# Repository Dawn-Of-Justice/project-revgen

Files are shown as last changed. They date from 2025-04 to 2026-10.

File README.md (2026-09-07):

# RevGen

A voice-controlled replacement for two remote controls, in Malayalam.

Built for a grandmother who knows perfectly well what the television and the
set-top box are — she just cannot tell which of the two remotes does what. She
presses one button, says what she wants, and hears a confirmation.

```
"TV ഓണാക്കുവോ? ഉം. and sound-ഉം കൂടെ കൂട്ടണേ കുറച്ച്."
   → tv.power, wait 2.5s, tv.volume_up ×2
   → "ടിവി ഓണാക്കി. ശബ്ദം കൂട്ടി."
```

That is a real transcript, not an illustration. Saaras handled the code-mixing,
the filler and the polite interrogative ending on the first attempt.

## Where it stands

| Phase | | |
|---|---|---|
| **0 — does it understand her?** | ✅ | Saaras + Sarvam-105B resolve her speech to the right two actions |
| **1 — emitter** | firmware written, protocol verified | needs hardware to flash |
| **2 — backend** | ✅ deployed | `project-revgen.fly.dev`, verified end to end in ~3.9s |
| **3 — handheld** | ✅ **working** | press, speak, understood, spoken reply. OTA updatable. |
| **4 — harden** | not started | enclosure, battery, undo, watchdogs |

The handheld works on real hardware: one press, hold to talk, release, and the
backend returns the right IR plan with a spoken Malayalam confirmation. It
updates over WiFi, so it stays fixable once it is sealed in a case.

**PCB A3 corrects the amplifier for component-side-up mounting.** See the
[correction record](pcb/remote/A3_CORRECTIONS.md). Owned-part fit and charging
measurements remain pending. Use A3 files; A2 is superseded and A1 was rejected.

The 120 x 45 mm rounded remote carrier PCB is routed, with Gerber/drill exports
and zero reported DRC/ERC violations. See [assembly and fabrication files](pcb/README.md). Charging components have not been tested on
the breadboard, and charging-related firmware behavior remains pending. First
charging tests are planned on the PCB prototype.

The emitter firmware is validated against `backend/tools/fake_emitter.py`, which
impersonates it over the real broker using the same validation rules. Physical
IR emission still needs hardware testing, as does the handheld charging path.

Two blockers, both waiting on parts:

- `stb.digit_1` is byte-identical to `channel_down`, a copy-paste bug inherited
  from v1. The backend refuses to fire it rather than changing the channel she
  did not ask for, so any channel containing a 1 is unavailable until the codes
  are recaptured with an IR receiver.
- Every channel number in `config/commands.json` is `null`, so `channel_set`
  correctly refuses everything. That one just needs five minutes with her
  set-top box.

## Layout

| Path | What it is | State |
|---|---|---|
| `backend/` | STT → intent → resolver → MQTT → TTS | **deployed**, 66 tests |
| `Dockerfile`, `fly.toml` | Deploy config, at the root because the image needs `config/` | live |
| `config/commands.json` | IR codes, channels, Malayalam phrases — single source of truth | needs her channel numbers |
| `firmware/selftest/` | Flash to any new board first: PSRAM, flash, WiFi survey | verified |
| `firmware/audiotest/` | Speaker bring-up: tones only, no network | verified |
| `firmware/capture/` | Phase 0 rig: recapture IR codes, sweep for discrete ones | written, untested on hardware |
| `firmware/emitter/` | IR blaster by the TV | written, untested on hardware |
| `firmware/remote/` | The handheld | **working on hardware** |
| `archive/v1/` | Superseded v1 code, kept for provenance | — |
| `docs/` | Pinouts, spec sheet, parts list | — |
| [`ARCHITECTURE.md`](ARCHITECTURE.md) | Why it is built this way, and what was rejected | — |
| [`docs/BOM.md`](docs/BOM.md) | Parts, with the specs that actually matter | ₹355 outstanding |
| [`docs/WIRING.md`](docs/WIRING.md) | Pin assignment, breadboard wiring, bring-up order | — |
| [`docs/PCB.md`](docs/PCB.md) | Carrier board: netlist, footprints, layout rules | routed; DRC/ERC pass; prototype files ready |
| [`docs/netlist.json`](docs/netlist.json) | Same netlist, machine-checkable against the schematic | 17 nets, 75 connections |

## Start here

```bash
cd backend
python -m venv .venv && source .venv/bin/activate   # Windows: .\.venv\Scripts\Activate.ps1
pip install -r requirements-dev.txt
pytest                      # 66 tests, no network or hardware needed
```

With a Sarvam key and broker credentials in `backend/.env`:

```bash
python tools/check_sarvam.py recordings/    # does it understand her?
python tools/fake_emitter.py                # stand in for the hardware
python tools/send_wav.py recordings/01_tv_on__power_on.m4a https://project-revgen.fly.dev/command
```

See [`backend/README.md`](backend/README.md) for the detail.

## Design in one paragraph

The language model never emits button presses — it returns *goals*
(`power_on`, `volume_up`) from a fixed vocabulary, and plain Python turns goals
into IR. That split exists because IR is open-loop and most buttons are toggles:
firing `tv.power` at a television that is already on turns it off, and no model
can know which case it is in. The safety rules that prevent that live in
`backend/app/resolver.py`, which has no I/O and is entirely unit tested.

## A note on secrets

This repo is public. A Groq key was committed in `.env` in April 2025 and had to
be revoked. Credentials now live in gitignored files — `backend/.env` and
`firmware/emitter/secrets.h` — with committed `.example` templates alongside.
Assume anything pushed here is scraped within minutes.

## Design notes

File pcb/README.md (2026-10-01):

# Remote carrier PCB — A3 prototype

> **A3 replaces A2 and rejected A1 files, correcting amplifier component-up mounting.** Mask openings, switch rating, amplifier protection and native schematic parity are corrected. Check owned-part fit before ordering; charging remains untested.

Completed **120 × 45 mm**, rounded R8, two-layer carrier for existing modules.
Fully routed: **0 DRC violations, 0 unconnected items, 0 ERC messages** under
project rules. All 79 logical pad assignments match the schematic.

- [Manufacturing ZIP](remote/RevGen-Remote-A3-Gerbers.zip)
- [KiCad project](remote/remote.kicad_pro), [PCB](remote/remote.kicad_pcb), [schematic](remote/remote.kicad_sch)
- [Assembly instructions](remote/ASSEMBLY.md)
- [A3 amplifier correction](remote/A3_CORRECTIONS.md)
- [Board preview](remote/artifacts/remote-top.png), [1:1 footprint drawing](remote/artifacts/assembly-1to1.svg), [schematic drawing](remote/artifacts/remote.svg)

Core remote operation was verified on breadboard. Charging hardware and charging
firmware remain untested. Compare the owned mic and button with the 1:1 drawing
before ordering; CAD checks do not establish their physical fit.
The separate 24 kHz playback compatibility finding remains open; see
[fresh review](remote/A2_FRESH_REVIEW.md).

The native schematic is authoritative. A2 adds R6 (2.2 kΩ), R7 (10 kΩ), and
a C&K 1101M2S3CQE2 switch. [Correction record](remote/A2_CORRECTIONS.md). Keep `revgen.pretty` and `fp-lib-table`
alongside the project. Superseded manufacturing archives, Trace drafts, routing
intermediates and one-off layout scripts have been removed. The correction and
review records remain as supporting documentation for A3. Final reports are
`artifacts/final-drc.json` and `artifacts/erc.txt`.

Validate from the repository root with KiCad 10 on PATH:

```powershell
kicad-cli sch export netlist --format kicadxml --output pcb/remote/artifacts/netlist.xml pcb/remote/remote.kicad_sch
python pcb/check_netlist.py pcb/remote/artifacts/netlist.xml
kicad-cli sch erc --output pcb/remote/artifacts/erc.txt pcb/remote/remote.kicad_sch
kicad-cli pcb drc --schematic-parity --format json --output pcb/remote/artifacts/final-drc.json pcb/remote/remote.kicad_pcb
& 'C:/Program Files/KiCad/10.0/bin/python.exe' pcb/check_board.py
```

Run `pcb/audit_preorder.py` with KiCad Python to check masks, full parity and
the A3 ZIP against current exports. `pcb/check_amplifier_orientation.py` checks
the module orientation against the retained manufacturer reference.
`pcb/package_a3.py` packages the checked native project and manufacturing exports;
it does not regenerate the layout.

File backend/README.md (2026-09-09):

# RevGen backend

Holds roughly 80% of the system's complexity so that both firmwares can stay
boring. That split is the direct lesson from v1, where the smartest component
was a microcontroller in someone else's house.

```
audio -> Saaras (STT) -> Sarvam-105B (intent) -> resolver -> MQTT -> ack -> Bulbul (cached)
```

**Status: deployed and verified end to end.** Live at
`project-revgen.fly.dev`, one machine in `bom`. A real recording of her voice
returns the correct IR sequence and a spoken Malayalam confirmation.

## Run it locally

```bash
cd backend
python -m venv .venv && source .venv/bin/activate
pip install -r requirements-dev.txt   # requirements.txt alone = runtime only
cp .env.example .env                  # Sarvam key + broker credentials
uvicorn app.main:app --reload
```

No key and no broker? `OFFLINE=true` runs the whole chain with stubs — enough to
check wiring and exercise the resolver.

## Tools

| Script | What it does |
|---|---|
| `tools/check_sarvam.py` | Batch-transcribes a folder of recordings and prints the resolved intents. Scores accuracy if files are named `01_tv_on__power_on.m4a`. |
| `tools/fake_emitter.py` | Impersonates the IR emitter over the real broker: validates commands with the same rules as the firmware, prints each step, publishes an ack. |
| `tools/test_emitter.py` | Tests a catalog button through the backend MQTT client, without speech APIs. Dry-run by default; `--execute` sends to the configured emitter. |
| `tools/send_wav.py` | Posts an audio file at the backend and plays the reply. Saves it as `reply.wav` in the current directory. |
| `tools/build_tts_cache.py` | Pre-generates every Malayalam phrase. Throttled to one request per 2.1s for the bulbul:v3 rate limit. |

## Testing without hardware

**1. Unit tests.** No network, no hardware:

```bash
pytest          # 66 tests
```

**2. Does it understand her?** The go/no-go on the whole premise:

```bash
python tools/check_sarvam.py recordings/
```

Target is 95% intent accuracy. Include three or four recordings with the TV
playing and no command spoken, named `__unknown` — refusing ambient speech is
the failure mode that decides whether this is usable in her living room.

**3. The full chain.** With `MQTT_*` set in `.env`, run the fake emitter in one
terminal and send a recording from another:

```bash
python tools/fake_emitter.py
python tools/send_wav.py recordings/01_tv_on__power_on.m4a https://project-revgen.fly.dev/command
```

The fake emitter prints the decoded IR steps and acks, so the backend returns
the real confirmation rather than `err.emitter_offline`. Everything except the
physical LED is proven at that point.

## Measured latency

Deployed instance, 155KB m4a from a laptop in Kerala:

| | ms |
|---|---|
| Server total | 1,732 |
| — MQTT round trip via Frankfurt | ~160 |
| Network (upload) | 2,158 |
| **End to end** | **3,890** |

Two things this settles. The EU broker costs ~160ms, not the ~500ms feared, so
self-hosting Mosquitto is not worth doing. And **upload dominates** — that test
file is mostly silence, and a tight 2–3s utterance (~96KB at the measured
72KB/s) lands near 3s. Stopping the recording on silence is therefore the
highest-value firmware behaviour, worth more than any backend optimisation.

## Deploy (Fly.io)

`Dockerfile` and `fly.toml` live at the **repo root**, not here — the image
needs `config/commands.json`, which sits outside `backend/` because the emitter
firmware reads the same file. All `fly` commands run from the repo root, since
that is where `fly.toml` is.

Already provisioned: app `project-revgen`, region `bom`, one machine, volume
`revgen_data` mounted at `/data`. Routine redeploy is just:

```bash
fly deploy
```

The backend now defaults to **32 kHz mono PCM16** replies. Both
[Bulbul v3 REST](https://docs.sarvam.ai/api-reference/text-to-speech/convert)
and the [MAX98357A](https://www.analog.com/media/en/technical-documentation/data-sheets/MAX98357A-MAX98357B.pdf)
support 32 kHz; the amplifier does not support the previous 24 kHz clock.
After deploying this change, run `fly ssh console -C "python tools/build_tts_cache.py"`
to warm the new cache before normal use. Settings-aware cache keys bypass old
clips automatically. Check for an existing `TTS_SAMPLE_RATE` environment/secret
override and change it to `32000` if present. Offline silence uses a separate
cache key and cannot replace production speech.

Deployment of this audio change is pending as of 2026-09-08. The production
voice-to-physical-emitter test passed with a synthetic English volume command;
the reply still measured 24 kHz. See
[the device validation log](../firmware/emitter/VALIDATION.md) for exact evidence.

Secrets currently set — `SARVAM_API_KEY`, `DEVICE_TOKEN`, `MQTT_HOST`,
`MQTT_USERNAME`, `MQTT_PASSWORD`. Non-secret config (`DATA_DIR`, `MQTT_PORT`,
`MQTT_TLS`) is in `fly.toml`. Each `fly secrets set` restarts the machine.

**`MQTT_HOST` must be a secret, not `fly.toml` config** — `fly.toml` is
committed to a public repo.

If rebuilding from scratch:

```bash
fly launch --no-deploy
fly volumes create revgen_data --region bom --size 1   # only after the app exists
# uncomment [[mounts]] in fly.toml
fly secrets set SARVAM_API_KEY=... MQTT_HOST=... MQTT_USERNAME=... MQTT_PASSWORD=... DEVICE_TOKEN=...
fly deploy
fly ssh console -C "python tools/build_tts_cache.py"
```

On Windows use one `fly secrets set` per line rather than backslash
continuations. Generate the token with
`python -c "import secrets;print(secrets.token_urlsafe(32))"`.

### Never scale past one machine

```
min_machines_running = 1       # keep it warm: a cold start hits the first
auto_stop_machines   = 'off'   # command of the morning, when she is least patient
```

The power debounce and the rate limiter both live in process memory. A second
machine keeps its own copies, so the rule that stops her repeated "TV on" from
switching the set back off silently stops working. Scaling out requires moving
`resolver.State` to a shared store first — it is the reason this is not on
serverless.

Fly's launcher created **two** machines despite `min_machines_running = 1`; that
had to be corrected with `fly scale count 1`. Worth re-checking after any
`fly launch`, which also rewrites `fly.toml` and strips its comments.

The volume holds the TTS cache and the utterance log, so both survive redeploys.
Without it every deploy regenerates ~20 phrases against the bulbul:v3 rate limit
and throws away the log needed to debug her problems from a distance.

## Layout

| File | Why it exists |
|---|---|
| `app/main.py` | The two endpoints. Every exit path returns audio, including failures. |
| `app/resolver.py` | Every rule that decides whether IR fires. Pure functions, no I/O. |
| `app/intent.py` | Forced tool calling, so the model cannot emit a command outside the vocabulary. |
| `app/catalog.py` | Refuses to fire codes flagged broken instead of silently sending the wrong one. |
| `app/emitter.py` | MQTT client. Waits for an ack; never assumes a published message arrived. |
| `app/ratelimit.py` | Spend guard. Bounds what a wedged client can cost overnight. |
| `app/audio.py` | Sniffs the container from its bytes, so phone recordings work unconverted. |
| `app/tts.py` | Bulbul with a disk cache. Concatenates clips for compound replies. |
| `app/logbook.py` | One JSON line per utterance. The alternative is debugging by phone. |
| `app/schemas.py` | The two wire contracts — remote↔backend and backend↔emitter. |

## Audio formats

The remote sends WAV. Everything else Saaras reads is accepted too — MP3,
M4A/MP4, AAC, OGG, OPUS, FLAC, AIFF, AMR, WMA, WebM — so voice memos work
unconverted.

Format is detected from the file header rather than the extension, because
iPhones write `.m4a`, Android tends toward `.mp3` or `.opus`, WhatsApp
re-encodes to `.ogg`, and multipart uploads often arrive named `blob`.

Nothing is transcoded. One caveat: Saaras works best at 16 kHz mono and phone
recordings are usually 44.1/48 kHz stereo. They transcribe fine, but if
`check_sarvam.py` accuracy looks worse than expected, rule this out before
blaming the model:

```bash
ffmpeg -i in.m4a -ar 16000 -ac 1 out.wav
```

## Things that look like details but are not

**`POWER_DEBOUNCE_S`** is the single most important setting. Power is a toggle,
so if she repeats "TV on" while the set is still waking up, the second command
undoes the first. Eight seconds of suppression removes the dominant real-world
failure. It stops mattering the moment `discrete.power_on` is filled in from the
Phase 0 sweep, and the resolver switches over on its own.

**The TTS cache is a latency mechanism, not a cost one.** Cached playback is
instant; a live Bulbul call would add most of a second to every reply.

**The instant acknowledgement is a local beep on the device, not this reply.**
Measured round trip is ~3s and upload dominates, so no backend work brings the
spoken confirmation under ~1.2s. Splitting the two — a beep the moment she stops
speaking, the Malayalam reply when it completes — answers the question she
actually has ("did it hear me?") at zero latency.

**Refusing is a feature.** The microphone sits in a room with a loud television,
so "this was not a command" is a common correct answer. The intent prompt
prefers `unknown` over a guess, and the resolver fires nothing on low confidence.

**`reasoning_effort` must be sent as an explicit `null`.** Sarvam defaults it to
`"medium"`, and omitting the key leaves reasoning switched on — which consumed
the entire token budget and returned an empty response with no tool call. That
looked exactly like the model failing to understand her, and cost ~1.3s per
request besides.

## Cost and limits

At 50 commands/day of ~4s each, against
[Sarvam's published rates](https://docs.sarvam.ai/api-reference-docs/pricing):

| | Rate | Monthly |
|---|---|---|
| Saaras STT | ₹30/hour, billed per second | ~₹50 |
| Sarvam-105B | ₹4 in / ₹16 out per 1M tokens | ~₹5 |
| Bulbul v3 | ₹30/10K chars | ~₹0 (cached) |
| **Total** | | **~₹55** |

Sarvam-30B is listed in the docs but rejected by the live API as deprecated, so
this runs on Sarvam-105B. The intent call is a few hundred tokens against
~₹50/month of audio, so the pricier model barely moves the total.

New accounts get ₹100 in credits. Rate limits on the Starter plan: 60 req/min
for STT, 40 req/min for Sarvam-105B, 30 req/min for bulbul:v3 — all far beyond
one household, but the TTS one is why `build_tts_cache.py` throttles itself.

**The spend guard** caps 20 requests/minute and 200/day. The minute limit
catches the realistic disaster — a firmware retry loop hammering `/command`
overnight — and the daily cap is the backstop, bounding a bad day at roughly ₹7.
Both sit above `file.read()`, so a throttled request never reaches Saaras.
Watch `requests.today` on `/health` climbing while nobody is using it; that is
what a wedged client looks like from outside.

## Learned IR commands

The emitter uploads named mappings on `revgen/emitter/learn`; the backend
validates and persists them to `DATA_DIR/learned_commands.json` before replying
on `revgen/emitter/learn_ack`. Grant both clients the corresponding broker ACLs.
The catalog and LLM prompt include accepted commands without restarting.
See [the learning guide](../docs/EMITTER_LEARNING.md) for rollout and limitations.

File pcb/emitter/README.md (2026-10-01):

# Emitter PCB — current B3

- `native-b3/emitter.kicad_pro`: KiCad project.
- `native-b3/emitter.kicad_pcb`: corrected PCB.
- `native-b3/emitter.kicad_sch`: matching schematic.
- `native-b3/emitter-pcb-top.png`: PCB preview.
- `emitter-B3-prototype-gerbers.zip`: current fabrication package.
- `native-b3/fabrication/`: identical unpacked Gerber/drill files.
- `native-b3/ASSEMBLY.md`: parts, orientation and physical checks.
- `native-b3/README.md`: layout and validation details.
- `revgen_emitter.pretty/`: required recovered 30-pin ESP32 footprint.

Keep the footprint directory alongside native-b3; the project's library table
uses a relative path to it. Superseded layouts and routing intermediates have
been removed. The original user-supplied archive outside this folder is untouched.

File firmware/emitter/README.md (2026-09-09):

# IR emitter

Stationary box on the TV cabinet. Subscribes to MQTT, fires IR, acknowledges.
Holds no IR codes — the backend sends complete descriptors, so new devices are
a server-side JSON edit rather than a trip to reflash hardware.

## Current development target (2026-09-08)

**Hardware correction:** the newly connected board was read over USB as
ESP32-D0WD-V3 revision 3.1, 4 MB flash, via CP2104 on COM8. This classic ESP32
is the current emitter. Select **ESP32 Dev Module**, 4 MB flash, PSRAM disabled;
IR is GPIO4 and status LED GPIO2 if fitted. The C3 below is the earlier recorded
choice and remains a supported alternative. Its GPIO8/USB-CDC settings do not
apply to the classic board.

Build the current board with `./firmware/emitter/check_build.ps1 -Target classic`.
Add `-UseSecrets` to compile the ignored real credentials for uploading. The
default build uses placeholders only. `backend/tools/check_emitter.py --probe`
tests broker status and a zero-delay ACK without emitting any IR.

The recorded owned board is **ESP32-C3 Super Mini**, per `docs/BOM.md` and
`docs/WIRING.md`; the ESP32-WROOM-32 is a spare. The historical lack-of-PSRAM
issue concerns audio recording on the handheld. The emitter processes a 2 KB
MQTT packet and a fixed 24-step sequence, so it does not require PSRAM. The
recorded −39 dBm WiFi result establishes signal reception at that test location,
not sustained MQTT/TLS operation. No logged C3-specific hardware failure was
found in the project notes inspected during this pass.

Select **ESP32C3 Dev Module**, **USB CDC On Boot: Enabled**, GPIO4 for IR and
GPIO8 for the active-low onboard LED. GPIO4 controls the transistor; it must
not directly supply the LED bank. The driver and real appliance response still
need bench testing. Keep the transistor pinout check in `docs/WIRING.md`.

The emitter now rejects malformed numeric fields, reports `busy` for a new
command during execution, and remembers the last eight accepted IDs for five
minutes to prevent duplicate QoS1 delivery from firing twice. This memory is
lost on reboot. Never publish retained commands; a command ID must be unique
and its payload immutable. ACK still means accepted, not appliance confirmed.
The backend does not automatically retry a timeout, because execution may
already have happened.

TLS now requires the broker's issuing root CA in `MQTT_CA_CERT` in `secrets.h`.
It verifies the server and synchronizes time using NTP. An empty CA is a
configuration error; no insecure TLS fallback is used. Existing secrets files
need the new field from `secrets.example.h`.

For a compile check with placeholder credentials (no flashing), run
`./firmware/emitter/check_build.ps1` from the repository root.

## Test the backend connection without speech

From `backend`, use the virtual environment with requirements-dev.txt installed:

```powershell
.venv/Scripts/python.exe tools/test_emitter.py tv volume_up
.venv/Scripts/python.exe tools/test_emitter.py tv volume_up --execute
```

The first prints the command only. The second uses the same MQTT client as the
backend, waits up to 15 seconds for online status, sends one catalog button and
waits for its acceptance ACK. Configure matching broker credentials/topics in
`backend/.env` and firmware `secrets.h` first. No STT/TTS API calls are made.
Do not run the fake emitter alongside real hardware on the same topics: either
could ACK and mask the other's failure.

After direct IR works, use the existing `/command` voice endpoint. Catalog
limitations still apply: STB digit 1 is flagged broken, and channel numbers
are placeholders. Recapture/configure these before testing channel selection.

## Libraries

Arduino Library Manager, board **ESP32C3 Dev Module** for the recorded emitter:

| Library | Min version |
|---|---|
| IRremote | 4.3 |
| PubSubClient | 2.8 |
| ArduinoJson | 7.0 |
| WiFiManager | 2.0 |

## Wiring

```
GPIO4 ──[1k]── base (2N2222A)
                collector ──┬─[100R]─ IR LED ─┐
                            ├─[100R]─ IR LED ─┤
                            ├─[100R]─ IR LED ─┼── 5V
                            └─[100R]─ IR LED ─┘
                emitter ── GND
```

One resistor **per LED**. LEDs don't current-share, so a single shared resistor
leaves one doing all the work while the others barely light.

Fan them across ~90°. Aiming is designed out of the system — she holds a
microphone, not a pointer, and this box never moves.

Mains USB, no battery. A stationary device with a battery is just a device that
eventually dies without warning.

## Broker

HiveMQ Cloud free tier, TLS on 8883.

**This repo is public**, so the cluster hostname and credentials live in
`secrets.h`, which is gitignored:

```bash
cp secrets.example.h secrets.h    # then fill it in
```

Create a credential under **Access Management → Credentials** with publish and
subscribe rights — the cluster URL alone will not authenticate. Use *separate*
credentials for the firmware and the backend, so revoking one does not take the
other down.

The backend's historical test recorded roughly 160 ms for the broker round
trip. Measure again on the real emitter connection; acceptance is acknowledged
before running the sequence so post-power delays do not consume the ACK timeout.

## First run

1. `cp secrets.example.h secrets.h` and fill in the cluster hostname, username,
   password and issuing root CA. Never commit it.
2. Flash. On first boot it opens a WiFi access point called **RevGen-Emitter** —
   join it and pick her network. Credentials persist; a router change means
   redoing this, not reflashing.
3. Watch the serial monitor at **115200**.

Status LED — GPIO2 on a classic ESP32, GPIO8 (active low) on a C3. Selected
automatically by `#if CONFIG_IDF_TARGET_ESP32C3`.

| Pattern | Meaning |
|---|---|
| Fast blink (2Hz) | No WiFi |
| Short pulse every second | WiFi up, no broker |
| Three quick flashes | Connected |
| Solid while firing | Executing a sequence |

On a C3, enable **USB CDC On Boot** in the IDE or there is no serial output.

## Learning mode

Hold GPIO27's button for five seconds, then open `http://revgen-emitter.local/`
on the same Wi-Fi. GPIO15 receives IR. Capture two separate matching presses,
test, name and save the command. See [the learning guide](../../docs/EMITTER_LEARNING.md)
for wiring, supported protocols, backend rollout and remaining hardware tests.

## Testing

The simplest check is to send a real command from the deployed backend and
watch the board react:

```bash
cd ../../backend
python tools/send_wav.py recordings/01_tv_on__power_on.m4a https://project-revgen.fly.dev/command
```

To publish a command by hand without the backend, use the Python stand-in
rather than installing Mosquitto — `backend/tools/fake_emitter.py` shows the
message format, and it reads credentials from `backend/.env`. It is also how
the wire protocol was verified before any hardware existed: it enforces the
same step count, delay ceiling and protocol whitelist as `parseSteps()` here,
so if it accepts a command this firmware will too.

Topics worth watching: `revgen/emitter/ack` for acknowledgements,
`revgen/emitter/status` for online/offline.

## Two things worth knowing

**`setBufferSize(2048)`.** PubSubClient defaults to 256 bytes and *silently
drops* anything larger. Channel digits and multi-step volume exceed that. This
is the most common way the integration appears to work and doesn't — the
backend publishes happily, the emitter simply never sees the message.

**The ack means "received and understood", not "the TV reacted".** It can't
mean the latter: IR is open-loop, so even after firing nothing tells us the
television saw it. The whole sequence is validated *before* acknowledging,
which is what makes that honest rather than optimistic — an unsupported
protocol or an over-long delay rejects the entire command instead of
half-executing it and leaving the TV somewhere nobody asked for.

Acking before execution also keeps inside the backend's 2.5s timeout. A
sequence with a 2.5s post-power wait takes longer than that to run, and she'd
otherwise be told it failed while it was still working.

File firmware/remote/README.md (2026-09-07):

# Handheld — Phase 3

The thing she holds. Press, speak, hear a Malayalam confirmation. Nothing else
to press.

```
wake on button
  -> beep         "I'm listening"      local, instant
  -> record to PSRAM, stop on silence
  -> beep         "got it"             local, instant
  -> POST the WAV to the backend
  -> play the reply                    Malayalam
  -> deep sleep
```

Board: **XIAO ESP32S3**, PSRAM verified at 8MB. Wiring in
[`docs/WIRING.md`](../../docs/WIRING.md).

## Setup

```bash
cp secrets.example.h secrets.h    # backend URL, device token, OTA password
```

Library Manager: **WiFiManager** (tzapu). Everything else ships with the core.

IDE settings:

| | |
|---|---|
| Board | XIAO_ESP32S3 |
| PSRAM | OPI PSRAM |
| USB CDC On Boot | Enabled |
| Partition Scheme | 8M with spiffs (3MB APP/1.5MB SPIFFS) — keeps OTA |

## It only records when the button wakes it

`setup()` runs on every boot — power-on, reset, and after every flash — not just
on a button press. Recording unconditionally meant a reconnected battery or a
power glitch would upload whatever the room happened to be saying, and once the
emitter exists that could switch her television on or off with nobody in the
room.

So it checks `esp_sleep_get_wakeup_cause()`. Only `ESP_SLEEP_WAKEUP_EXT0` — the
button — starts a recording. On a cold boot it plays a rising two-note chirp
("ready"), then sleeps armed. That doubles as useful feedback after charging.

**Holding the button through a cold boot overrides this**, which is how you
reach the WiFi portal and maintenance mode when standing next to it.

## The beeps

| Sound | Meaning |
|---|---|
| Rising two-note, 660→990Hz | Cold boot: ready and armed, going to sleep |
| Single 880Hz | Awake and listening |
| Single 1320Hz | Recording finished, working on it |
| Low two-tone, 400→300Hz | Something failed |
| Rising three-note | Maintenance mode, OTA open |

## The two beeps are not decoration

Measured round trip is ~3s and upload dominates, so no backend work brings the
spoken reply under about a second. The question she actually has is *"did it
hear me?"* — and a local beep answers that at zero latency.

Without it she repeats herself, and a repeated "TV on" toggles the television
back off. The beeps are the fix for the worst failure mode in the system. The
8-second debounce in the backend is the safety net behind them.

880Hz on wake, 1320Hz when the recording ends, and a low two-tone on any
failure. **Every failure path makes a sound** — silence is indistinguishable
from a dead device, and that is when she stops using it.

## Push to talk

**Hold the button, speak, let go.** Recording starts the instant it wakes —
there is no second press, and it does not wait for the network first. A 300ms
tail after release catches the last syllable, which people clip constantly by
letting go as they finish the word.

If the button is already up by the time recording starts — a quick tap, which
is what a short press looks like after ~300ms of boot — it falls back to
stopping on 1.2s of silence, so tap-and-speak still works.

Hard cap 6s either way. A stuck button should not upload six seconds of an
empty room repeatedly: Saaras is billed per second, and upload dominates the
round trip.

There is deliberately **no check that the button is still held at boot**. An
earlier version dismissed any press shorter than the ~300ms boot time as
spurious, which meant every normal press had to be made twice. The floating-pin
problem that check was guarding against is fixed properly at the source, by the
RTC pullup in `sleepNow()`.

## A second press cancels and starts over

Upload, download and playback together take about ten seconds. Locking her out
for all of it after a misspoken command is the kind of thing that makes a
device feel broken, so pressing the button again abandons the current attempt
and starts a fresh recording.

Every stage of the wait is interruptible, by one of two mechanisms:

| Stage | How |
|---|---|
| Upload (~7s) | button interrupt → `esp_restart()` |
| Download (~5s) | polled between reads |
| Playback (~3.5s) | polled between 2KB chunks |

**The upload reboots the device**, which sounds drastic and is the simplest
correct answer. `HTTPClient::POST` blocks for the entire request with no
callback to poll from — and it is the longest stage, so leaving it unresponsive
means most of the wait ignores her. Moving the network to its own FreeRTOS task
would work but brings shared state, teardown and a half-open TLS session to
clean up.

Nothing is worth preserving mid-upload: the recording is being abandoned by
definition, and the WiFi cache lives in RTC memory which survives a restart.
Boot back to a microphone is ~300ms, faster than the wait it replaces. An RTC
flag tells the next boot to skip straight to recording.

The interrupt is armed only around the blocking call, so playback keeps the
graceful chunked cancel rather than rebooting.

**Cancelling cannot un-fire IR.** If the backend already published to the
emitter, the television has already reacted — this skips the *wait*, not the
action. The backend's 8-second power debounce is what stops the resulting
second command undoing the first.

Detection is edge-triggered: the press that *ends* the recording is still
physically down when the upload begins, and would otherwise cancel itself
immediately. `armCancel()` requires the button to be seen released first.

## WiFi connects while she talks

The radio is kicked off *before* recording and waited on afterwards, so roughly
400ms of association disappears underneath two seconds of speech instead of
preceding it.

The channel, BSSID and leased IP are cached in RTC memory, which survives deep
sleep. That skips the all-channel scan and DHCP — about 1300ms down to under
400ms. It is only ever a cache: a moved router or an expired lease fails, falls
back to the full path, and refreshes itself. Three consecutive failures and the
cache is discarded.

## Loudness

She is hard of hearing, and a confirmation she cannot hear is the same as no
confirmation. Three independent levers, worth using all of them:

**Software — `BEEP_VOLUME` (0.85)** for the local tones, as a fraction of full
scale.

**Software — the spoken reply is normalised**, not scaled by a fixed amount.
Each clip is scanned for its loudest sample and lifted so that peak lands at
`PLAYBACK_PEAK`. Bulbul does not guarantee a consistent level between phrases,
so a fixed multiplier would either clip the loud ones or leave the quiet ones
inaudible. `MAX_NORMALISE_GAIN` caps it at 8x so a near-silent clip is not
amplified into hiss. The serial log prints `peak N -> gain N.NNx` so you can see
what each reply needed.

**Hardware — the MAX98357A `GAIN` pin**, which is free volume:

| GAIN connected to | Gain |
|---|---|
| VDD through 100kΩ | 3 dB |
| VDD | 6 dB |
| floating | 9 dB (default) |
| GND | 12 dB |
| GND through 100kΩ | **15 dB** |

Floating gives 9dB. A plain wire to GND gets you 12dB for nothing; 100kΩ to GND
gets 15dB and is the loudest the chip offers.

**Hardware — the speaker itself.** A 2W 40mm driver in a sealed printed
enclosure with a small port is dramatically louder than a bare driver flapping
on a breadboard. Do not judge final volume until it is mounted in the case.

If it is still not enough after all four, the honest answer is a bigger speaker
rather than more gain — past this point you are adding distortion, not volume.

## Microphone gain

`MIC_GAIN_BITS` is the first thing to tune on real speech.

The INMP441 gives 24-bit data left-justified in a 32-bit frame. Shifting right
by 8 yields the true sample; another 8 makes it plain 16-bit. `MIC_GAIN_BITS`
adds gain on top, with **saturation**.

v1 used a bare `>> 8`, which crammed a 24-bit value into an `int16_t` and
wrapped around on anything above a whisper. That is why its audio was unusable.
Start at 2. Raise if her recordings are quiet, lower if loud speech clips.

## Maintenance mode

**Hold the button while it wakes.** After WiFi connects it stays awake for five
minutes with OTA listening, LED slow-blinking, and plays a rising three-tone.

This exists because the device lives hours away. Every other part of the design
was built so problems can be fixed without a car journey — the utterance log,
the WiFi captive portal, the cloud backend — and firmware is no exception. Once
this is soldered into a case, OTA is the only way in.

### Uploading over WiFi

The Arduino IDE is supposed to show `revgen-remote` under **Network ports**, but
its mDNS discovery is unreliable on Windows even with the firewall opened. Skip
it and address the device directly:

```powershell
# Arduino IDE: Sketch > Export Compiled Binary  (Ctrl+Alt+S)
cd firmware\remote
.\ota_upload.ps1 -Ip 192.168.0.188 -Password <OTA_PASSWORD>
```

The script finds `espota` and the freshest `.bin` on its own, warns if the
binary is stale, and translates the usual failures.

If you do want discovery to work, it needs the network profile set to Private
plus inbound rules for UDP 5353, the IDE, and espota — all under the Private
profile. Even then it is flaky. The direct path always works.

## Reflashing over USB

Deep sleep powers down the XIAO's USB peripheral, so the COM port disappears
and the IDE has nothing to upload to.

**The firmware handles this itself now.** On a cold boot with a host holding
the serial port open, it stays awake for 15 seconds with the LED blinking fast
— plenty to hit Upload. On battery in her living room nothing has the port
open, so it sleeps immediately as intended.

Press RESET, then Upload while it is blinking.

**If it is already asleep**, force ROM download mode. The firmware does not run
at all in that state, so nothing can put it back to sleep:

1. Hold **B** (BOOT)
2. Press and release **R** (RESET)
3. Keep holding **B** another second, then release

Confirm it worked by the serial monitor showing *nothing* — no boot messages.
The COM port often changes number, so re-select it in Tools → Port before
uploading.

## Hardware verification status

The core remote operation has been compiled and verified on hardware. The carrier
PCB A2 has passed CAD checks; see `pcb/remote/A2_CORRECTIONS.md`. Charging components have not been tested on the
breadboard, and charging-related firmware behavior is still pending; first
charging tests are planned on the PCB prototype.

When changing ESP32 core versions, check the I2S API: this targets the legacy `driver/i2s.h`,
present in ESP32 core 2.x and still present but deprecated in 3.x. If your core
has removed it, migrate to `<ESP_I2S.h>` and the `I2SClass` wrapper — the logic
is unchanged, only the calls differ.

Bring up in the order in `docs/WIRING.md`: microphone alone first, then speaker
alone, then both. Wiring everything and flashing this tells you nothing about
which of six things is wrong.

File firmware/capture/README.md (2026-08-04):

# Capture rig — Phase 0

Reads codes off her existing remotes and prints them as paste-ready
`config/commands.json` entries.

Needs **three wires**: TSOP1838 OUT → GPIO, VCC → 3V3, GND → GND. No
transistor, no IR LED, no breadboard strictly required.

`IR_RECV_PIN` is GPIO15 on a classic ESP32, GPIO3 on a C3 — selected
automatically.

## Why this exists

Two problems in the inherited catalogue:

**`stb.digit_1` is byte-identical to `stb.channel_down`** (`0x798600DF`). A
copy-paste error from v1. The backend refuses to fire it rather than changing
the channel she did not ask for, so any channel containing a 1 is unavailable
until this is recaptured.

**`tv.apps` is malformed** — address `0x98` where every other TV button is
`0x8`, and a raw value with 11 hex digits where the others have 12.

## Capturing

```
name tv.power
```

then press that button on the remote. It prints the decoded code and the JSON
line to paste. Repeat for every button on both remotes.

```
  tv.power       Panasonic  addr=0x08 cmd=0x3D raw=0xBD3D00802002
  "tv.power": { "command": 61 },
```

**It warns on duplicates.** If a capture matches something already recorded
this session, it says so loudly — that is the exact bug that produced
`stb.digit_1`, caught while the remote is still in your hand rather than months
later when she asks for channel 21.

Other commands: `list` dumps everything as JSON, `clear` forgets the session,
`help` lists them.

The backend understands `panasonic` and `nec_raw` only. Anything else decodes
fine but gets flagged as unsupported.

## Sweeping for discrete power codes

This one needs the IR LED wired, same driver as the emitter.

```
sweep
```

Fires Panasonic address `0x8`, commands `0x00`–`0xFF`, one every 900ms, printing
each as it goes. **Film the television.** You will not remember which of 256
commands did what otherwise — match the video timestamps against the printed
list afterwards.

Manufacturers usually ship discrete power-on and power-off commands that are not
on the physical remote. If hers has them, put them in the `discrete` block for
the `tv` device in `config/commands.json`:

```json
"discrete": { "power_on": { "command": 62 }, "power_off": { "command": 63 } }
```

The resolver checks for them on its own. The moment they are present it stops
sending toggles, and the entire "she repeated herself and switched the TV back
off" problem disappears — along with the 8-second debounce that currently works
around it.

`sweep 0x30 0x50` narrows the range. Anything typed stops it early.

Worth also sweeping for discrete input-select codes while you are there, though
the current design never changes input.

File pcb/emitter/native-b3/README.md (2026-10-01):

# Emitter B3 — centered LEDs and side USB

Latest enclosure-oriented layout, 2026-09-09. Supersedes B2's placement while
preserving its electrical circuit. Created and routed through KiCad MCP with
Freerouting and local KiCad geometry/net verification helpers.

- Board remains 80 x 65 mm, 1.6 mm thick, two layers, 1 oz copper.
- Four LED body centers are at x=25,35,45,55 mm from the left edge and y=5 mm
  from the front edge. Their group is exactly centered on the board.
- ESP32 is rotated 90 degrees: USB toward the right side, antenna toward the
  copper-free left area. Its reserved module envelope meets the right edge.
  Header spacing remains 25.40 mm with 2.54 mm pin pitch. Pad 1 is lower left.
- The right-side USB centreline is nominally 40.3 mm from the front edge,
  assuming the connector is centered between header rows. Actual connector
  offset, projection, height, shell size and cable clearance are NOT measured.
  Measure these on the owned board before finalizing the printed case opening.
- Mounting holes: 3.2 mm, at (4,25), (4,60), (76,60) mm from the top-left corner.
- J1 is the learning receiver header: 1=3V3, 2=GND, 3=IR OUT to GPIO15.
  It is not a power input. Wire the receiver according to its actual pinout;
  select a part explicitly supporting 3.3 V operation. Provide an IR-transparent
  window or opening in the case for reception and transmission.
- SW1 remains the GPIO27 learning button. Provide access through the lid.

Final checks after audit fixes (2026-09-09): KiCad PCB DRC with all-track errors,
schematic parity, all severities and zone refill reports zero violations, zero
unconnected pads and zero schematic parity issues (`strict-drc.txt`). Schematic
ERC also reports zero errors and zero warnings. The custom library was upgraded
with KiCad's native symbol upgrader and its schematic cache refreshed; warnings
were fixed rather than excluded. Placement has no courtyard overlaps or boundary
violations. All 45 functional pads match the expected net map.

C2 is now at (110.5,73.3) mm, beside Q1 at (111,70), with a short local ground
connection and rerouted supply. PCB net names now exactly match schematic names,
including the leading slash. Description and Datasheet fields are synchronized.
The Gerber ZIP and preview were regenerated after these fixes.

Open `emitter.kicad_pcb`; `emitter-pcb-top.png` is the preview. `fabrication/`
holds B3 Gerbers and drill files. Use `../emitter-B3-prototype-gerbers.zip`
for this placement.

Component values, footprint dimensions and electrical precautions are unchanged;
see `ASSEMBLY.md`, with the orientations and mounting coordinates
above taking precedence. LED 3D models are generic upright placeholders. Form
outer LED leads outward and inner LEDs forward as the case requires; centered
placement alone does not establish IR coverage. USB power capacity, receiver
capture and physical replay remain untested on this revision. These physical
checks cannot be cleared through CAD: actual USB dimensions, VIN voltage under
USB power and receiver model/pinout are still needed from the owned hardware.

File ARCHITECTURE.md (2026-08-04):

# RevGen v2 — architecture

Replaces the v1 design. Kept separate from the README because the *reasoning*
matters more than the instructions: most of what follows is the record of ideas
that were tried and rejected, and re-deriving that later would be expensive.

**Target user:** an elderly Malayalam speaker who uses this daily, alone.
She knows the difference between the television and the set-top box; what she
cannot do is work out which of two remotes to pick up. That is the problem
being solved, and it drives everything below.

---

## 1. Three components, two interfaces

```
┌──────────────┐  HTTPS  ┌──────────────┐   MQTT   ┌──────────────┐
│  REMOTE      │ ──────▶ │  BACKEND     │ ───────▶ │  IR EMITTER  │
│  handheld    │  audio  │  Pi or cloud │   JSON   │  by the TV   │
│              │ ◀────── │              │ ◀─────── │              │
│ ESP32-S3     │  WAV    │ STT, intent, │   ack    │ ESP32        │
│ button, mic, │  reply  │ resolver,    │          │ 4x IR LED    │
│ speaker      │         │ TTS, logs    │          │ mains power  │
└──────────────┘         └──────────────┘          └──────────────┘
```

Only two boundaries exist, and if both are stable all three components can be
built independently and in any order:

| Interface | Contract |
|---|---|
| Remote → Backend | `POST /command`, multipart audio in, WAV out |
| Backend → Emitter | command sequence on `revgen/emitter/cmd`, `Ack` on `.../ack` |

Both are testable without the other side: `curl` a WAV at the backend,
`backend/tools/fake_emitter.py` at the broker in place of the hardware.

That last one matters more than it sounds. `fake_emitter.py` enforces the same
validation rules as the firmware — step count, delay ceiling, protocol
whitelist, refuse-the-whole-sequence-on-error — so it is a live check on the
wire contract rather than a passive viewer. Phase 2 was signed off against it
before any hardware existed.

**Roughly 80% of the complexity lives in the backend on purpose.** v1 stalled
because its smartest component was a microcontroller in someone else's house.
Smart firmware is firmware you cannot debug remotely.

**IR codes live in the backend, not the emitter.** The backend sends full
descriptors (`{protocol, address, command}`), so the emitter can stay dumb and
permanent. Adding her AC later means editing a JSON file, not reflashing a board
you would have to drive to.

---

## 2. The hard problem is not voice

It is that **IR is open-loop and most buttons are toggles.**

She says "TV on". The system fires `tv.power`. If the TV was already on, it just
turned it *off*. No amount of model quality fixes this, because the model is not
the ignorant part — the system is. There is no sensor anywhere in the loop, so
there is no information about physical state for any intelligence to reason over.

Three approaches were considered:

**Sense the room.** A photodiode on the screen, HDMI-CEC power queries, an
energy-monitoring plug. Genuinely solves it, and CEC in particular gives an
idempotent "turn on and switch to this input" via `<Image View On>` +
`<Active Source>`. Deferred, not rejected — see §6.

**Design the state away.** Leave the box permanently on, never change TV input,
so only TV power is stateful. Rejected: it assumes nobody else in the house ever
touches anything, which is false.

**Let her be the sensor.** Adopted. She only says "TV on" while looking at a TV
that is off. A person in front of the device is a better state sensor than
anything that could be taped to it.

### The failure that survives

Not unknown state — **impatient repetition**. She says "TV on", the set takes
three seconds to show a picture, she assumes it did not hear her, repeats, and
the second toggle undoes the first.

Two fixes, both nearly free:

1. **Acknowledge instantly, confirm when done.** Two sounds, not one:

   - **A local beep the moment she stops speaking**, generated on the device.
     Zero network, zero latency. This is what actually stops the repetition,
     because the thing she is uncertain about is whether it *heard* her.
   - **The Malayalam confirmation** when the round trip completes, telling her
     what was done.

   The original design put the whole burden on the spoken reply and set a 1.2s
   budget for it. Measured on the deployed backend that is not achievable:
   ~1.6s server-side plus upload, and upload does not shrink in production --
   six seconds of 16kHz mono WAV is 192KB, larger than a compressed phone
   recording of the same utterance.

   Splitting the two makes the hard number a firmware concern (a beep, which is
   free) and leaves the spoken reply on a soft ~3s target. The TTS cache still
   matters, but for the reply rather than the acknowledgement.
2. **Debounce power commands** for 8 seconds per device, and say
   "ഒന്ന് കാത്തിരിക്കൂ" instead of firing.

Both stop mattering the moment discrete power codes are found (§6), and the
resolver switches over on its own when they are.

---

## 3. The LLM does not emit buttons

An earlier draft had the model returning `["tv.power", "delay 2000", "stb.power"]`
directly. That is wrong: the correct button sequence depends on state the model
cannot see, so it would be *guessing* — the last place you want a probabilistic
component.

Instead the model returns **goals** from a fixed vocabulary
(`power_on`, `volume_up`, `channel_set`…), and `app/resolver.py` — pure Python,
no I/O — turns goals plus known state into a button sequence.

The split is not about trusting the model more or less. It is about putting the
model where ambiguity actually lives:

| | Handles |
|---|---|
| Saaras + Sarvam-105B | Malayalam, code-mixing, politeness, synonyms, rambling |
| Plain Python | timers, toggle safety, retry limits, whitelist validation |

"Was a power command sent in the last 8 seconds" is a timestamp subtraction. It
belongs nowhere near a language model.

Output is constrained by **forced tool calling** (`tool_choice` pinned to one
function), so the model cannot reply with prose or invent a command outside the
enum. Anything failing validation is discarded rather than repaired.

### Compound utterances are normal

The first real recording was:

```
"TV ഓണാക്കുവോ? ഉം. and sound-ഉം കൂടെ കൂട്ടണേ കുറച്ച്."
```

One breath, two requests, a filler, and a mid-sentence language switch. An
early schema allowed one action per utterance and the model correctly returned
`unknown` rather than dropping half of what she said. The schema now takes a
list, and the resolver:

- inserts a **2.5s wait after `power_on`** — a booting TV is not listening, and
  without the gap "turn it on and turn it up" silently never changes the volume;
- reports **partial success honestly** — if power is debounced but volume works,
  she hears about the volume rather than an apology;
- **bounds the action count** so a garbled transcript cannot become a burst.

---

## 4. Speech

`saaras:v3`, `mode=codemix`, `language_code=ml-IN`.

Codemix keeps English words in Latin script and Malayalam in native script,
which is exactly how she speaks and the form the intent model reads best.
Setting the language explicitly skips detection — faster, and one fewer failure
mode. If accuracy disappoints, `mode=transcribe` is the first thing to A/B; it
is the biggest single lever.

**Refusing is a feature.** The microphone sits in a room with a loud television,
so "this was not a command" is a common correct answer. The prompt prefers
`unknown` over a guess and the resolver fires nothing on low confidence.

---

## 5. Build order

Each phase ends in something testable. Do not move on until it works.

**0 — Prove the premise.** Record her on a phone, run
`backend/tools/check_sarvam.py`. If Saaras cannot handle her Malayalam nothing
downstream matters. Costs an evening. ✅ *Passed on first attempt.*

**1 — Emitter on MQTT.** `firmware/emitter/emitter.ino` already parses the
command grammar over serial; replace `Serial.readString()` with an MQTT
callback. An afternoon, using hardware you already own. Ends with: you control
the TV from a terminal.

**2 — Backend end to end.** ✅ *Done and deployed* (Fly, `bom`). A recorded
utterance returns `outcome=tv.power_on` with the correct five-step IR sequence
on the wire and a Malayalam confirmation spoken back. Verified against
`tools/fake_emitter.py`, which mirrors the firmware's validation rules.

Measured on the deployed instance, 155KB m4a from a laptop in Kerala:

| | ms |
|---|---|
| Server total (STT + intent + resolve + MQTT + ack + cached TTS) | 1,732 |
| — of which the MQTT round trip via Frankfurt | ~160 |
| Network (upload) | 2,158 |
| **End to end** | **3,890** |

Two things this settles. The EU broker costs ~160ms, not the ~500ms feared, so
self-hosting Mosquitto on the Fly machine is not worth doing. And **upload
dominates** — the 155KB test file is mostly silence, and a tight 2–3s utterance
(~96KB at the measured 72KB/s) lands the total near 3s. Stopping the recording
on silence is therefore the single highest-value firmware behaviour, worth more
than any backend optimisation.

**3 — Voice unit.** XIAO ESP32S3 (ESP32-S3, 8MB PSRAM, LiPo charging) on a
custom carrier PCB, in a 3D printed case shaped like a TV remote — roughly
160 × 60 × 28mm.

A custom board is not indulgence here, it is the robust option. Every joint on a
PCB is a connection that cannot work loose when the device hits a tiled floor,
and modules hand-wired into an off-the-shelf box have a dozen that can. The
printed case earns its keep by being a shape she already recognises: long enough
not to vanish down the side of a chair, thick enough to hold in the palm rather
than pinch between fingertips, which is the distinction arthritis makes matter.

PETG or ASA, never PLA — PLA is brittle on impact and creeps in Kerala heat. A
printed TPU sleeve provides what a commercial enclosure gets from overmoulding:
grip for unsteady hands, and corner impact absorption.

Weight sits at the bottom so it stands like a torch. The speaker fires out the
front face, never the back: a speaker pointed into a palm or a lap is a
confirmation she cannot hear, which defeats the entire latency argument above.
The microphone goes at the opposite end of the board from the speaker, because
otherwise it hears the confirmation and there is no software fix for that.
Charging is a magnetic USB-C tip left in the port permanently, so she never aims
a connector and the most mechanically fragile part never wears out.

One large button, centred where the thumb lands. Nothing else to press.

Build the board early even though the firmware comes last — two revisions at
2–3 weeks each is the realistic schedule, and that time runs in parallel with
everything else.

Last on purpose. By now it is the only unknown left. v1
failed partly because this was built first, and it is the component with the
least observable failure modes.

**4 — Harden.** Enclosure, battery warning by voice, WiFi loss handling,
watchdogs, undo.

---

## 6. Deferred, with reasons

**IR code recapture.** `archive/v1/signal.json` codes were captured from real
remotes and mostly work. `stb.digit_1` is provably a copy-paste of `channel_down`
and `tv.apps` is malformed. The catalog refuses both rather than firing them, so
this is not blocking — but any channel containing a 1 is unusable until a
TSOP1838 arrives.

**The discrete-code sweep.** While the receiver is wired up, sweep the whole
Panasonic command space (address `0x8`, commands `0x00`–`0xFF`) with a camera on
the TV rather than only capturing buttons that physically exist. Manufacturers
usually ship discrete power-on/off codes that are not on the remote. Fill them
into `config/commands.json` under `discrete` and the toggle problem disappears
entirely — the resolver detects them and stops debouncing.

**HDMI-CEC.** An ESP32 can speak CEC natively over 3 GPIOs at 3.3V. Tapped
between the box and the TV it inherits that port's physical address, so
`<Image View On>` + `<Active Source>` becomes an idempotent "turn on and show
the box". Needs VIERA Link enabled in the TV menu and an HDMI breakout. The
strongest available upgrade if the human-as-sensor approach proves insufficient.

**Screen photodiode.** Sampled over ~2s, variance distinguishes real content
(flickers) from a no-signal screen (static). Brand-agnostic, needs no CEC, and
measures the only thing she actually cares about: whether there is a picture.

---

## 7. Open questions

1. Her real channel numbers. `config/commands.json` has names but every number
   is `null`, so `channel_set` correctly refuses everything.
2. Other IR devices in the room — AC, fan, sound system?
3. Is WiFi reliable at both the sofa and the TV cabinet?
4. Does she use the original remotes? If so, a permanently-wired IR *receiver*
   in the emitter becomes worth building — it would keep state in sync and log
   what she actually presses.

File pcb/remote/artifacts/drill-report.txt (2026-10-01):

Drill report for remote.kicad_pcb
Created on 2026-09-07T22:25:18

Copper Layer Stackup:
    =============================================================
    L1 :  F.Cu                      front
    L2 :  B.Cu                      back

Drill file 'remote-PTH.drl' contains
    plated through holes:
    =============================================================
    T1  0.300mm  0.0118"  (24 holes))
    T2  0.700mm  0.0276"  (11 holes))
    T3  0.750mm  0.0295"  (4 holes))
    T4  0.800mm  0.0315"  (30 holes))
    T5  1.000mm  0.0394"  (27 holes))
    T6  1.100mm  0.0433"  (2 holes))
    T7  1.200mm  0.0472"  (4 holes))
    T8  1.850mm  0.0728"  (3 holes))

    Total plated holes count 105

Drill file 'remote-NPTH.drl' contains
    unplated through holes:
    =============================================================
    T1  1.800mm  0.0709"  (2 holes))
    T2  2.700mm  0.1063"  (4 holes))
    T3  3.200mm  0.1260"  (1 hole)

    Total unplated holes count 7

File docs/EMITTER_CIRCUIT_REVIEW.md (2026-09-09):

# Emitter circuit recovered from v1

**Update:** the original Gerbers have now been supplied. Their routing differs
from this PDF: see [Gerber recovery](EMITTER_GERBER_RECOVERY.md), which takes
precedence for the actual PCB. Header spacing is recovered; no ruler measurement
is needed to reproduce the original hole pattern. Findings below refer to the PDF.

Reviewed 2026-09-08. Source: `docs/revgen-transmitter.pdf`, revision 1.0,
2025-04-11, and `docs/assets/ESP32-Pinout(Transmitter).jpg.webp`.
Historical firmware: commit `4476c95`, `transmitter/transmitter.ino`,
and commit `fdbe8bb`, `firmware/emitter/emitter.ino`.

The user confirms this is the board/circuit previously used to control the TV,
with one physical wiring mistake. The PDF is a schematic, not PCB copper;
it cannot establish what was actually soldered or which trace was mistaken.
No editable emitter PCB or Gerber archive was found in the available Git history.

## Correct board reference

The original schematic and pinout image show a **30-pin development board**,
15 pins per side. The newly supplied NodeMCU-32S 38-pin PDFs are explicitly
rejected by the user as the wrong hardware. Do not use the footprint generated
from those PDFs. The old image establishes pin order but has no dimensioned
header spacing; do not infer an order-ready footprint from its aspect ratio.

With antenna up and USB down, component side visible:

| Row position from top | Left | Right |
|---:|---|---|
| 1 | EN | GPIO23 |
| 2 | GPIO36 / VP | GPIO22 |
| 3 | GPIO39 / VN | GPIO1 / TX0 |
| 4 | GPIO34 | GPIO3 / RX0 |
| 5 | GPIO35 | GPIO21 |
| 6 | GPIO32 | GPIO19 |
| 7 | GPIO33 | GPIO18 |
| 8 | GPIO25 | GPIO5 |
| 9 | GPIO26 | GPIO17 |
| 10 | GPIO27 | GPIO16 |
| 11 | GPIO14 | GPIO4 |
| 12 | GPIO12 | GPIO2 |
| 13 | GPIO13 | GPIO15 |
| 14 | GND | GND |
| 15 | VIN | 3V3 |

These are row positions, not bare-module pad numbers.

## Findings in the saved schematic

1. **LED U3 is reversed as drawn.** Its cathode bar faces R6/VIN;
   its anode faces Q2 collector. Correct current path is positive supply,
   resistor, LED anode, LED cathode, transistor collector, emitter, ground.
   A working assembled unit must differ from this drawing here, or its original
   symbol/footprint mapping differed. This is not proof of the user's physical fault.
2. **R3 pulls receiver OUT/GPIO13 to VIN (nominal USB 5 V).** ESP32
   signals must stay at 3.3 V logic. A receiver powered at 5 V may also source
   a high output itself; merely changing the external pull-up is insufficient
   without checking the exact receiver.
3. **C1, 100 nF, is across OUT and GND**, not receiver supply and ground.
   With R3=10 kohm it gives a 1 ms RC time constant that can distort decoded
   IR pulses. Move decoupling to receiver VS–GND.
4. **R4 pulls GPIO12/button to VIN.** Besides the 5 V logic problem,
   GPIO12 is a flash-voltage boot strap. A high level at reset can select
   1.8 V and prevent a 3.3 V flash board from booting. Move an optional user
   button to GPIO27, switch to GND, pull up to 3V3.
5. **Old IR firmware and schematic agree on GPIO5.** Current flashed firmware
   uses GPIO4. Reusing the old PCB unchanged with current firmware requires
   rerouting the base-resistor input from GPIO5 to GPIO4, or deliberately
   rebuilding firmware for GPIO5. This mismatch is not evidence that the
   original PCB had a GPIO error when running its original firmware.
6. **Q2 has no base-to-emitter pull-down.** Add 10 kohm so the driver is off
   while the MCU output is high impedance.
7. J1 is labelled "Speaker port", but carries VIN, GND and GPIO27. It is not
   an amplified speaker output. Omit it from the emitter carrier unless its
   original accessory is explicitly needed; never connect a bare speaker
   directly to this GPIO.

## Revised circuit specification

Preserve the original single-LED transistor driver, with conservative original
resistor values. Do not replace it with the later four-LED/100-ohm example.

- Existing ESP32 board powered through its USB connector.
- VIN/USB-derived 5 V -> R_LED 330 ohm, 0.25 W -> IR LED anode.
- IR LED cathode -> Q1 collector; Q1 emitter -> GND.
- GPIO4 -> R_BASE 1 kohm -> Q1 base. R_OFF 10 kohm from base to emitter/GND.
- Q1 design reference: onsemi **P2N2222A**, pins 1=C, 2=B, 3=E per its
  datasheet. Generic PN2222A/2N2222A substitutions can have different lead
  order: final footprint must match the owned part, not just the name "2222".
- Original LED reference: IR333C/H0-A. Retain 330 ohm pending exact variant
  verification. At an illustrative 5 V supply, 1.3 V LED drop and 0.2 V
  transistor drop, current is approximately 10.6 mA and resistor power 37 mW.
  This is a design estimate, not a measured range/current result.
- Add 100 nF ceramic and 47 uF / 10 V bulk capacitance across the driver supply,
  close to the driver. Keep pulsed LED current return separate from receiver
  signal wiring until the ground plane connection.
- Add labelled test points: VIN, GND, GPIO4 and collector.
- Optional button: GPIO27 -> switch -> GND, with 10 kohm to 3V3. Current
  production firmware does not implement this button; it is an optional
  expansion, not a working control until supported in firmware.
- Receiver is optional for capture, not required for MQTT emission. Provide
  a clearly labelled 3V3/GND/OUT header with OUT -> GPIO15 to match the current
  capture sketch. Only connect a receiver explicitly rated for 3.3 V supply
  and logic. Put 100 nF across its supply at the receiver. The old generic
  TSOP1838 designation does not establish its manufacturer or voltage limits;
  a 5 V-only receiver needs its own checked supply and output level conversion.

The revised GPIO4 choice matches the firmware already flashed and tested.
No board was reflashed or physically rewired during this review.

## Release status

Circuit corrections specified; PCB layout not released. Recover the original
EasyEDA layout or measure header spacing and body dimensions before routing a
replacement. Verify diode and transistor pad polarity against actual parts.
Then generate a readable native schematic, route the carrier, and run ERC,
DRC and schematic/PCB net parity before producing Gerbers.

References:
- [ESP32 boot straps](https://docs.espressif.com/projects/esptool/en/latest/esp32/advanced-topics/boot-mode-selection.html)
- [onsemi P2N2222A datasheet](https://www.onsemi.com/pdf/datasheet/p2n2222a-d.pdf)

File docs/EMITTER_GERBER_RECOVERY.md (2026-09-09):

# Original emitter Gerber recovery — 2026-09-08

Source: user-supplied `Gerber_revgen_PCB_revgen_2026-09-08.zip`.
Extracted under `pcb/emitter/original-gerbers`; original files are unmodified.
This archive supersedes the schematic PDF for evidence of fabricated routing.

## Geometry recovered

- Two copper layers; 30 ESP32 holes, 15 per row.
- Header pitch: 2.54 mm. Row spacing: **25.40 mm**.
- Header run: 35.56 mm between first and last pin centres.
- Original ESP32 drills: 0.915 mm.
- Original coordinates: x=21.336 through 56.896 mm;
  y=-18.034 and -43.434 mm.
- Outline extents: 78.867 x 62.992 mm. The left edge is slightly slanted:
  x=0 at the top and x=0.254 at the bottom; it is not an exact rectangle.
- Four 3 mm nonplated mounting holes.

Prepared `pcb/emitter/revgen_emitter.pretty/ESP32_30pin_recovered.kicad_mod`
with these header centres (rotated into antenna-up orientation). New pads are
1.8 mm with 1.0 mm drill, intentionally slightly larger than original drills.
Pin numbering is left top-to-bottom 1–15, right bottom-to-top 16–30,
matching the original pinout image. KiCad loads all 30 pads successfully.
This is a header footprint, not a finished carrier or full module courtyard.

## Copper findings

Top-side view has ESP32 USB to the left and antenna to the right, using the
original 30-pin pinout image as the mapping reference. Copper was traced using
Gerber line endpoints and plated-hole layer joins, then compared with the
rendered composite. This is not a complete fabrication DRC or short-circuit audit.

- **Transistor base via R4 routes to GPIO25**, not old firmware GPIO5 or
  current firmware GPIO4. This is a concrete hardware/software mismatch.
  User has not confirmed whether it was the historically repaired pin.
- Positive rail is **3V3**, feeding receiver supply, R1, R2 and R3.
  The previous PDF-derived 5 V pull-up finding does not describe this copper.
- Receiver OUT goes to **GPIO15**, with C1 across OUT/GND and R3 to 3V3.
  Current capture firmware GPIO15 therefore agrees with this PCB.
- R1 pulls **GPIO2** to 3V3, rather than GPIO12 as in the PDF.
  It connects to the button's wired side through a via. Avoid pulling GPIO2
  high externally because it participates in serial download boot selection.
- The connector labelled `IN(D27)` actually routes to **GPIO16**.
  Its VCC and GND labels do agree with 3V3 and ground.
- Transistor left pad routes to the LED pad marked `+`; centre pad to base
  resistor R4; right pad to ground. For P2N2222A C-B-E ordering, collector
  therefore reaches the LED anode marking. The other LED pad goes through R2
  to 3V3. Reverse the LED electrical assignment in the replacement design:
  anode toward supply resistor, cathode toward collector.

Gerbers do not record fitted resistor values, transistor identity, or later
hand-wired modifications. Do not transplant PDF reference/value assignments
blindly: reference names and pin connections differ between these revisions.

## Replacement design decisions

Use this 30-pin, 25.4 mm row-spacing geometry. Route the driver input to GPIO4
to match the firmware already flashed; leave GPIO5/GPIO25 unused for IR.
Keep receiver OUT on GPIO15, move C1 to its supply, and keep logic at 3V3.
Use GPIO27 for an optional button rather than GPIO2/GPIO12; button support
would still require firmware. Omit the misleading speaker connector unless
its accessory is required. Retain the conservative single-LED driver plan
in EMITTER_CIRCUIT_REVIEW.md, with explicit A/K and C/B/E pad assignments.

The old Gerbers are reference material, **not corrected manufacturing files**.
Native schematic reconstruction, routing and ERC/DRC/parity remain pending.

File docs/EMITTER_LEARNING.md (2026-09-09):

# Emitter learning mode

Implemented locally on 2026-09-08. This firmware and backend change has not
been flashed or deployed. Capture and appliance response still need hardware
testing; earlier backend-to-emitter tests do not validate learning.

## Wiring and use

The recovered classic ESP32 carrier uses GPIO4 for the IR driver, GPIO15 for
receiver OUT, and GPIO27 for the learning button. Connect the button to ground;
the revised schematic includes a 10k pull-up to 3.3V. The IR receiver and button
are required for learning. Use a receiver explicitly rated for 3.3V operation
and verify its actual pin order. Receiver power is 3.3V, with 100nF across its
supply and ground. The schematic's J1 pins are 1=3V3, 2=GND, 3=OUT.

1. Connect the emitter and phone/computer to the same Wi-Fi.
2. Hold the learning button for five seconds. The status LED blinks rapidly.
3. Open `http://revgen-emitter.local/`. If mDNS does not resolve, use the local
   IP address printed on the serial monitor. The firmware cannot automatically
   launch a browser on another device.
4. Enter a device ID/name and action ID/name. Use `tv` and `stb` for the primary
   devices, or IDs such as `bedroom_tv` for additional remotes.
5. Start capture. Press and release the original remote button twice, leaving
   a short pause between presses. Two matching valid frames are required.
6. Test the captured command and observe the appliance. A decoded signal or
   successful transmission alone cannot confirm that the appliance responded.
7. Save. The page distinguishes locally saved, upload pending, rejected and
   uploaded states. Repeat for other buttons/remotes. Saving the same device,
   action and kind replaces that mapping; changing its ID creates a new one.
8. Close learning mode from the page or hold the button again for five seconds.
   It also closes after five minutes without interaction or thirty minutes total.

Normal backend commands are rejected during learning to avoid interfering
with capture. Learning mode begins only after any pending sequence finishes.
The page is available only during a physically enabled session and requires a
session token and matching host. Anyone on that LAN who opens the enabled page
can configure it; this is not a separate account login. Wi-Fi is required.

## Names, channels and power

Learn primary STB keys as `digit_0` through `digit_9`. Then map a channel display
name to its channel number in the channel section. The backend sends the digit
sequence using its existing channel resolver. Channel aliases currently target
the primary `stb`, not arbitrary additional devices.

The backend gives the LLM the registered command keys and display names. It
accepts only a registered key and looks up the validated IR payload itself.
The LLM does not generate IR codes. Existing TV/STB actions use learned button
overrides; additional named actions use exact learned-command dispatch.

An ordinary power button must be marked `power_toggle`. Only use `power_on`
or `power_off` behavior for a genuinely discrete signal. Toggle transmissions
are debounced. IR remains open-loop: this cannot establish the appliance's
current power state. Additional-device toggle mappings are offered to the LLM
for explicit toggle requests, not as reliable on/off commands.

## Supported scope and persistence

- NEC/NEC2 32-bit and Panasonic 48-bit decoded commands matching the existing
  send protocol are supported. Unknown protocols and AC state frames are rejected.
- Up to 32 local command/channel records; actual NVS space can fill earlier.
  Storage failures are reported instead of pretending a save succeeded.
- Names allow 64 UTF-8 bytes on the emitter; IDs are lowercase letters, digits
  and underscores, start with a letter, and have at most 32 characters.
- Local NVS retains mappings and pending uploads across reset. Uploads retry
  every five seconds when connected, oldest first, until acknowledged.
- Backend storage is `DATA_DIR/learned_commands.json`, written atomically before
  acknowledgement, with up to 128 mappings and eight producer identities.
- Duplicate deliveries are acknowledged without reverting newer mappings.
  Stale sequences are rejected. Disk failures leave uploads pending for retry.
- Rejected records can be retried from the page; stale records need an edit and
  new save. There is no deletion or cross-emitter catalog download UI yet.

## Backend rollout

Deploy the matching backend before flashing the learning firmware. Preserve its
persistent data directory. MQTT ACLs must allow the emitter to publish
`revgen/emitter/learn` and subscribe to `revgen/emitter/learn_ack`; the backend
needs the reverse permissions. Both topics are non-retained. Existing command,
acknowledgement and status permissions are unchanged.

After deployment and flashing, verify two captures, physical test transmission,
local persistence after reboot, upload acknowledgement, backend persistence
after restart, and a voice request resolving the newly named action. These live
checks remain pending. Do not erase NVS during routine updates.

Local verification: backend regression suite, mocked browser UI tests and a
classic ESP32 compilation. Browser mocks test interface behavior, not electrical
capture or live MQTT permissions.

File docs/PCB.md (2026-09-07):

# Handheld carrier PCB

> **A3 corrects amplifier mounting for component-side-up assembly.** See [correction record](../pcb/remote/A3_CORRECTIONS.md); owned-part fit and charging tests remain pending.

A3 is a routed **120 × 45 mm remote-shaped board with R8 corners**, carrying
existing XIAO ESP32S3, INMP441 and Adafruit MAX98357A modules. The talk button is
central, microphone at top, amplifier/speaker connection at bottom.

See [deliverables and validation](../pcb/README.md) and the
[assembly guide](../pcb/remote/ASSEMBLY.md) for exact footprints, fabrication
files and physical-fit assumptions. The native schematic is organized on A3
with visible local wiring and named connections between sections.

Core operation was verified on breadboard. Charging components and charging
firmware remain untested; first charging tests are planned on this prototype.

## Connections

[netlist.json](netlist.json) is the complete machine-checked electrical spec:
17 nets, 75 connected terminals, four intentional no-connects. All 79 logical
PCB pad assignments match the schematic, including unused pins. Duplicate
physical pads on XIAO lands and the button have also been checked.

| Function | XIAO / GPIO | Destination |
|---|---|---|
| Mic clock | D8 / GPIO7 | SCK |
| Mic word select | D9 / GPIO8 | WS |
| Mic data | D10 / GPIO9 | SD |
| Amp clock | D0 / GPIO1 | BCLK |
| Amp word select | D1 / GPIO2 | LRC |
| Amp data | D2 / GPIO3 | DIN |
| Talk button | D3 / GPIO4 | Switch to ground |
| Amp shutdown/channel | D4 / GPIO5 | 2.2 kΩ series to Amp SD, 10 kΩ pull-down |
| Battery sense | D5 / GPIO6 | 1 MΩ / 1 MΩ divider with 100 nF filter |

J1 positive reaches VBAT_SW through SW2. This feeds XIAO underside B+,
amplifier VIN and the divider. Ground reaches B−. XIAO 3V3 powers the mic;
5V is unused. Mic L/R is grounded. R5 grounds amplifier GAIN; R1 is unpopulated.
Speaker outputs run from integrated module lands J5 to connector J2.
The switched divider consumes no battery current with SW2 off. C6 filters
its high-impedance ADC input. Test pads expose signals, power and ground.

## Layout and verification

Two layers, filled ground planes, 0.2 mm clearance, 0.25 mm signal tracks,
0.5 mm 3V3, 0.8 mm speaker and 1 mm battery supply tracks. Ground stitching
connects the planes. Keepouts provide module underside clearance and an
external antenna area. The mic has an acoustic opening; XIAO uses an external
IPEX antenna requiring suitable enclosure placement.

Final DRC: zero violations and zero unconnected items. ERC: zero messages
under project rules. Reports are `pcb/remote/artifacts/final-drc.json` and
`erc.txt`. These checks do not establish charging functionality or physical
fit. The manufacturing ZIP includes copper, masks, silkscreens, outline and
separate plated/non-plated drills. Keep the local footprint library with
KiCad source. Generator scripts reset layout; do not rerun over the final PCB.

A2 uses C&K 1101M2S3CQE2 (6 A at 28 VDC) for SW2. All plated pads have
solder-mask openings on both faces. Native schematic parity now passes.

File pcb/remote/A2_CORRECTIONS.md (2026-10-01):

# A2 correction record

A2 supersedes A1. The reviewed copper board has zero DRC violations, zero
unconnected items and zero full schematic-parity findings. ERC is zero.
The electrical specification matches 17 nets, 75 connected terminals and four
intentional no-connects. All 79 logical PCB terminals match that schematic.

| A1 finding | A2 correction |
|---|---|
| Missing solder-mask openings | Restored on all 81 physical plated pads, including duplicate pads; top and bottom mask Gerbers contain real apertures/artwork. Restored non-plated hole mask definitions to match source libraries. |
| 100 mA battery switch | Replaced with C&K 1101M2S3CQE2, rated 6 A at 28 VDC; new 4.70 mm pitch / 1.85 mm hole footprint. |
| Unprotected amplifier SD | Added R6 = 2.2 kΩ series and R7 = 10 kΩ pull-down. |
| Sleep shutdown not retained | Firmware uses RTC output hold, releases it before normal operation, and mutes before clock teardown. |
| Native schematic parity mismatch | Exact net names, footprint IDs, component metadata, no-connect nets and mechanical-only attributes synchronized. |

The board retains the 120 × 45 mm R8 outline and centered mic. New parts are
R6, R7 and the replacement switch. Do not substitute the A1 switch.

Final reports: `artifacts/final-drc.json`, `erc.txt`, `a2-fabrication-audit.json`.
The ZIP is compared byte-for-byte with exports and SHA256 hashes recorded.
`pcb/check_board.py` now requires solder-mask openings and full parity, unlike
the earlier connectivity-only check. `pcb/audit_preorder.py` verifies the mask
exports and the A2 archive. Final native KiCad source is authoritative; the
placement scripts intentionally reset routing and are not routine build steps.

Physical fit of the owned mic/button, XIAO rear solder access, charging current
and termination, and measured sleep current remain unverified. These are not
claimed as fixed by CAD checks. See ASSEMBLY.md for the 1:1 fit drawing and
bring-up procedure. A2 is a prototype design, not hardware-validated production.

## Firmware validation

Full compile and link passed with Arduino CLI 1.5.1, ESP32 core 3.3.11,
WiFiManager 2.0.17, XIAO ESP32S3, OPI PSRAM and USB CDC. Sketch uses
1,181,510 bytes (35%); globals 52,260 bytes (15%). Staged and current source
hashes match. Placeholder credentials were used; no board was flashed.
See `artifacts/firmware-validation.txt`.

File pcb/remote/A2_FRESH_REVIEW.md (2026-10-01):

# A2 fresh independent review — 2026-09-07

> Historical A2 findings. The amplifier orientation is corrected in A3;
> see A3_CORRECTIONS.md. The 24 kHz software finding remains open.

Read-only review of the released A2 design, with a fresh agent given limited context. No PCB, schematic, firmware or manufacturing archive was changed by this review.

## Disposition

Do not treat A2 as an unconditional drop-in production release. No additional confirmed electrical-routing defect was found, but amplifier mounting orientation and owned-module fit need resolution before ordering with confidence.

## Findings

### Amplifier requires component-side-down mounting

The A2 input row is LRC, BCLK, DIN, GAIN, SD, GND, VIN from left to right, with the speaker row below it. The original Adafruit module fits this arrangement with its components facing the carrier. The assembly instructions mention component clearance but do not explicitly state this orientation or establish a spacer height.

The manufacturer Eagle JP1 and X1 elements both have R180 rotation. Their transformed coordinates put VIN at +7.62 mm and speaker+ at (+1.7, +12.954) relative to the input-row center. Preserving these offsets in KiCad, whose vertical coordinate direction is opposite, reflects the mounting arrangement. For component-side-up mounting with the speaker row below the input row, the input order would instead be VIN, GND, SD, GAIN, DIN, BCLK, LRC, with speaker+ on the left.

The existing layout may work with deliberate flipped mounting and adequate clearance. It is not a verified fit for a module with conventional preinstalled headers. Either verify this arrangement against the owned module, or revise the footprint and routing for component-side-up mounting. Source: [Adafruit board files](https://github.com/adafruit/Adafruit-MAX98357-I2S-Amp-Breakout).

### Default TTS rate is outside the amplifier specification

`backend/app/config.py` requests 24000 Hz. The remote firmware reads the WAV rate and passes it directly to the amplifier I2S clock configuration. MAX98357A specifies 8, 16, 32, 44.1, 48, 88.2 and 96 kHz operation; 24 kHz is outside its specified bands.

Request a supported output rate or resample audio correctly. Merely changing the playback clock changes speed and pitch. Reported successful breadboard playback does not establish operation within specification. This is a software correction and does not itself require a PCB change. Source: [MAX98357A/B datasheet](https://www.analog.com/media/en/technical-documentation/data-sheets/MAX98357A-MAX98357B.pdf).

## Remaining physical validation

- Compare the owned microphone against the 100% scale layout: its 2.54 mm pitch and 7.62 mm row separation were inferred from imagery.
- Verify XIAO rear battery-pad access; raised headers require separate insulated battery leads as documented.
- Verify battery protection, permitted charge current, speaker rating and actual charging behavior. Charging components have not been breadboard tested.
- Test USB-only operation explicitly: SW2 disconnects the battery, while amplifier VIN remains connected to the XIAO charger/battery node.

## Checks passed

Full DRC, unconnected-item check, schematic parity and ERC report zero issues. All PTH pads have solder-mask openings. GPIO mappings match the plain XIAO ESP32S3 and firmware. The microphone channel selection and amplifier shutdown network are consistent. All ten manufacturing ZIP entries match the export directory byte for byte; the source archive and release hashes also match. The outline is 120 × 45 mm with R8 corners.

These are CAD and source checks, not assembled hardware validation.

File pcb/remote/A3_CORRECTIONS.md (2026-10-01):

# A3 amplifier orientation correction

A2's amplifier footprint required component-side-down assembly. A3 mirrors the
physical X positions of U3 and J5 pads so the original Adafruit MAX98357A mono
breakout mounts with its components facing up and its speaker row toward the
bottom of the remote. Net identities are unchanged; affected copper is rerouted.

Input order from left to right is VIN, GND, SD, GAIN, DIN, BCLK, LRC. Speaker+
is 1.7 mm left of the module center and speaker− is 1.8 mm right. The speaker
row remains 12.954 mm below the input row. These positions account for both
R180 element rotations in the manufacturer Eagle file and the opposite Y axes
of Eagle and KiCad. The footprint generator is corrected too.

Source: [Adafruit original board files](https://github.com/adafruit/Adafruit-MAX98357-I2S-Amp-Breakout).

A3 supersedes A2 manufacturing files. Earlier files are retained as history.
The microphone fit and charging hardware remain unverified physically. The
24 kHz playback finding in A2_FRESH_REVIEW.md is a separate, open software issue.

Validation: full DRC, unrouted connections, schematic parity and ERC all report
zero issues. All 79 logical pad assignments match the schematic. A separate
geometry check compares all nine amplifier pads with transformed manufacturer
Eagle coordinates; all match. Battery traces remain at least 1 mm and speaker
traces at least 0.8 mm. PTH solder-mask openings are present. The top render was
visually inspected, including the corrected labels and AMP CHIP UP marking.

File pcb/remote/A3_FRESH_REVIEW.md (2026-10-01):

# A3 fresh independent review — 2026-09-07

Requested final review by a new agent with limited context. Design and firmware
were inspected read-only; neither was changed. No demonstrated A3 PCB order
blocker or new confirmed electrical defect was found. This is a CAD/source
assessment, not assembled hardware validation.

## Open software finding

The backend defaults to 24000 Hz (`backend/app/config.py:40`), requests that
rate in `backend/app/tts.py:112`, and the remote passes the returned WAV rate
directly to I2S (`firmware/remote/remote.ino:752`). MAX98357A excludes 24 kHz
from its specified rates. Correct generation or resample audio, including
existing cached WAVs, before functional release. Changing WAV metadata alone
changes speed and pitch. No PCB change is required for this finding.

Source: [MAX98357A/B datasheet, page 19](https://www.analog.com/media/en/technical-documentation/data-sheets/MAX98357A-MAX98357B.pdf).

## Physical and charging limits

- The microphone's nominal 2.54 mm pitch, 7.62 mm row spacing and centered
  acoustic opening still need comparison with the owned module. No actual
  mismatch was demonstrated. Check the exact button and switch too.
- XIAO rear solder access needs assembly validation. Raised headers require
  separate insulated battery leads as described in ASSEMBLY.md.
- Connectivity is J1+ through SW2 to XIAO B+ and amplifier VIN, with B− at
  ground and XIAO 5V isolated. Charging requires SW2 on. With SW2 off, USB can
  power the MCU while the battery is disconnected.
- The amplifier loads the battery/charger node. Idle charging, termination,
  USB-only behavior and active playback require prototype measurements.
  No charging defect was demonstrated. Cell protection, allowable charging
  current and polarity remain assembly requirements.

Source: [Seeed XIAO ESP32S3 instructions](https://wiki.seeedstudio.com/xiao_esp32s3_getting_started/).

## Independent checks

- Actual PCB pad/net membership matches docs/netlist.json with zero differences.
- An independent transform of the original Adafruit Eagle JP1/X1 geometry
  matches all nine A3 amplifier connections for component-up assembly.
  With the input row above the speaker row, input order is VIN, GND, SD,
  GAIN, DIN, BCLK, LRC. Speaker+ is left at (120.8, 153.954) mm and speaker−
  right at (124.3, 153.954) mm in board coordinates.
- Board contour is 120 × 45 mm with rounded corners. Microphone and amplifier
  signal groups, battery divider, differential speaker connections and gain
  selection were checked.
- The SD resistor network supports default shutdown and driven left-channel
  selection. Firmware mutes before removing I2S clocks and holds SD low through
  deep sleep.

Source: [Adafruit original board files](https://github.com/adafruit/Adafruit-MAX98357-I2S-Amp-Breakout), also retained in sources/adafruit-max98357.brd.

## Parent verification alongside the independent agent

A fresh KiCad DRC with zone refill reports zero violations, zero unconnected
items and zero schematic parity mismatches (artifacts/a3-independent-drc.json).
All 79 logical pads match the schematic. PTH mask openings are present. Battery
and speaker trace widths meet the intended 1 mm and 0.8 mm minimums.
All release manifest hashes, source ZIP entries and fabrication ZIP entries
match current files. The board SHA-256 is
`ccacc02e2b2d3712b67a74642d75926f3c7b05e21c09729e8ec59687a4304513`.

This review did not perform physical measurements, enclosure checks, firmware
compilation or live audio/charging tests. Existing A3 archives are unchanged.

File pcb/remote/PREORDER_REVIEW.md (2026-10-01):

# A1 pre-order review — historical rejection

**Resolution:** A2 corrects the design defects below. See [A2_CORRECTIONS.md](A2_CORRECTIONS.md). This report remains evidence for rejecting A1.

Reviewed 2026-09-07 by the main agent and an independent agent given limited
context. This review supersedes earlier statements that A1 was ready to order.
No electrical layout or firmware changes were made during this audit.

## Findings requiring correction before fabrication

1. **P1: Missing solder-mask openings.** All 79 plated through-hole physical
   pads across 33 electrical footprints omit F.Mask and B.Mask. This includes
   module connections, passives, connectors and switch mounting tabs. The
   exported `manufacturing/remote-B_Mask.gbs` contains no apertures or artwork.
   Restore explicit openings in board and library/generator sources, export
   again and inspect the actual Gerbers. The copper continuity check does not
   test solderability. Evidence: `artifacts/preorder-fabrication-audit.json`.
2. **P1: SW2 cannot be approved at the selected rating.** OS102011MS2Q-family
   contacts are rated 0.1 A at 12 VDC. Here the switch carries the combined
   XIAO and amplifier battery current, which can exceed that rating. Select
   a suitably rated switch and matching footprint, or a rated power stage
   controlled by the switch. Do not assume a lower battery voltage permits
   proportionally higher contact current. [Manufacturer datasheet, page 3](https://www.littelfuse.com/assetdocs/littelfuse-ck-slide-os-series-datasheet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).
3. **P1: Direct AMP_SD drive lacks low-supply protection.** GPIO5 drives
   amplifier SD directly; the Adafruit module has no series resistor here.
   The manufacturer calls for approximately 2 kilohms in series when the
   amplifier supply can fall below 3 V while control logic is 3.3 V. USB with
   the battery disconnected or SW2 off is a relevant state: the XIAO remains
   powered while the amplifier loads the limited charger BAT output. Cold
   boot attempts a beep. Add protection and validate rail behavior; actual
   voltage collapse has not been measured. [MAX98357A datasheet, page 17](https://www.analog.com/media/en/technical-documentation/data-sheets/MAX98357A-MAX98357B.pdf).

## Firmware and assembly issues

- **P2: Amplifier shutdown is not explicitly retained during deep sleep.**
  `ampStop()` drives GPIO5 low using normal GPIO, but `sleepNow()` establishes
  no output hold. The breakout pull-up can release shutdown. With clocks
  absent, typical amplifier standby is about 340 microamps, versus roughly
  0.6 microamps in shutdown. Add retained shutdown or appropriate hardware
  bias, and measure sleep current. This is a firmware correction as well as
  a battery-life verification item, not a proven PCB routing failure.
  [Espressif GPIO hold documentation](https://docs.espressif.com/projects/esp-idf/en/stable/esp32s3/api-reference/peripherals/gpio.html).
- **Mic and button physical fit remains unverified.** Mic 2.54 mm pin pitch
  and 7.62 mm row spacing were inferred. Compare the owned mic and button
  with the 1:1 drawing before committing to these footprints.
- **XIAO rear battery solder access is unproven.** Raised headers need two
  short battery leads. CAD alone does not verify flush mounting clearance
  or reliable rear-access solder joints.
- **Charging works autonomously in the XIAO charger**, but has not been
  tested in this assembly. No charging firmware is required merely to start
  charging. Amplifier load is on the charger BAT rail, so charging speed and
  termination during playback must be checked. Identify the owned XIAO
  revision before assigning an exact charge-current value; current Seeed
  documentation and schematic list differing values.

## What passed, and what those checks mean

Fresh ERC: zero findings under project rules. Copper DRC: zero violations
and zero unrouted connections. Fresh schematic export matches the electrical
spec (16 nets, 71 connections, four no-connects). PCB logical assignments
match all 75 schematic terminals. Firmware GPIO assignments agree with the
circuit. Adafruit input order, speaker-pair spacing and polarity match the
copied official board. XIAO battery polarity agrees with Seeed documentation.
The fabrication ZIP matches the current exports byte for byte.

Full KiCad schematic parity nevertheless reports 173 items: 91 net-name
conflicts, 45 footprint/symbol mismatches, 33 field mismatches, four extra
mounting footprints. Inspected examples include removed leading slashes on
net names and missing footprint library nicknames. Canonical connectivity
matching does not excuse these: normalize metadata and intentional mounting
exclusions so native updates/checks are dependable, then rerun full parity.

Run `pcb/audit_preorder.py` using KiCad Python for mask, archive and full-parity
checks. It currently exits nonzero as expected. Prior `check_board.py` checked
connectivity and file terminators, not manufacturing readiness; its pass is
not sufficient for ordering.

**Decision: do not order the existing A1 Gerber ZIP.** Correct the three P1
items, settle physical-fit assumptions, and regenerate/review fabrication
files before releasing a replacement. Charging and sleep-current measurements
remain prototype bring-up work after those design corrections.

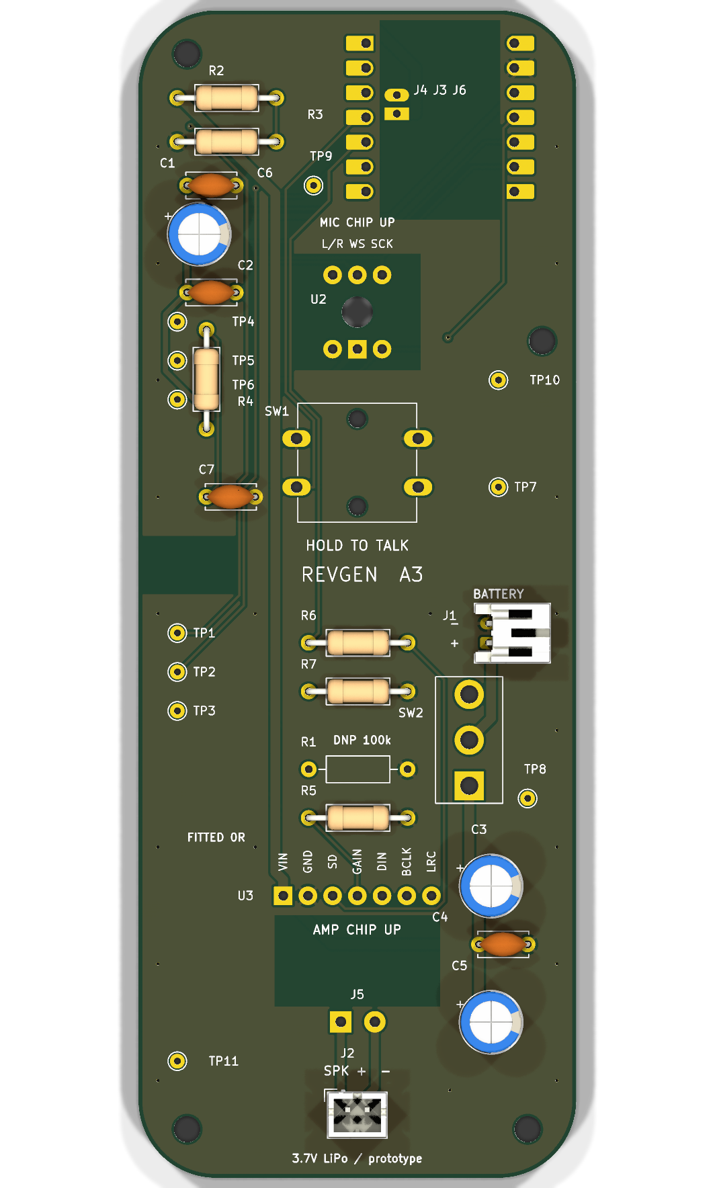
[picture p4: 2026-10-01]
pcb/remote/artifacts/remote-top.png

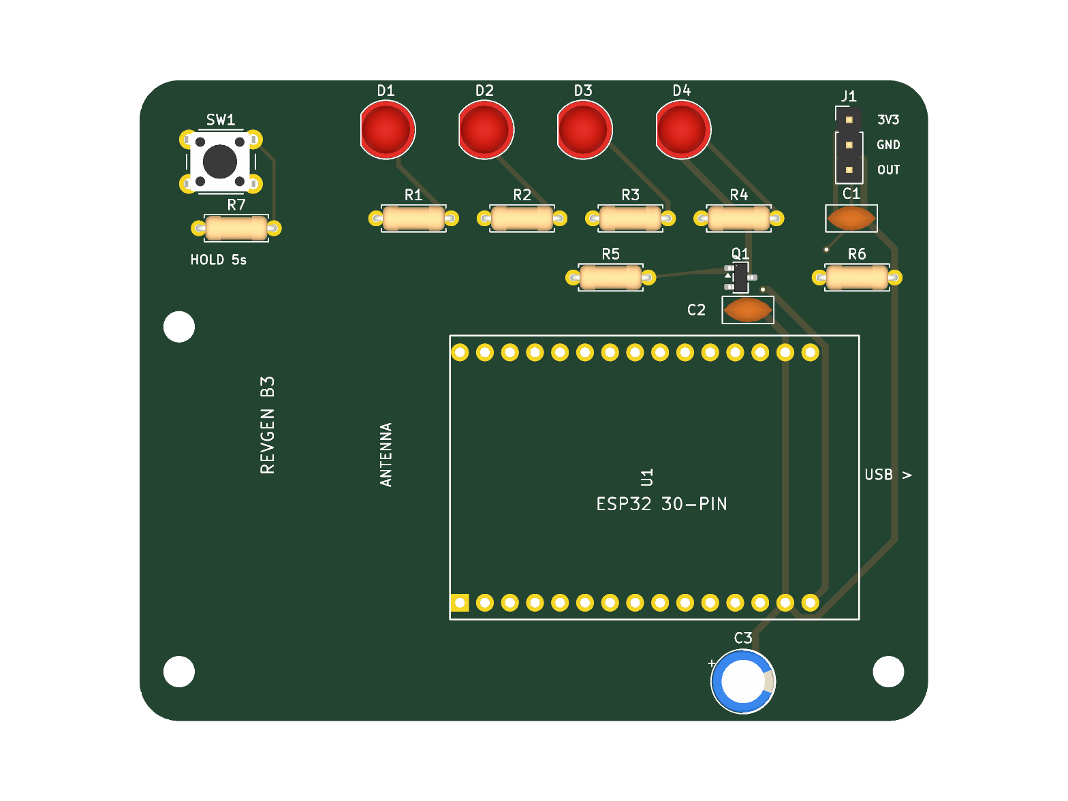
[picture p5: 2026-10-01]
pcb/emitter/native-b3/emitter-pcb-top.png

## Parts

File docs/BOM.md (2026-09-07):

# Parts

Prices are approximate (Aug 2026, INR) and vary by seller — treat them as
"roughly what this should cost", not a quote. [Robu.in](https://robu.in),
[Robocraze](https://robocraze.com), [Probots](https://probots.co.in),
[Hubtronics](https://hubtronics.in) and Amazon.in stock everything here.

## Already owned

IR receiver, IR LED, 100Ω + 1kΩ resistors, digital microphone, tactile button,
3.7V cell.

Boards on hand:

| Board | PSRAM | Role |
|---|---|---|
| ESP32-C3 Super Mini | none | Previously recorded emitter choice; historical WiFi result −39 dBm |
| **Classic ESP32 (D0WD-V3, 4MB flash)** | none — previously confirmed 0 bytes | **Current emitter**, chip and flash identified over USB on 2026-09-08 |

The WROOM-32 was checked for PSRAM in case it was a WROVER, which would have
served as the voice unit and removed the XIAO from the list. It reported 0, so
that shortcut is out.

The connected emitter was identified as ESP32-D0WD-V3 revision 3.1 through a
CP2104 USB bridge on COM8. Both boards can handle the emitter workload; PSRAM
is not required. Use **ESP32 Dev Module**, 4 MB flash, PSRAM disabled for the
current classic board. IR drive remains GPIO4; status LED is GPIO2 if fitted.

The C3 uses different pins to a classic ESP32 (onboard LED on GPIO8, active
low). `firmware/emitter/emitter.ino` handles both with
`#if CONFIG_IDF_TARGET_ESP32C3` — no edits needed, just pick the right board in
the IDE, and enable **USB CDC On Boot** or the C3 gives no serial output.

## Ordered — ₹355

Everything needed to finish Phase 0 and Phase 1 on boards already owned: IR
codes recaptured, and a television controlled from a terminal.

| Part | Qty | ~₹ |
|---|---|---|
| 2N2222A NPN transistor | 5 | 25 |
| Breadboard 830-point | 2 | 180 |
| Jumper wires M-M + M-F | 1 set | 150 |

## Buy later — voice unit, ~₹1,600

Phase 3, and not before. It is the component with the least observable
failures, and building it before the things it talks to exist is how v1 died.
Nothing here is needed to reach a working, TV-controlling system.

| Part | Qty | ~₹ |
|---|---|---|
| **Seeed XIAO ESP32S3** (plain, *not* Sense) | 1 | 1,200 |
| MAX98357A I2S amplifier | 1 | 250 |
| Speaker 8Ω **2W** 40mm | 1 | 150 |

Deliberately absent: battery and charging (USB powers a breadboard), RGB LED
(both boards have one, and serial is a better debugger), power switch,
enclosure, PCB. None of it teaches you whether the idea works.

## Verify before relying on the parts already in the box

Three fail silently if they are the wrong variant:

- **IR LED wavelength — must be 940nm.** 850nm LEDs look identical, glow
  faintly visible red when driven, and most receivers ignore them. Point a
  phone camera at it while firing: both show up on camera, but a dull red glow
  visible to the naked eye means 850nm.
- **Microphone must be digital I2S** — pins marked SCK/WS/SD, like an INMP441.
  An analog electret module (pins marked A0 or OUT) will not work with this
  firmware and is far noisier. Replace rather than adapt.
- **IR receiver must be 38kHz.** TSOP**18**38 / 1738 / 4838 are all fine. A
  TSOP**12**40 or anything marked 40kHz will miss most of her remotes.

Also check the **cell**: confirm it has a protection board and a JST-PH lead
rather than bare tabs. If it is an 18650 rather than a flat pouch it still
works, but it is cylindrical and heavy, which affects the case, and the XIAO's
onboard charger is low-current so a large cell takes most of a day to fill.

---

# Later: the finished device

Everything below is for after the breadboard prototype works. None of it is
urgent, and some of it will change once there is something real to hold.

## Why the XIAO ESP32S3

Three routes were considered in Aug 2026:

| Route | ~₹ | Verdict |
|---|---|---|
| ESP32-S3-DevKitC-1 N16R8 + INMP441 + TP4056 | 1,060 | Cheapest, but a wide board that covers most of a breadboard and dictates the case dimensions. |
| XIAO ESP32S3 **Sense** + amp | 2,200 | Mic built in — but on a stacked expansion board, which is redundant height and cost once your own PCB carries an INMP441. |
| **XIAO ESP32S3 (plain)** | 1,200 | Chosen. PSRAM and LiPo charging on a 21×17.5mm module. |

The Sense only wins when you are *not* making a PCB. Its selling point is the
integrated microphone, and this design places its own.

**Against the XIAO:** 11 usable GPIOs (enough — I2S in, I2S out, button, LED),
and castellated pads mean soldering rather than pushing into a breadboard. It
needs the little IPEX antenna from the box plugged in, and **USB CDC On Boot**
enabled in the IDE.

### Whatever the board, it must have PSRAM

The single most important spec in the project, and the direct fix for why v1
died. The old firmware streamed raw audio over a TLS WebSocket because it could
not hold a recording in memory. With PSRAM, buffering 6 seconds of 16kHz WAV
(~192KB) is trivial and record-then-upload becomes easy.

The XIAO ESP32S3 has 8MB in both plain and Sense variants. If falling back to a
DevKitC it must say **N16R8** or **N8R8** — a plain N8 or N16 with no `R` has
none, and listings often do not mention it.

### Not worth switching to

**ESP32-P4** is newer and much faster but has **no WiFi or Bluetooth** — a
non-starter for a device whose entire job is uploading audio.

**ESP32-C3 / C6 / C5** have no PSRAM. The C3 is a fine *emitter* — that is what
this project uses one for — but 400KB of SRAM cannot hold a recording alongside
a TLS connection, which is exactly the corner v1 painted itself into.

The ESP32-S3 remains the right chip for the handheld in 2026.

## PCB

**Carrier board, not a bare ESP32-S3.** Keep the XIAO as a module soldered onto
castellated pads. Designing a bare S3 with USB, power management and antenna
matching is a lot of ways for a first board to fail; a carrier means a mistake
costs a reroute rather than a dead board, and the module stays replaceable.

**EasyEDA** if this is your first board — free, and orders straight from JLCPCB
with footprints already in their library. KiCad if you want the skill to
transfer.

On the board: XIAO footprint, INMP441, MAX98357A, button, RGB LED, JST-PH
battery connector, speaker pads.

Things that catch people out:

- **Put the INMP441 at the opposite end from the speaker**, or it picks up the
  confirmation audio and the amplifier's switching noise. Physical distance is
  the fix; there is no software one.
- Ground pour under the digital section, and keep the I2S clock lines short.
- **Test pads** on I2S clock/data, the button line and battery voltage. You will
  want them at 11pm when it does not boot.
- **Pick the button before routing.** Order several types, let her press them,
  then commit the footprint. It is the one part she physically interacts with.
- Order 5 boards. They cost almost nothing; shipping is the expense.

Budget 2–3 weeks per revision including shipping to India, and expect two. Worth
starting early even though the firmware is Phase 3, since that lead time runs in
parallel.

## Case

A familiar TV-remote silhouette but chunkier — roughly **160 × 60 × 28mm**. Long
enough not to vanish down the side of a chair, thick enough to grip in the palm
rather than pinch between fingertips. Pinching is what arthritis makes hard.

**Print in PETG or ASA, not PLA.** PLA is brittle on impact and creeps in heat;
a remote left on a sunny windowsill in Kerala will soften and warp.

- **Walls ≥ 2.4mm**, and orient the print so layer lines run *across* the case.
  Layer adhesion is the weak axis and drops load the corners.
- **Print a TPU sleeve** to slip over the body. That is what replaces the soft
  overmould on a commercial enclosure: grip for unsteady hands, and corner
  impact absorption.
- **Heat-set M3 inserts**, not screws driven into plastic. You will open this
  many times and self-tapping screws strip out.
- **Retain the cell** with a printed bracket or foam. One rattling loose inside a
  dropped case is a puncture risk.
- Round every external corner generously.

**Layout:**

- Battery at the bottom so it is weighted like a torch and stands rather than
  tips. Target around 200g — solid without being tiring.
- One large button, centred, about a third down from the top where the thumb
  naturally rests. Nothing else she can press.
- Speaker firing out the **front face**, never the back. A speaker pointed into
  her palm or her lap is a confirmation she cannot hear, which defeats the whole
  latency design.
- Microphone port on the **top edge**, away from where fingers wrap.
- Lanyard anchor at the bottom.

**Charging: a magnetic USB-C tip** left in the port permanently, so she never
aims a connector — the USB port is the most mechanically fragile part of the
device. With 2000mAh and deep sleep this is weekly, not daily.

### Fallback if the PCB slips

A **Hammond 1553D** (147 × 89 × 25mm, soft overmoulded ABS, IP54, ~₹1,200 from
[element14 India](https://in.element14.com/c/enclosures-racks-cabinets/enclosures-boxes-cases?brand=hammond)
or [RS India](https://in.rsdelivers.com/product/hammond/1553dgy/hammond-1553-series-grey-abs-handheld-enclosure-mm/5135319))
with modules on perfboard puts a working unit in her hands while boards are in
transit. Worth knowing it exists; not worth buying up front.

## Rough cost of the finished device

| | ≈ ₹ |
|---|---|
| Electronics (already owned + ₹355 + ₹1,600) | 1,955 |
| PCB fab, 5 boards incl. shipping | 1,500–2,500 |
| Filament (PETG + TPU, reusable for years) | 2,600 |
| Inserts, magnetic cable, lanyard | 400 |

## The day the parts arrive

1. Wire the TSOP1838 to an ESP32 and **recapture every button on both remotes**.
   `stb.digit_1` is byte-identical to `channel_down` — a copy-paste bug from v1 —
   so any channel containing a 1 is refused until this is fixed.
2. While the receiver is set up, **sweep the Panasonic command space** (address
   `0x8`, commands `0x00`–`0xFF`) with a camera pointed at the TV. Manufacturers
   usually ship discrete power-on/off codes that are not on the remote. Fill
   them into the `discrete` block in `config/commands.json` and the resolver
   stops using toggles by itself — the repeat-and-turn-it-back-off problem
   disappears.
3. Flash `firmware/emitter/emitter.ino`, fill in `secrets.h`, and fire a test.
   That is Phase 1 complete.

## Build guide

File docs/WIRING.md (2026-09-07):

# Wiring and pin assignment

Enough to breadboard both devices. This is the input to a schematic later — get
it working here first, then draw the circuit you actually proved.

Pin numbers below match what is already in the firmware. Change them here and
in the sketch together, or nothing works and it looks like a hardware fault.

---

## Emitter — classic ESP32 (current), C3 alternative

| Signal | GPIO | Goes to |
|---|---|---|
| IR drive | **4** | 1kΩ → base of 2N2222A |
| Status LED | **2** classic / **8** C3 | onboard LED if fitted; C3 active low |
| IR receive *(capture sketch only)* | **15** classic / **3** C3 | TSOP1838 OUT |

The board connected on 2026-09-08 was identified as ESP32-D0WD-V3 revision
3.1 with 4 MB flash. Select **ESP32 Dev Module** for it; the C3 instructions
apply only when using the earlier C3 alternative.

### IR driver

The 2N2222A has exactly three legs, and all three are used: base from the GPIO,
collector to the LEDs, emitter to ground.

```
                          5V
                           │
          ┌────────┬───────┴───────┬────────┐
        [100R]   [100R]         [100R]   [100R]
          │        │               │        │
         LED      LED             LED      LED       (940nm, cathode down)
          │        │               │        │
          └────────┴───────┬───────┴────────┘
                           │
                     COLLECTOR (C)
                           │
GPIO4 ──[1k]──── BASE (B) ─┤  2N2222A
                           │
                      EMITTER (E)
                           │
                          GND
```

The transistor is just a switch. GPIO4 drives the base through the 1kΩ; that
turns the transistor on, which connects the LED cathodes to ground and lights
them. The ESP32 pin only ever carries ~2.6mA — the 140mA for the LEDs comes from
the 5V rail through the collector, which is the entire reason for the transistor.
A GPIO cannot source that directly.

**One resistor per LED.** LEDs do not current-share — a single shared resistor
leaves one doing nearly all the work while the others barely light.

Start with **two** LEDs and test coverage from where the box will actually sit.
IR bounces off walls and ceilings better than people expect. Add the others only
if you find a dead angle.

The numbers: ~1.3V forward drop, so each LED pulls about 35mA through its 100Ω
from the 5V rail. Four is ~140mA. Base current is (3.3−0.7)/1k ≈ 2.6mA, which
at hFE≈100 supports well over that. Comfortable against the 2N2222A's ~600mA
rating. Going beyond four buys little and starts warming the transistor.

**The 5V pin is only live when USB is plugged in.** That is fine — the emitter
is mains powered by design. No battery: a stationary device with a battery is
one that eventually dies without warning.

### Capture rig

Three wires, no transistor or LED needed:

| TSOP1838 | to |
|---|---|
| OUT | GPIO3 |
| VCC | 3V3 |
| GND | GND |

TSOP pin order varies by package — check the datasheet before powering it.
Reversing VCC and GND kills them instantly, which is why the BOM says buy three.

---

## Voice unit — XIAO ESP32S3

XIAO silkscreen labels (D0–D10) do not match GPIO numbers. Both are given
because the silkscreen is what you see while wiring and the GPIO number is what
goes in the code.

| Signal | Pad | GPIO | Goes to |
|---|---|---|---|
| Mic bit clock | D8 | **7** | INMP441 SCK |
| Mic word select | D9 | **8** | INMP441 WS |
| Mic data | D10 | **9** | INMP441 SD |
| Amp bit clock | D0 | **1** | MAX98357A BCLK |
| Amp word select | D1 | **2** | MAX98357A LRC |
| Amp data | D2 | **3** | MAX98357A DIN |
| Button | D3 | **4** | button → GND, `INPUT_PULLUP` |
| Status LED | — | **21** | onboard, active low |

**Plus power and ground to both modules** — those are not GPIO so they are not
in the table above, and forgetting them is an easy way to spend an evening
debugging a module that was never switched on:

| | INMP441 | MAX98357A |
|---|---|---|
| Power | 3V3 | 5V on the breadboard, **BAT+** once on battery |
| Ground | GND | GND |

The ESP32-S3 has two I2S peripherals, so the microphone runs on `I2S_NUM_0` and
the amplifier on `I2S_NUM_1` — no reconfiguring between record and playback.
(This is one of the reasons a C3 could not do this job.)

### INMP441

| Pin | to |
|---|---|
| VDD | 3V3 |
| GND | GND |
| L/R | **GND** — selects the left channel, which the firmware reads |
| SCK / WS / SD | GPIO7 / 8 / 9 |

Leaving L/R floating gives silence on the channel you are reading, which looks
exactly like a dead microphone.

### MAX98357A

| Pin | to |
|---|---|
| VIN | **5V** while breadboarding; **BAT+** in the final build — see below |
| GND | GND |
| BCLK / LRC / DIN | GPIO1 / 2 / 3 |
| GAIN | tie to **GND** for 12dB (floating is 9dB) |
| **SD** | breadboard: **3V3**. PCB: **GPIO5** — see below |
| + / − | speaker (both to the amp, neither to GND) |

**SD is the single most common cause of a silent MAX98357A.** It is not an
optional shutdown line you can ignore: `SD_MODE` selects the output mode *by
voltage*, and anything below about 1.4V mutes the amplifier entirely. Some
breakouts include a pull-up so a floating pin works; plenty of cheap ones do
not, and those sit silently in shutdown forever while everything else looks
correct.

Tie it to 3V3 and the ambiguity disappears. `firmware/audiotest` proves it
either way by toggling SD between two identical tones.

**On the PCB, give SD its own GPIO instead — it is the single most important
pin for battery life.** Left enabled the amplifier draws ~2.4mA continuously,
about 35x everything else in the sleeping device combined. Driving it low
before deep sleep takes standby from ~2.5mA to ~0.07mA, which on a 1000mAh cell
is the difference between charging every 12 days and every 37.

`AMP_SD_PIN` in the firmware defaults to GPIO5. Set it to `-1` while SD is
hard-wired to 3V3 on the breadboard.

**On the breadboard, use the 5V pin.** It is live whenever USB is plugged in,
and there is no battery yet, so BAT+ is dead.

**In the final build, move it to BAT+ — not 3V3.** XIAO's 5V pin goes dead on
battery power, so the amp would fall back to 3.3V and get noticeably quieter.
Wired to BAT+ it sees 3.7–4.2V, which matters because she is hard of hearing and
a confirmation she cannot hear is the same as no confirmation. The MAX98357A
accepts 2.5–5.5V with good supply rejection, so the sagging battery voltage is
fine.

If it is still too quiet, tie GAIN to GND before reaching for a bigger speaker.

### Button

To GND with `INPUT_PULLUP` — no external resistor. Debounce in software.

Avoid D6/D7 (GPIO43/44): they are the UART, and you want serial output while
debugging this.

---

## Bring-up order

Test each piece alone. Wiring everything then powering on gives you no idea
which of six things is wrong.

1. **`firmware/selftest`.** USB only, no wiring. Confirms the board, the IDE
   settings, the PSRAM (including a real 192KB allocation) and surveys WiFi.
   Enable **USB CDC On Boot**, and on a XIAO set **Tools > PSRAM = OPI PSRAM**
   or a board that has 8MB reports zero.
2. **Re-run the scan from where the device will actually sit.** Behind a
   cabinet is a different number from your desk, and anything worse than about
   -70 dBm means intermittent MQTT drops later.
3. **TSOP alone**, with `firmware/capture`. Press any remote and watch codes
   appear. This is Phase 0 and needs nothing else.
4. **IR LED alone.** Fire one code at the TV. A phone camera sees IR — point it
   at the LED to confirm it is flashing before blaming the code.
5. **Emitter on MQTT.** `firmware/emitter` with `secrets.h` filled in. Watch
   `/health` flip `emitter_online` to true. That is Phase 1.
6. **Microphone alone.** Record and dump levels over serial before involving
   the network.
7. **Speaker alone.** Play a tone before involving the microphone.
8. **Both together** — and listen for the amplifier's switching noise in the
   recording. If it is there, physical distance between mic and speaker is the
   only fix, and it is why they go at opposite ends of the eventual PCB.

## Things that quietly waste an evening

**2N2222A pinout.** TO-92, flat face toward you, legs down: **E–B–C** left to
right. Verify against the datasheet for your specific part — some suppliers ship
PN2222A or S8050 with different orders, and a swapped transistor simply does
nothing while looking correctly wired.

**IR LED polarity.** Long leg is the anode, toward the 100Ω and 5V. Backwards is
silent, not broken.

**IR LED wavelength.** Must be 940nm. 850nm looks identical and glows faintly
visible red when driven, and most receivers ignore it entirely.

**C3 strapping pins.** GPIO2, GPIO8 and GPIO9 are read at boot. GPIO8 as the
status LED is normal (it is the onboard LED), but do not hang anything that
pulls GPIO9 low or the board enters download mode instead of running.

**Common ground.** Everything shares GND, including the transistor emitter. This
is the single most common breadboard mistake and it produces symptoms that look
like software bugs.

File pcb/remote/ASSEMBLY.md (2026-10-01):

# RevGen A3 assembly

> **A3 supersedes A2 and rejected A1.** A3 corrects the amplifier for component-side-up mounting. Physical module fit and charging/sleep measurements still require prototype verification. The separate 24 kHz playback issue remains open.

Carrier for the existing plain Seeed XIAO ESP32S3, round Robu INMP441 and
Adafruit MAX98357A mono breakout. Speaker connects to J2.

## Fabrication and fit

120 × 45 mm contour, R8 corners, two layers, 1.6 mm FR4, standard 1 oz copper.
Four M2.5 mounting holes. The Gerber job size includes the 0.05 mm outline stroke.
Print `artifacts/assembly-1to1.svg` at **100%, no fit-to-page**, check the 120 mm
length with a ruler, and compare the owned modules and button.

The mic's nominal 2.54 mm pin pitch / 7.62 mm row separation is inferred from
its product image, not a supplier mechanical drawing. The chosen button is
Omron B3F-40xx; an arbitrary 12 mm button is not guaranteed to fit.

The mic center is 22.5 mm from either side, 31 mm below the top edge, above
the talk button. Nearby passives have been moved to preserve clearance.

## Install modules

1. Fit passives first. Leave **R1 empty**, fit **R5 = 0 ohms**.
2. XIAO USB points toward the top. J3/J4/J6 together represent one module,
   not three connectors to purchase. J3/J4 support castellated soldering or
   pins. J6 offers rear solder access to underside battery pads: 1 is B+,
   2 is B−. These require solder joints. If existing headers raise the XIAO,
   use two short insulated battery leads; lands cannot bridge an air gap.
   Rear-access soldering has not been physically tested on this prototype.
3. Mic **CHIP UP, acoustic port DOWN**, over the 3.2 mm hole. With USB at top,
   upper row left-to-right is **L/R, WS, SCK**; lower row **GND, VDD, SD**.
   Keep the acoustic opening clear.
4. Amplifier **CHIP / COMPONENTS UP**, with its speaker row toward the bottom
   of the remote. Input row left-to-right is **VIN, GND, SD, GAIN, DIN, BCLK, LRC**.
   Use soldered header pins with clearance for underside solder joints. J5 is its speaker
   pair, 12.954 mm below the input row, 3.5 mm pitch. Connect the module speaker
   holes using soldered pins or lead stubs; omit its screw terminal block.
   At J5, **speaker + is left and − is right**, viewed from the component side
   with the remote USB at the top. Do not use the superseded A2 mounting order.
5. Connect a speaker rated at least 4 ohms at J2 +/−. Neither speaker terminal is ground. Connect a
   protected single-cell 3.7 V LiPo at J1, checking polarity against the + mark.
   SW2 isolates the battery from the switched rail.

The XIAO uses an **external IPEX antenna**. Preserve cable access and position
it near the copper-free side area, away from battery and metal. Keep USB,
reset and boot accessible. Enclosure and speaker mounting are not defined here.

## Additional parts

| References | Value / footprint |
|---|---|
| C1, C3 | 10 µF 16 V radial electrolytic, D6.3 mm, P2.5 mm |
| C5 | 220 µF 16 V radial electrolytic, D6.3 mm, P2.5 mm |
| C2, C4, C6, C7 | 100 nF ceramic disc, P5 mm; C7 optional debounce |
| R2, R3 | 1 MΩ 1%, axial 1/4 W, P10.16 mm |
| R4 | 100 kΩ axial, P10.16 mm, button pull-up |
| R5 | 0 Ω axial link, P10.16 mm, fitted |
| R6 | 2.2 kΩ, 1%, axial 1/4 W, P10.16 mm; SD series protection |
| R7 | 10 kΩ, 1%, axial 1/4 W, P10.16 mm; SD default-off pull-down |
| R1 | 100 kΩ gain option, **do not fit** with R5 |
| SW1 | Omron B3F-40xx 12 mm tactile |
| SW2 | C&K **1101M2S3CQE2**, 6 A at 28 VDC; common pin 2, 4.70 mm pitch, 1.85 mm drills |
| J1 | JST S2B-PH-K right-angle, 2 mm pitch, 2 pins |
| J2 | JST B2B-PH-K vertical, 2 mm pitch, 2 pins |
| TP1–TP11 | Test pads, no fitted part required |

Respect electrolytic polarity. These parts are additional to the owned modules.

## First power and charging

Charging is automatic in the XIAO hardware; separate charging firmware is not
needed simply to charge the cell. Battery alerts and validation remain pending.

The XIAO onboard charger connects through its underside battery pads; no
separate charger IC is added. SW2 must connect the battery for charging.
With SW2 off, USB may still power the XIAO.

Before battery installation, check shorts and J6 polarity/continuity. On first
power verify 3V3, VBAT_SW and the divider: TP9 should read half TP8. Verify
button wake, recording and playback. Test USB charging current and cell voltage
initially with the remote idle, then validate termination and behavior with the
amplifier active. Charging on the assembled carrier has not yet been verified. CAD checks are not functional charging tests.

## Sources

- [Seeed XIAO documentation](https://wiki.seeedstudio.com/xiao_esp32s3_getting_started/), official [footprints](https://files.seeedstudio.com/wiki/XIAO-KiCad-Library/New_XIAO_Series_Footprints.zip) and [symbols](https://files.seeedstudio.com/wiki/XIAO-KiCad-Library/XIAO_Series_SCH_Symbols.zip). Battery pad 23 is VBAT, 24 is GND.
- [Adafruit original mono board files](https://github.com/adafruit/Adafruit-MAX98357-I2S-Amp-Breakout), copied with license into `sources/`.
- User's [Robu mic](https://robu.in/product/inmp441-mems-high-precision-omnidirectional-microphone-module-i2s/) and [Robu amplifier](https://robu.in/product/adafruit-max98357a-i2s-3w-class-d-amplifier-breakout-board/). Mic orientation was checked against pictured labels; pitch needs physical comparison.

## A2 electrical corrections

Use the exact new switch; the old OS102011MS2Q cannot substitute. R6 limits
current into amplifier SD when its supply falls below the ESP32 logic supply.
R7 holds SD low when the GPIO floats. Including the breakout 1 MΩ pull-up and
100 kΩ internal pull-down, nominal SD is about 38 mV with GPIO floating at a
4.2 V cell, and 2.66 V when driven high from 3.3 V. Verify these states on the
prototype. Updated firmware holds GPIO5 low through deep sleep and mutes the
amplifier before stopping clocks. Firmware compilation is separate from
charging and sleep-current measurements.

Switch footprint is based on [C&K 1000 series datasheet](https://www.littelfuse.com/assetdocs/littelfuse-ck-slide-1000-series-datasheet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), pages 2 and 4; SD protection follows [MAX98357A datasheet](https://www.analog.com/media/en/technical-documentation/data-sheets/MAX98357A-MAX98357B.pdf), page 17.

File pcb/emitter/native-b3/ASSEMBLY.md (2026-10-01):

# Emitter B3 prototype assembly

Board: 80 x 65 mm rounded rectangle, two copper layers, FR-4, 1.6 mm thickness,
1 oz copper. Standard lead-free HASL is suitable. Three 3.2 mm non-plated
mounting holes. No gold fingers, castellations, or edge plating. Use both PTH
and NPTH drill files with the seven copper/mask/silkscreen/outline Gerbers.

## Parts and fit

| Reference | Part / value | Board footprint requirement |
|---|---|---|
| U1 | Owned classic 30-pin ESP32 development board | 15 pins per row, 2.54 mm pitch, 25.40 mm between rows; 1.0 mm holes |
| D1-D4 | Everlight IR333C/H0/L10, 940 nm | 5 mm radial body, 2.54 mm leads |
| R1-R4 | 100 ohm, 0.25 W each | Axial, 7.62 mm formed lead pitch; 6.3 x 2.5 mm body |
| R5 | 220 ohm | Same axial footprint |
| R6,R7 | 10 kohm | Same axial footprint |
| Q1 | AO3400A | SOT-23, gate 1 / source 2 / drain 3 |
| C1,C2 | 100 nF ceramic, rated at least 10 V | 2.50 mm lead pitch; 5.0 mm diameter, 2.5 mm thick body |
| C3 | 100 uF, at least 10 V | Radial electrolytic, 6.3 mm diameter, 2.50 mm leads |
| J1 | 1x3 header or wired receiver connection | 2.54 mm pitch |
| SW1 | Normally open 6 mm tactile switch | Standard four-leg 6 mm footprint, 6.5 x 4.5 mm pin grid |

U1 spacing comes from the user's original Gerbers, not the rejected 38-pin
ESP32 documentation. The module body/USB envelope is reserved clearance, not
a measured case drawing. Check cable access and body fit at full scale before
ordering an enclosure. Female header sockets can make the ESP32 removable;
check the actual board's pins and socket height before fitting other hardware.

## Orientation and operation

- Component side up: ESP32 antenna toward the `ANTENNA` area,
  USB toward the `USB` label. Square U1 pad 1 is EN at the lower left; USB faces right.
- LED pad 1 is cathode (flat side), pad 2 is anode. The cathodes connect to
  Q1 drain; each anode has its own 100 ohm resistor. Do not substitute the old
  NPN into Q1's MOSFET footprint.
- All four LEDs send the same signal. During assembly, form D2/D3 toward the
  front and D1/D4 toward the left/right as the enclosure permits. Their stock
  footprint/3D model is upright; coverage angles are set by lead forming and
  must be tested. Four narrow-beam LEDs do not guarantee all-around coverage.
- C3 positive goes to the silkscreen `+`. Its stripe/negative goes to GND.
- J1 pins 1/2/3 are 3V3/GND/OUT. Use wires to adapt the receiver's actual pin
  order. It must explicitly support 3.3 V supply and logic. A generic receiver
  part name alone does not establish its pinout or supply rating.
- SW1 joins GPIO27 to ground while pressed. Hold five seconds with the new
  learning firmware; receiver OUT is GPIO15 and transmit drive is GPIO4.

## Checks still requiring hardware

Confirm the owned ESP32's USB-derived VIN rail provides approximately 5 V and
can supply the LED load alongside ESP32 Wi-Fi peaks. At 5 V with an illustrative
1.3 V LED drop, each branch is about 37 mA while on (148 mA for four). The power
path inside the development board cannot be established from carrier Gerbers.

Before connecting USB, check for shorts and component polarity. Then verify
receiver capture, physical replay, learning-button behavior, and the coverage
at the intended installation distance. The learning firmware/backend changes
must be flashed/deployed separately; PCB completion does not perform those steps.

CAD status: strict PCB DRC and schematic parity have zero violations or unconnected pads; schematic ERC has zero errors and warnings. No physical build
of this four-LED revision has yet been tested.

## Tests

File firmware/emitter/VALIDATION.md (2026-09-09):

# Emitter development validation — 2026-09-08

## Production voice request to physical emitter: PASS

A Windows-generated English recording, "Increase the TV volume", was uploaded
to `https://project-revgen.fly.dev/command` with the configured device token.
Production returned HTTP 200, `X-RevGen-Outcome: tv.volume_up`, server processing
2531 ms and total request time 3812 ms. COM8 captured:

```text
ack 3bb1ba80-0ff7-4142-878b-40d631191bf8 ok=1
executing 3bb1ba80-0ff7-4142-878b-40d631191bf8 (1 steps)
  panasonic addr=0x8 cmd=0x20
done
```

The spoken reply was a valid mono PCM16 WAV, 24000 Hz, 33536 frames. This
establishes production speech processing, command delivery, device execution,
and returned audio. It does not establish Malayalam recognition accuracy,
handheld playback or physical appliance response. The input was synthetic;
no external IR components were connected during this run.

The local backend now requests 32000 Hz because MAX98357A does not support
24000 Hz LRCLK. Cache keys include synthesis settings and offline mode;
generated and cached WAVs are checked for mono PCM16 at the configured rate.
Offline tests now produce valid silence WAVs. Backend suite: 92 passed.
This audio fix is NOT deployed: no Fly CLI/login is available on this PC.

## Backend-to-emitter execution confirmed on serial

A TV volume-up command sent through the backend MQTT client received a matching
positive ACK. COM8 simultaneously logged the same command ID, execution of one
Panasonic step (`addr=0x8 cmd=0x20`), and `done`. This establishes actual device
receipt and completion of its IR-send routine, beyond the MQTT ACK alone.
Command ID: `a4a1a1aa-497b-48f1-adf9-4dcb4956526c`.

Backend-to-emitter command delivery/execution is PASS. The board had no external
IR circuit connected during this run; physical IR output and current appliance
response were not measured. The published command came from the local backend
MQTT client using the configured broker, not a new request to production's
voice `/command` endpoint.

## Prior hardware test confirmed by user

The user reports previously controlling the TV through this IR driver circuit
using serial-monitor triggers. Treat that tested circuit/TV combination as
user-verified; do not require repeating basic driver bring-up as a prerequisite
for software integration. Exact coverage, every catalog button and STB codes
are not established by that report.

The backend MQTT client subsequently sent one Panasonic TV volume-up command
(address 8, command 32) and received a positive acceptance ACK from the flashed
emitter. The current board has no external components connected, so this run
verified network delivery and firmware acceptance, not a new physical TV
response. Full voice-to-appliance testing awaits reconnecting the circuit.

## WiFi setup completed: live integration verified

After the user configured WiFi, `backend/tools/check_emitter.py --probe`
confirmed broker connection, emitter online status, and an ACK for a zero-delay
command. This exercises the real firmware command parser and MQTT return path
without firing IR. The deployed backend `/health` also returned `ok: true`,
`emitter_online: true`, `offline_mode: false`. Physical appliance response and
IR coverage are still untested. Production reported zero configured channels.
This completes the WiFi/ACK checks marked pending in the initial upload notes
below. The locally modified backend code has not been redeployed.

## Current physical board and upload

The user corrected the connected hardware after the earlier C3 build. USB
identification reads **ESP32-D0WD-V3, revision 3.1**, 40 MHz crystal, 4 MB
flash, CP2104 bridge, COM8. The signed Silicon Labs driver was installed to
resolve Windows device error 28. This classic ESP32 is the current emitter.

Configured build: ESP32 Arduino core 3.3.11, `esp32:esp32:esp32`, 4 MB flash,
PSRAM disabled. Program is 1,142,081 / 1,310,720 bytes (87%); static globals
50,116 bytes. The staged credentials match ignored secrets.h. Upload of
bootloader, partitions and application completed with esptool hash verification.
Serial boot confirmed the correct chip and GPIO4 IR output, with 276,880 bytes
free heap before network setup.

A complete 4 MB pre-upload flash backup is retained locally at
`build/board-backup/com8-before-emitter-20260908.bin`. It is ignored by Git and
may contain the board's old configuration; do not distribute it.

The supplied MQTT credentials authenticate from the backend client. Broker TLS
hostname/chain validation passed; the firmware trusts ISRG Root X1. No IR was
emitted during testing. The physical board could not connect to its previously
saved WiFi and opened **RevGen-Emitter**, so the live acknowledgement probe
remains pending WiFi setup. Connect to that AP and open `http://192.168.4.1`.
The portal times out after 180 seconds and restarts; use reset if necessary.

The supplied remote credentials are saved in firmware/remote/secrets.h; MQTT
credentials and the device token are also in backend/.env. All three real
configuration files are confirmed ignored by Git. The earlier statements below
about missing credentials/no flashing describe the initial C3 validation only.

## Earlier C3 compilation and backend tests

Target: documented ESP32-C3 Super Mini, `esp32:esp32:esp32c3:CDCOnBoot=cdc`.
The BOM records −39 dBm WiFi reception. Its missing PSRAM is a limitation for
the handheld audio design, not a requirement of the small-command IR emitter.
No C3-specific hardware failure was found in the inspected project notes.

- Final firmware compile/link: PASS, ESP32 Arduino core 3.3.11, IRremote 4.7.1,
  PubSubClient 2.8, ArduinoJson 7.4.3, WiFiManager 2.0.17.
- Program: 1,191,701 / 1,310,720 bytes (90% of selected app partition).
- Static globals: 39,224 bytes; runtime TLS/WiFi heap use must be measured on
  hardware. The linker's remaining-memory figure is not a runtime measurement.
- Backend suite: 78 passed. Targeted emitter suite: 21 passed. Tests cover
  cross-thread ACK delivery, late ACKs, cancellation cleanup, failed publish,
  disconnect handling, numeric limits and MQTT packet overhead.
- Direct test tool dry-runs: TV volume_up and STB channel_up produce valid
  catalog commands through the same serializer as the backend.
- Compiled staged sketch matches current emitter.ino. Placeholder credentials
  were used; no board was flashed. Reproduce with check_build.ps1.

Live MQTT and IR were not tested. This checkout has no backend/.env or emitter
secrets.h. Provision matching broker credentials and the broker issuing root
CA, then run the documented test_emitter.py --execute test. COM3 was detected
only as a generic ESP32 USB device and was not assumed to be the emitter.

Remaining catalog tasks: recapture STB digit 1 and configure channel numbers.
Recent-command deduplication is RAM-only (last eight IDs, five minutes) and
does not provide exactly-once delivery across resets. An ACK confirms command
acceptance, not appliance response. Fake-emitter testing does not establish IR
timing, driver current or coverage. Do not run a fake and physical emitter on
the same production topics.

## Learning implementation — 2026-09-08

This section records the new local build, separately from historical checks above.
Classic ESP32 compilation passes: 1,168,059 / 1,310,720 bytes of application flash
(89%); static RAM 51,956 / 327,680 bytes (15%). The source includes parity-error
rejection. Backend suite: 115 passed; one dependency deprecation warning.
The headless browser test passes for capture gating, test/save capture versions,
channel mapping, upload-state presentation, session-token use and safe name rendering.

This learning build has not been flashed. Its backend changes have not been
deployed. Live receiver capture, physical replay, MQTT learning-topic ACLs and
restart persistence across actual devices remain to be tested. See
`docs/EMITTER_LEARNING.md` for the setup and rollout checklist.

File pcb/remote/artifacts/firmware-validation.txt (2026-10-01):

RevGen A2 firmware build validation
Date: 2026-09-07
Result: PASS; compile and link exited 0 and produced remote.ino.bin.
Arduino CLI: arduino-cli  Version: 1.5.1 Commit: 01f3d4f2b Date: 2026-06-05T10:22:12Z
ESP32 Arduino core: 3.3.11
WiFiManager: 2.0.17 (temporary build dependency)
FQBN: esp32:esp32:XIAO_ESP32S3:PSRAM=opi,CDCOnBoot=default,PartitionScheme=default_8MB
Command: arduino-cli --config-file firmware/remote/build/review/arduino-cli.yaml compile -b esp32:esp32:XIAO_ESP32S3:PSRAM=opi,CDCOnBoot=default,PartitionScheme=default_8MB --build-path firmware/remote/build/review/output --verbose firmware/remote/build/review/remote
Staged remote.ino exactly matches firmware/remote/remote.ino.
Source SHA256: 03BFC981EC182FE22105F085B55BA13B6F1173671D107E05EA3420AF6FF4A155
Secrets: staged secrets.example.h as secrets.h; real credentials were not used.
Sketch uses 1181510 / 3342336 bytes (35%).
Global variables use 52260 / 327680 bytes (15%); 275420 bytes remain.
Firmware binary length: 1181888 bytes.
Changes validated: GPIO5 RTC shutdown hold and wake release, SD shutdown before clock removal.
No hardware was flashed. Sleep current, repeated wake/playback and charging require bench verification.
Official RTC API reference: https://docs.espressif.com/projects/esp-idf/en/stable/esp32s3/api-reference/peripherals/gpio.html

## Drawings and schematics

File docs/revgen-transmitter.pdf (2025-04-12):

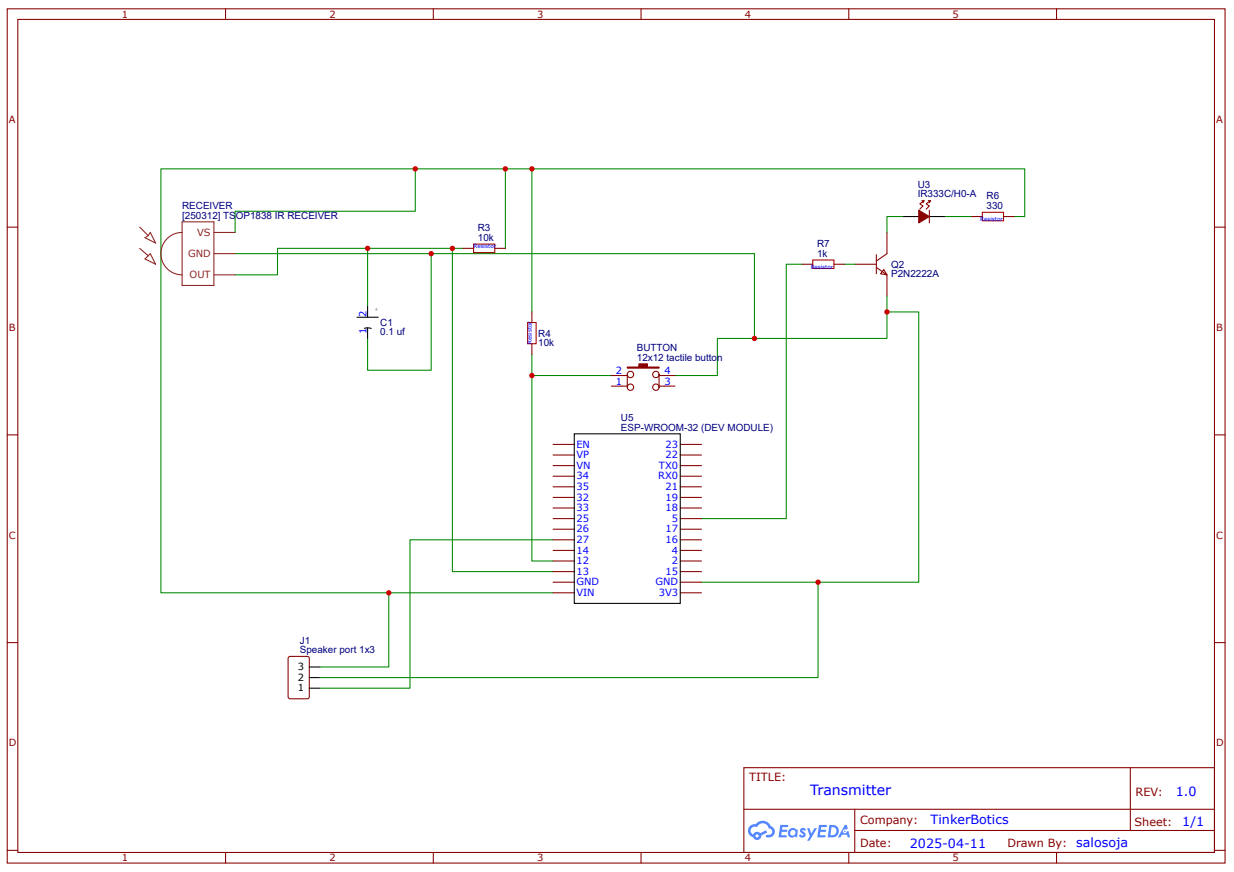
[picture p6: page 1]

ESP-WROOM-32 (DEV MODULE)

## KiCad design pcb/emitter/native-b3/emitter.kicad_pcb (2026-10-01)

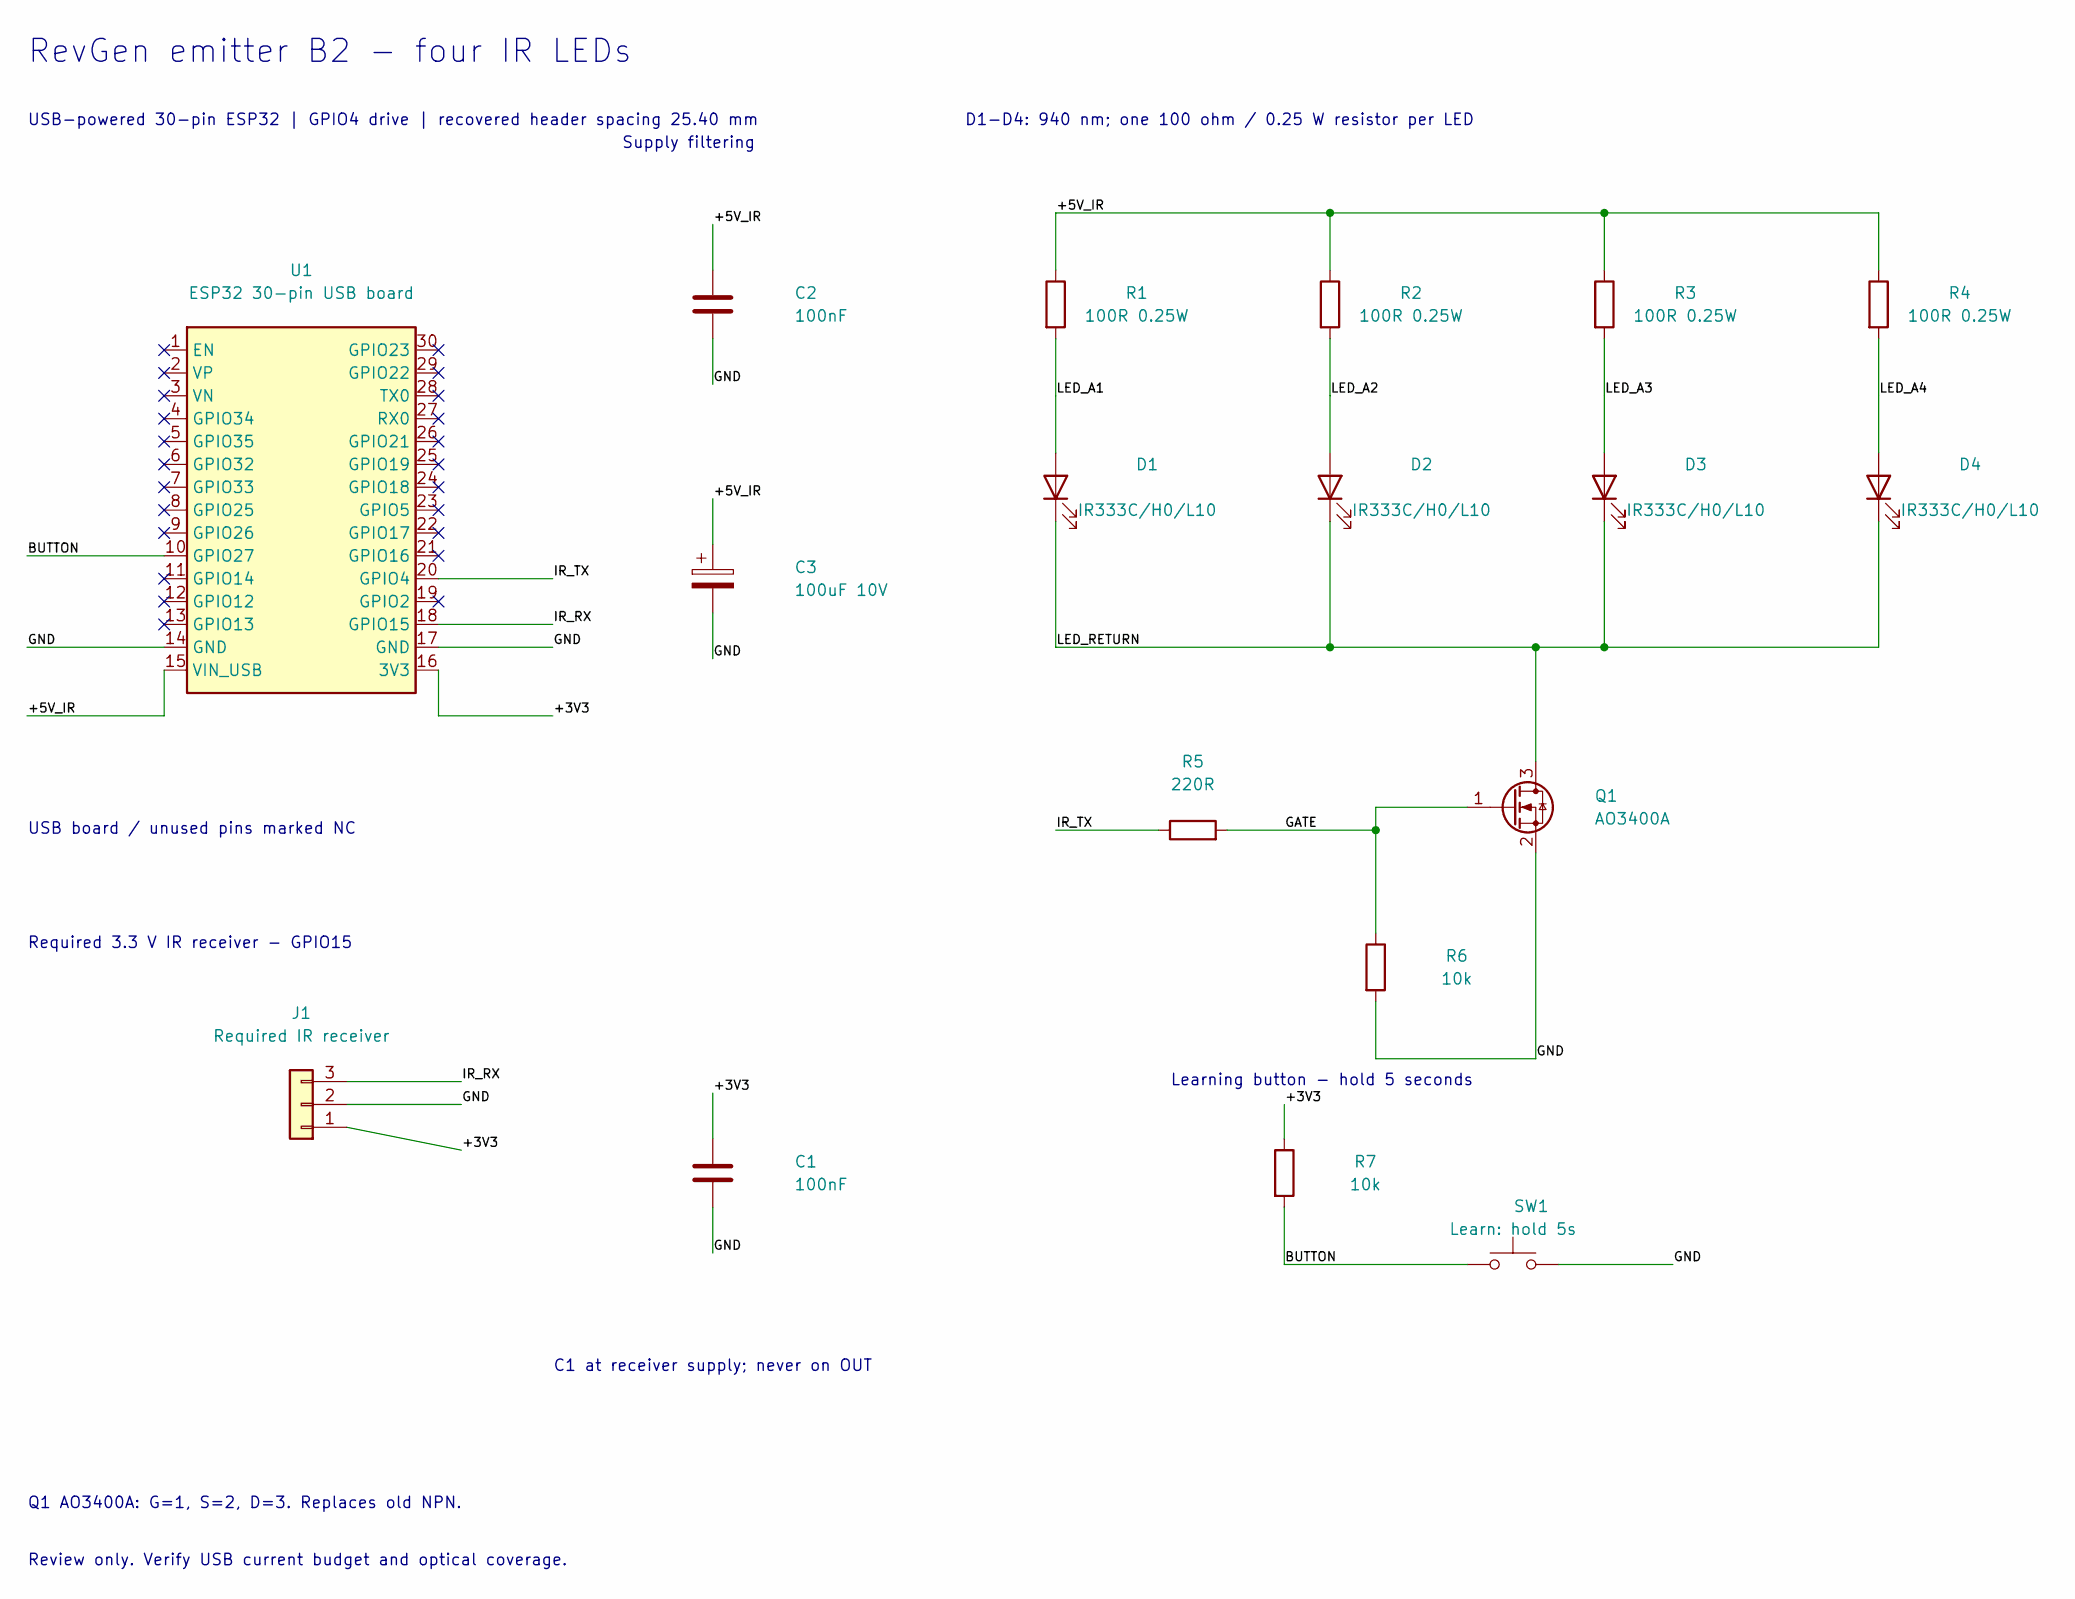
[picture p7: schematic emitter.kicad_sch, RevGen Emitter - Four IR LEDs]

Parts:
C1, C2: 100nF; C_Disc_D5.0mm_W2.5mm_P2.50mm
C3: 100uF 10V; CP_Radial_D6.3mm_P2.50mm
D1, D2, D3, D4: IR333C/H0/L10; LED_D5.0mm
J1: Required IR receiver; PinHeader_1x03_P2.54mm_Vertical
Q1: AO3400A; SOT-23
R1, R2, R3, R4: 100R 0.25W; R_Axial_DIN0207_L6.3mm_D2.5mm_P7.62mm_Horizontal
R5: 220R; R_Axial_DIN0207_L6.3mm_D2.5mm_P7.62mm_Horizontal
R6, R7: 10k; R_Axial_DIN0207_L6.3mm_D2.5mm_P7.62mm_Horizontal
SW1: Learn: hold 5s; SW_PUSH_6mm
U1: ESP32 30-pin USB board; ESP32_30pin_recovered

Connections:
/+3V3: C1.1, J1.1, R7.1, U1.16 (3V3)
/+5V_IR: C2.1, C3.1, R1.1, R2.1, R3.1, R4.1, U1.15 (VIN_USB)
/BUTTON: R7.2, SW1.1, U1.10 (GPIO27)
/GATE: Q1.1 (G), R5.2, R6.1
/GND: C1.2, C2.2, C3.2, J1.2, Q1.2 (S), R6.2, SW1.2, U1.14 (GND), U1.17 (GND)
/IR_RX: J1.3, U1.18 (GPIO15)
/IR_TX: R5.1, U1.20 (GPIO4)
/LED_A1: D1.2 (A), R1.2
/LED_A2: D2.2 (A), R2.2
/LED_A3: D3.2 (A), R3.2
/LED_A4: D4.2 (A), R4.2
/LED_RETURN: D1.1 (K), D2.1 (K), D3.1 (K), D4.1 (K), Q1.3 (D)

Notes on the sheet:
RevGen emitter B2 - four IR LEDs
USB-powered 30-pin ESP32 | GPIO4 drive | recovered header spacing 25.40 mm
USB board / unused pins marked NC
Supply filtering
D1-D4: 940 nm; one 100 ohm / 0.25 W resistor per LED
Required 3.3 V IR receiver - GPIO15
C1 at receiver supply; never on OUT
Learning button - hold 5 seconds
Q1 AO3400A: G=1, S=2, D=3. Replaces old NPN.
Review only. Verify USB current budget and optical coverage.

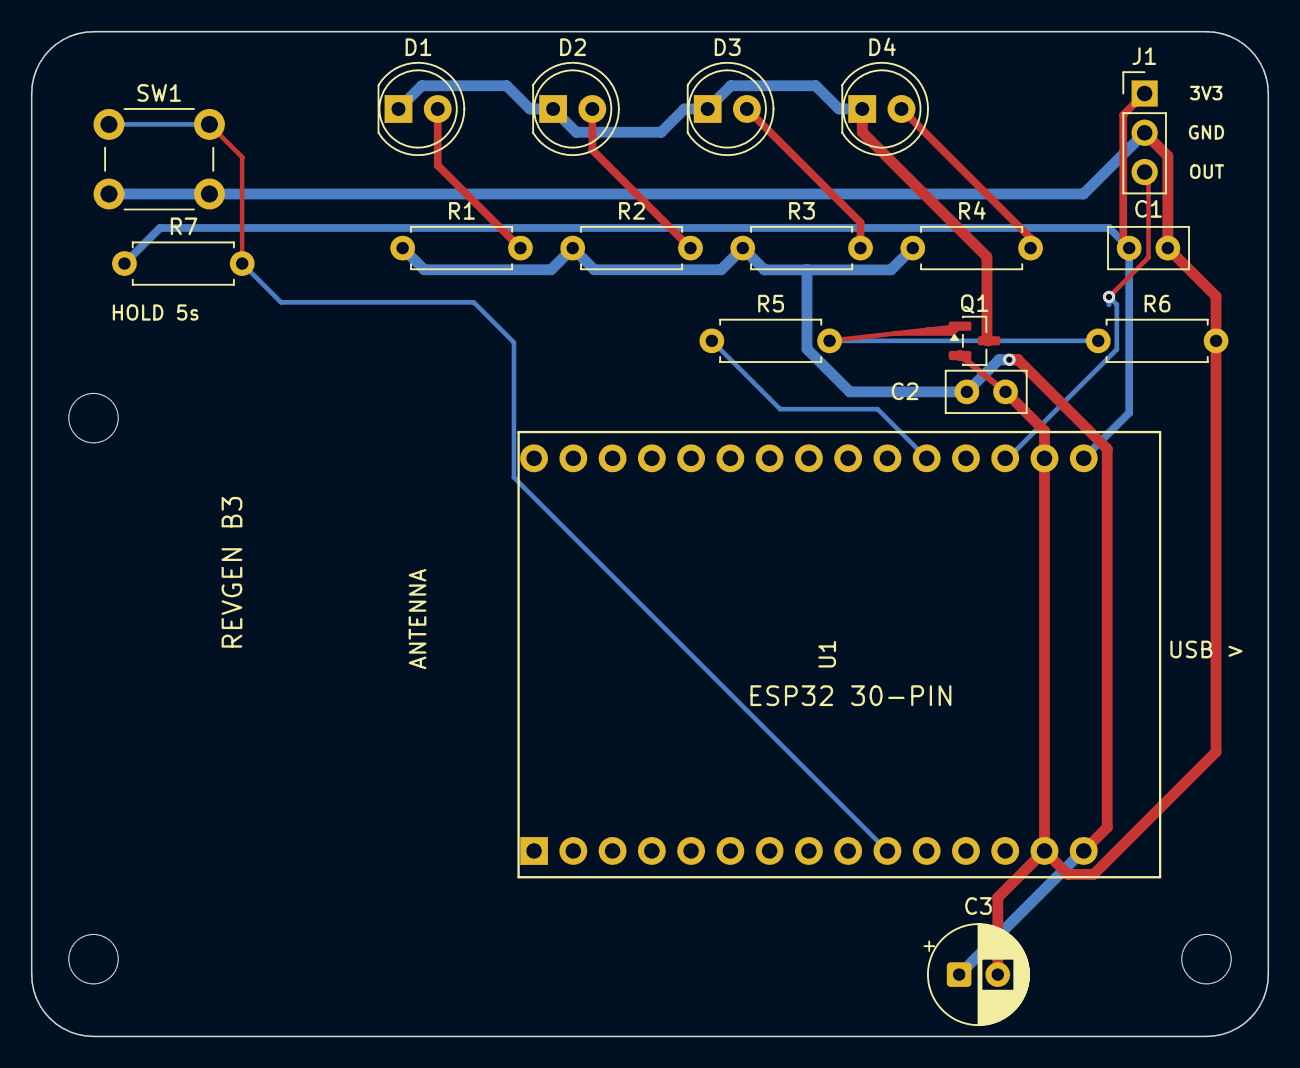
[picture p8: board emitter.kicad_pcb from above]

Board: 2 copper layers, 80.0 x 65.0 mm, 21 parts (0 on the bottom side), 12 nets.

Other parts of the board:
MH1, MH2, MH3: MountingHole_3.2mm_M3

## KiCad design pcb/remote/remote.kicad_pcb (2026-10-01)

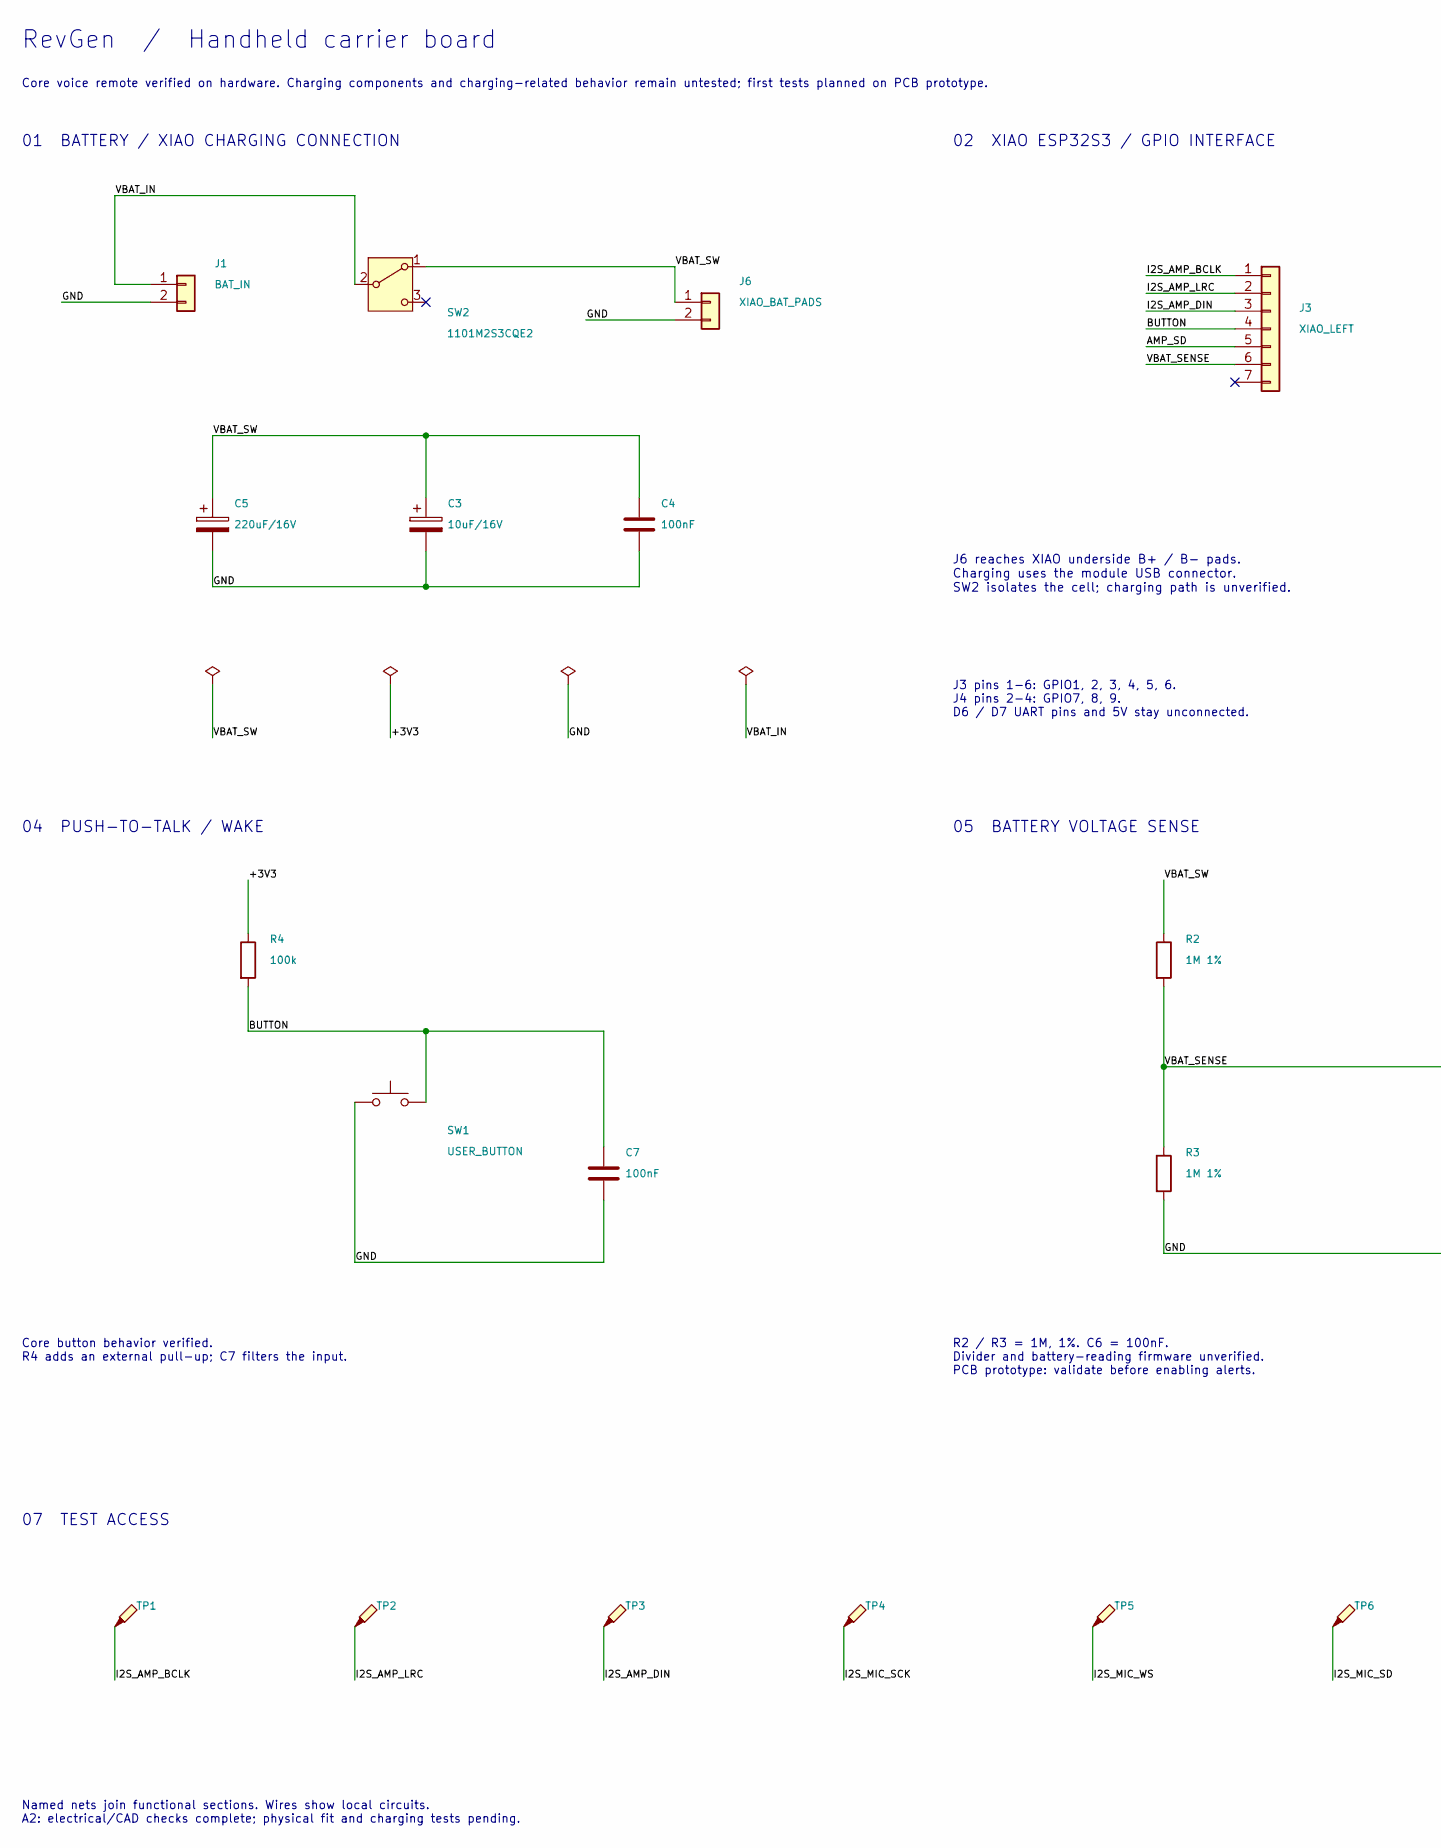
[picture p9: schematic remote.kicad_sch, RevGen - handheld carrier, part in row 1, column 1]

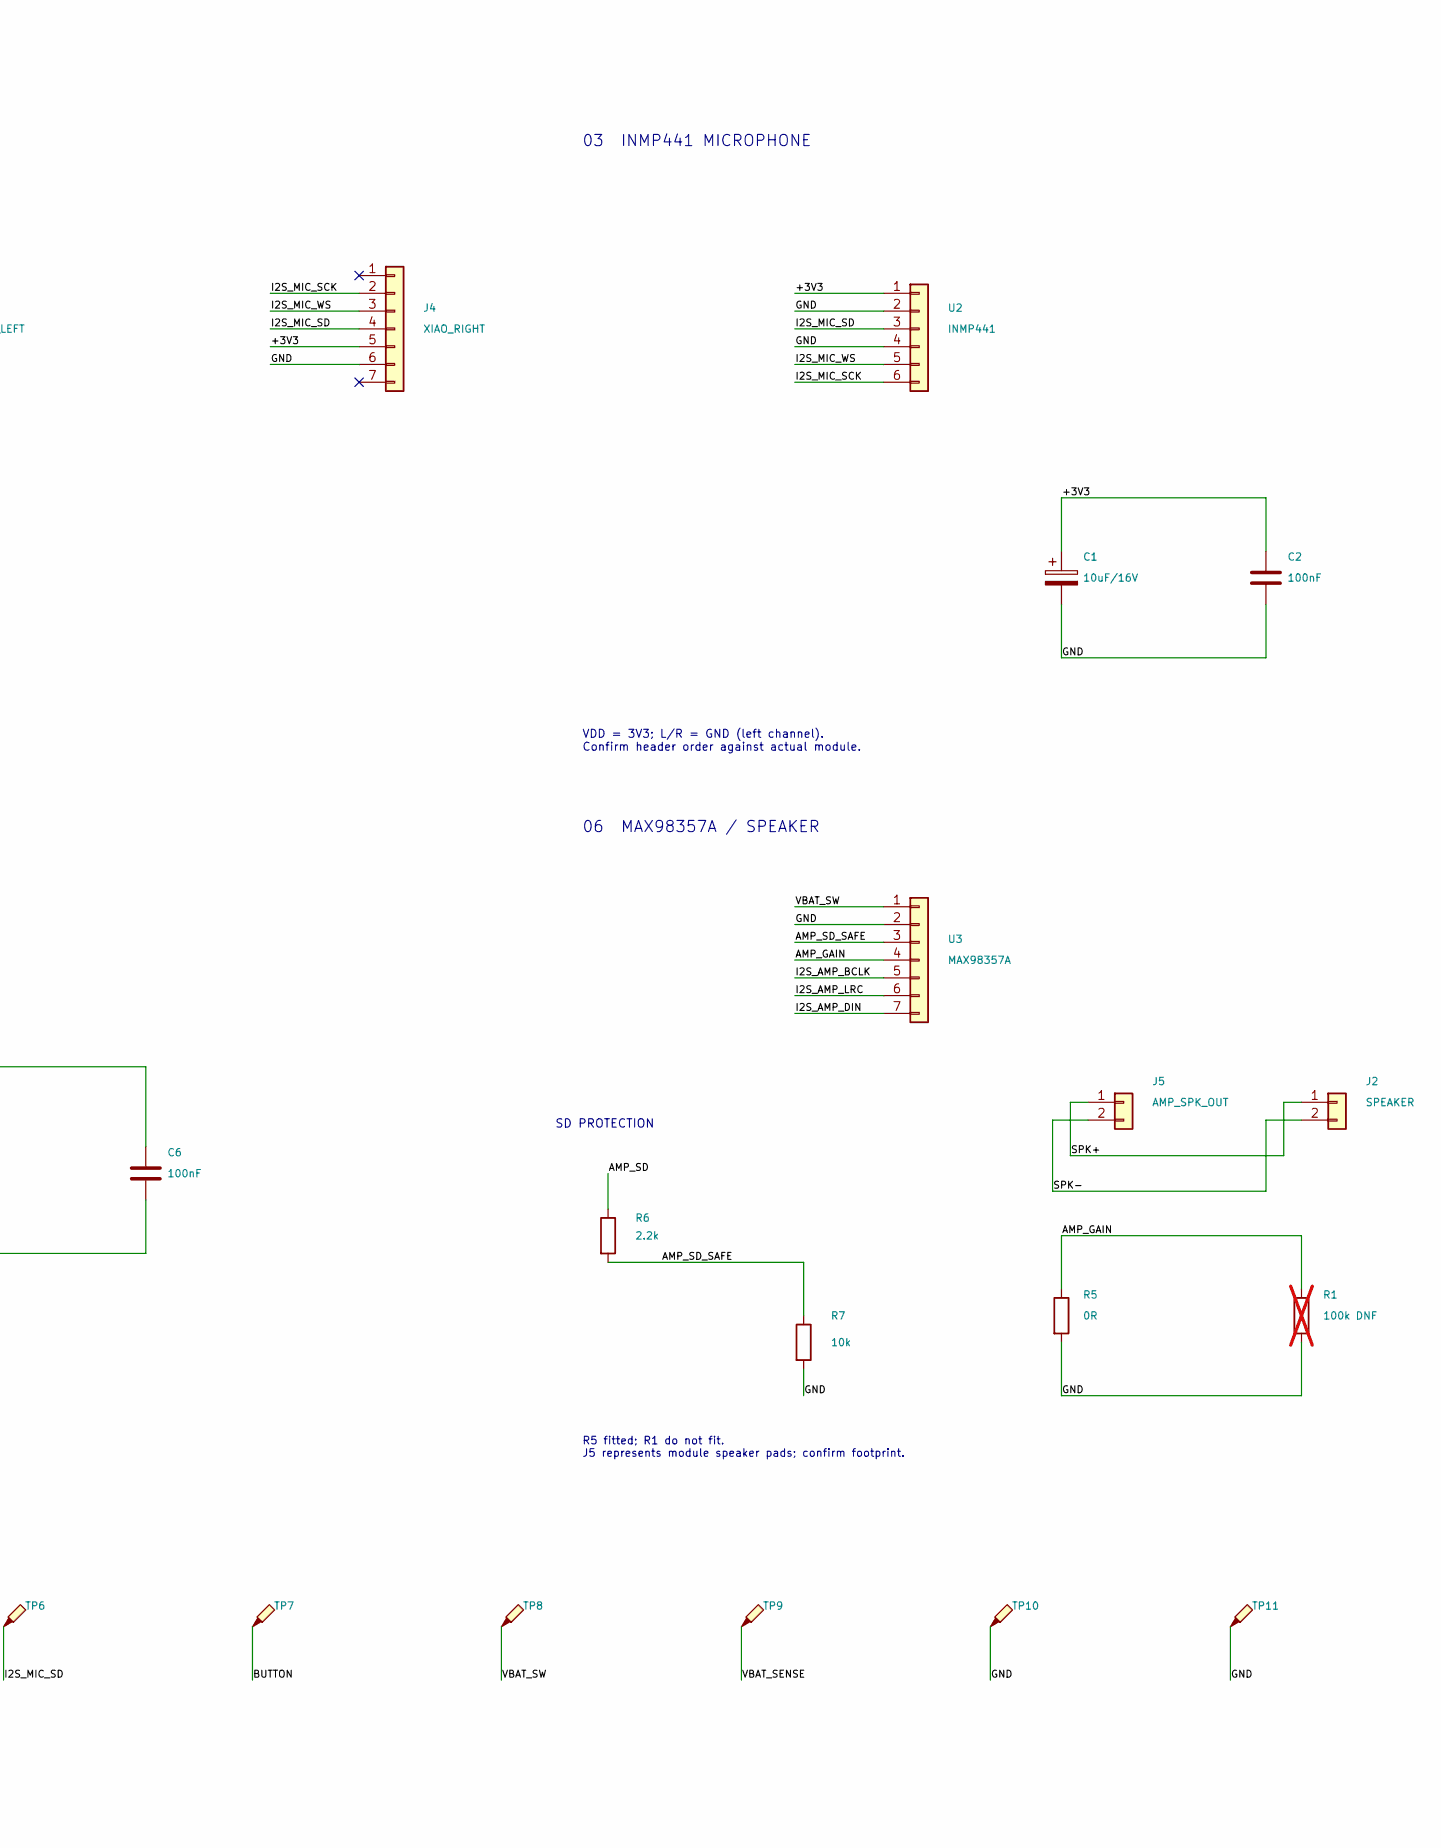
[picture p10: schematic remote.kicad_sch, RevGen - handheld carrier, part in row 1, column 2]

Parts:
C1, C3: 10uF/16V; CP_Radial_D6.3mm_P2.50mm
C2, C4, C6, C7: 100nF; C_Disc_D5.0mm_W2.5mm_P5.00mm
C5: 220uF/16V; CP_Radial_D6.3mm_P2.50mm
J1: BAT_IN; JST_PH_S2B-PH-K_1x02_P2.00mm_Horizontal
J2: SPEAKER; JST_PH_B2B-PH-K_1x02_P2.00mm_Vertical
J3: XIAO_LEFT; XIAO_Left
J4: XIAO_RIGHT; XIAO_Right
J5: AMP_SPK_OUT; MAX98357A_Adafruit_Speaker
J6: XIAO_BAT_PADS; XIAO_Battery_SolderAccess
R1: 100k DNF; R_Axial_DIN0207_L6.3mm_D2.5mm_P10.16mm_Horizontal; not fitted
R2, R3: 1M 1%; R_Axial_DIN0207_L6.3mm_D2.5mm_P10.16mm_Horizontal
R4: 100k; R_Axial_DIN0207_L6.3mm_D2.5mm_P10.16mm_Horizontal
R5: 0R; R_Axial_DIN0207_L6.3mm_D2.5mm_P10.16mm_Horizontal
R6: 2.2k; R_Axial_DIN0207_L6.3mm_D2.5mm_P10.16mm_Horizontal
R7: 10k; R_Axial_DIN0207_L6.3mm_D2.5mm_P10.16mm_Horizontal
SW1: USER_BUTTON; SW_SPST_Omron_B3F-40xx
SW2: 1101M2S3CQE2; SW_CK_1101M2S3CQE2
TP1: TP_I2S_AMP_BCLK; TestPoint_THTPad_D1.5mm_Drill0.7mm
TP2: TP_I2S_AMP_LRC; TestPoint_THTPad_D1.5mm_Drill0.7mm
TP3: TP_I2S_AMP_DIN; TestPoint_THTPad_D1.5mm_Drill0.7mm
TP4: TP_I2S_MIC_SCK; TestPoint_THTPad_D1.5mm_Drill0.7mm
TP5: TP_I2S_MIC_WS; TestPoint_THTPad_D1.5mm_Drill0.7mm
TP6: TP_I2S_MIC_SD; TestPoint_THTPad_D1.5mm_Drill0.7mm
TP7: TP_BUTTON; TestPoint_THTPad_D1.5mm_Drill0.7mm
TP8: TP_VBAT_SW; TestPoint_THTPad_D1.5mm_Drill0.7mm
TP9: TP_VBAT_SENSE; TestPoint_THTPad_D1.5mm_Drill0.7mm
TP10: TP_GND_A; TestPoint_THTPad_D1.5mm_Drill0.7mm
TP11: TP_GND_B; TestPoint_THTPad_D1.5mm_Drill0.7mm
U2: INMP441; INMP441_Round_ChipUp
U3: MAX98357A; MAX98357A_Adafruit_Input

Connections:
/+3V3: C1.1, C2.1, J4.5, R4.1, U2.1
/AMP_GAIN: R1.1, R5.1, U3.4
/AMP_SD: J3.5, R6.1
/AMP_SD_SAFE: R6.2, R7.1, U3.3
/BUTTON: C7.1, J3.4, R4.2, SW1.2, TP7.1
/GND: C1.2, C2.2, C3.2, C4.2, C5.2, C6.2, C7.2, J1.2, J4.6, J6.2, R1.2, R3.2, R5.2, R7.2, SW1.1, TP10.1, TP11.1, U2.2, U2.4, U3.2
/I2S_AMP_BCLK: J3.1, TP1.1, U3.5
/I2S_AMP_DIN: J3.3, TP3.1, U3.7
/I2S_AMP_LRC: J3.2, TP2.1, U3.6
/I2S_MIC_SCK: J4.2, TP4.1, U2.6
/I2S_MIC_SD: J4.4, TP6.1, U2.3
/I2S_MIC_WS: J4.3, TP5.1, U2.5
/SPK+: J2.1, J5.1
/SPK-: J2.2, J5.2
/VBAT_IN: J1.1, SW2.2 (B)
/VBAT_SENSE: C6.1, J3.6, R2.2, R3.1, TP9.1
/VBAT_SW: C3.1, C4.1, C5.1, J6.1, R2.1, SW2.1 (A), TP8.1, U3.1

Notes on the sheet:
RevGen / Handheld carrier board
Core voice remote verified on hardware. Charging components and charging-related behavior remain untested; first tests planned on PCB prototype.
01 BATTERY / XIAO CHARGING CONNECTION
02 XIAO ESP32S3 / GPIO INTERFACE
03 INMP441 MICROPHONE
04 PUSH-TO-TALK / WAKE
05 BATTERY VOLTAGE SENSE
06 MAX98357A / SPEAKER
07 TEST ACCESS
J6 reaches XIAO underside B+ / B- pads. Charging uses the module USB connector. SW2 isolates the cell; charging path is unverified.
J3 pins 1-6: GPIO1, 2, 3, 4, 5, 6. J4 pins 2-4: GPIO7, 8, 9. D6 / D7 UART pins and 5V stay unconnected.
VDD = 3V3; L/R = GND (left channel). Confirm header order against actual module.
Core button behavior verified. R4 adds an external pull-up; C7 filters the input.
R2 / R3 = 1M, 1%. C6 = 100nF. Divider and battery-reading firmware unverified. PCB prototype: validate before enabling alerts.
R5 fitted; R1 do not fit. J5 represents module speaker pads; confirm footprint.
Named nets join functional sections. Wires show local circuits. A2: electrical/CAD checks complete; physical fit and charging tests pending.
SD PROTECTION

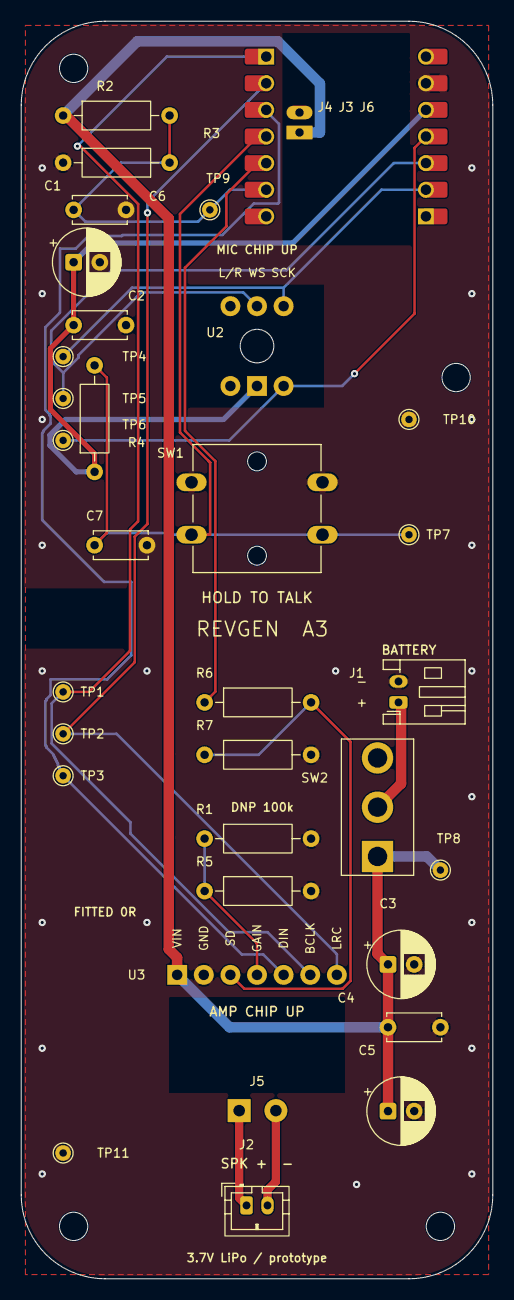
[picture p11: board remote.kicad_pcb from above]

Board: 2 copper layers, 45.0 x 120.0 mm, 39 parts (0 on the bottom side), 17 nets.

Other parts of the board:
H1, H2, H3, H4: MountingHole_2.7mm_M2.5

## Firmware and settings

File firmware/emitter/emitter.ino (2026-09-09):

/*
 * RevGen IR emitter
 * -----------------
 * Sits on the TV cabinet, mains powered, and fires IR when the backend tells
 * it to. It also learns named IR commands during a physically enabled setup
 * session; language understanding stays on the backend.
 *
 * The backend sends complete IR descriptors, so adding her air conditioner
 * later means editing config/commands.json on the server -- not reflashing a
 * board in someone else's house. That is the whole reason this is dumb.
 *
 *   subscribe  revgen/emitter/cmd     {"id":"...","steps":[...]}
 *   publish    revgen/emitter/ack     {"id":"...","ok":true}
 *   publish    revgen/emitter/status  "online" / "offline" (LWT, retained)
 *
 * A step is one of:
 *   {"type":"ir","protocol":"panasonic","address":8,"command":61,"repeat":0}
 *   {"type":"ir","protocol":"nec_raw","raw":2791701215,"repeat":0}
 *   {"type":"delay","ms":2500}
 *
 * LIBRARIES (Arduino Library Manager)
 *   IRremote        >= 4.3   Armin Joachimsmeyer
 *   PubSubClient    >= 2.8   Nick O'Leary
 *   ArduinoJson     >= 7.0   Benoit Blanchon
 *   WiFiManager     >= 2.0   tzapu
 *
 * BOARD: ESP32C3 Dev Module, USB CDC On Boot enabled
 *
 * WIRING
 *   B2 carrier: GPIO4 -> 220R -> AO3400A gate; 10k gate-to-source pull-down.
 *   4x IR LED (940nm) in parallel, EACH with its own 100R resistor, from 5V
 *   to the drain. MOSFET source to GND. Button GPIO27, receiver OUT GPIO15.
 *   Do not share one resistor across the LEDs -- they do not current-share and
 *   one ends up doing all the work.
 *   Fan them across roughly 90 degrees so aiming is designed out of the system.
 *   She cannot be relied on to point anything, which is why this box is
 *   stationary and she holds a microphone instead.
 */

#include <WiFi.h>
#include <WiFiClientSecure.h>
#include <PubSubClient.h>
#include <ArduinoJson.h>
#include <WiFiManager.h>
#include <IRremote.hpp>

// ---------------------------------------------------------------- config

/*
 * Pins differ by board. The emitter needs almost nothing -- WiFi, one output
 * for the IR driver, one for a status LED -- so any ESP32 variant works.
 * A C3 Super Mini is a fine choice and cheaper than a DevKit v1.
 */
#if CONFIG_IDF_TARGET_ESP32C3
  #define IR_SEND_PIN      4
  #define STATUS_LED_PIN   8      // onboard LED on most C3 Super Mini boards
  #define STATUS_LED_ACTIVE_LOW 1 // ...and it is wired active-low
#else
  #define IR_SEND_PIN      4
  #define STATUS_LED_PIN   2      // onboard LED on classic ESP32 DevKit v1
  #define STATUS_LED_ACTIVE_LOW 0
#endif

/*
 * Credentials live in secrets.h, which is gitignored. This repo is public.
 *
 *     cp secrets.example.h secrets.h     and fill it in
 *
 * Broker configuration and its issuing root CA are deployment-specific.
 */
#include "secrets.h"

static const char *MQTT_HOST = MQTT_HOST_STR;
static const int   MQTT_PORT = MQTT_PORT_NUM;
static const char *MQTT_USER = MQTT_USER_STR;
static const char *MQTT_PASS = MQTT_PASS_STR;
static const bool  MQTT_TLS  = MQTT_TLS_ON;

static const char *TOPIC_CMD    = "revgen/emitter/cmd";
static const char *TOPIC_ACK    = "revgen/emitter/ack";
static const char *TOPIC_STATUS = "revgen/emitter/status";

static const size_t   MAX_STEPS    = 24;
static const uint32_t MAX_DELAY_MS = 10000;
static const uint8_t MAX_REPEAT = 10;
static const uint32_t DEDUP_MS = 5UL * 60UL * 1000UL;

// If the broker is unreachable this long, reboot. The failure being guarded
// against is a wedged network stack, not a broker outage -- and a reboot fixes
// one of those. Cheaper than driving over to power-cycle it.
static const uint32_t REBOOT_AFTER_OFFLINE_MS = 10UL * 60UL * 1000UL;

// ---------------------------------------------------------------- state

WiFiClientSecure secureClient;
WiFiClient       plainClient;
PubSubClient     mqtt;

struct Step {
  bool     isDelay;
  uint32_t delayMs;
  bool     isPanasonic;   // false -> NEC raw
  uint16_t address;
  uint8_t  command;
  uint32_t raw;
  uint8_t  repeat;
};

static Step   pending[MAX_STEPS];
static size_t pendingCount = 0;
static char   pendingId[48] = {0};
static bool   hasPending = false;
static char recentIds[8][48] = {};
static uint32_t recentAt[8] = {};
static size_t recentNext = 0;

static bool alreadyAccepted(const char *id) {
  for (size_t i = 0; i < 8; i++) {
    if (recentIds[i][0] && millis() - recentAt[i] < DEDUP_MS &&
        strcmp(recentIds[i], id) == 0) return true;
  }
  return false;
}

static uint32_t lastConnectedAt = 0;

// ---------------------------------------------------------------- helpers

static void led(bool on) {
#if STATUS_LED_ACTIVE_LOW
  digitalWrite(STATUS_LED_PIN, on ? LOW : HIGH);
#else
  digitalWrite(STATUS_LED_PIN, on ? HIGH : LOW);
#endif
}

static void publishAck(const char *id, bool ok, const char *error) {
  JsonDocument doc;
  doc["id"] = id;
  doc["ok"] = ok;
  if (error) doc["error"] = error;

  char buf[192];
  size_t n = serializeJson(doc, buf, sizeof(buf));
  mqtt.publish(TOPIC_ACK, (const uint8_t *)buf, n, false);

  Serial.printf("ack %s ok=%d%s%s\n", id, ok, error ? " error=" : "",
                error ? error : "");
}

// Validate the WHOLE sequence before touching the IR LED. Refusing is always
// safer than half-executing: firing three of five steps leaves the television
// in a state nobody asked for and she has no way to undo it.
static bool parseSteps(JsonArray steps, const char **errorOut) {
  pendingCount = 0;

  for (JsonVariant value : steps) {
    if (!value.is<JsonObject>()) { *errorOut = "invalid step"; return false; }
    JsonObject step = value.as<JsonObject>();
    if (pendingCount >= MAX_STEPS) { *errorOut = "too many steps"; return false; }

    const char *type = step["type"] | "";
    Step &s = pending[pendingCount];

    if (strcmp(type, "delay") == 0) {
      if (!step["ms"].is<uint32_t>() || step["ms"].as<uint32_t>() > MAX_DELAY_MS) {
        *errorOut = "invalid delay"; return false;
      }
      uint32_t ms = step["ms"].as<uint32_t>();
      s.isDelay = true;
      s.delayMs = ms;
      pendingCount++;
      continue;
    }

    if (strcmp(type, "ir") != 0) { *errorOut = "unknown step type"; return false; }

    const char *protocol = step["protocol"] | "";
    s.isDelay = false;
    if (!step["repeat"].isUnbound() &&
        (!step["repeat"].is<uint32_t>() || step["repeat"].as<uint32_t>() > MAX_REPEAT)) {
      *errorOut = "invalid repeat"; return false;
    }
    s.repeat = step["repeat"] | 0;

    if (strcmp(protocol, "panasonic") == 0) {
      if (!step["address"].is<uint32_t>() || step["address"].as<uint32_t>() > 0xFFF ||
          !step["command"].is<uint32_t>() || step["command"].as<uint32_t>() > 0xFF) {
        *errorOut = "invalid panasonic fields";
        return false;
      }
      s.isPanasonic = true;
      s.address = step["address"].as<uint16_t>();
      s.command = (uint8_t)step["command"].as<uint16_t>();
    } else if (strcmp(protocol, "nec_raw") == 0) {
      if (!step["raw"].is<uint32_t>()) { *errorOut = "invalid raw"; return false; }
      s.isPanasonic = false;
      s.raw = step["raw"].as<uint32_t>();
    } else {
      // Refuse rather than guess. The wrong protocol at her television is
      // worse than doing nothing at all.
      *errorOut = "unsupported protocol";
      return false;
    }

    pendingCount++;
  }

  if (pendingCount == 0) { *errorOut = "empty sequence"; return false; }
  return true;
}

static void executePending() {
  Serial.printf("executing %s (%u steps)\n", pendingId, (unsigned)pendingCount);
  led(true);

  for (size_t i = 0; i < pendingCount; i++) {
    const Step &s = pending[i];

    if (s.isDelay) {
      // Keep servicing MQTT while waiting. A 2.5s post-power gap would
      // otherwise starve the keepalive and the broker drops us mid-sequence.
      uint32_t until = millis() + s.delayMs;
      while ((int32_t)(until - millis()) > 0) {
        mqtt.loop();
        delay(10);
      }
      continue;
    }

    if (s.isPanasonic) {
      IrSender.sendPanasonic(s.address, s.command, s.repeat);
      Serial.printf("  panasonic addr=0x%X cmd=0x%X\n", s.address, s.command);
    } else {
      IrSender.sendNECRaw(s.raw, s.repeat);
      Serial.printf("  nec_raw 0x%08lX\n", (unsigned long)s.raw);
    }
    delay(60);   // inter-frame gap so the receiver sees separate presses
  }

  led(false);
  Serial.println("done");
}

// ---------------------------------------------------------------- mqtt

#include "learning.h"

static void onMessage(char *topic, byte *payload, unsigned int length) {
  if (strcmp(topic, TOPIC_LEARN_ACK) == 0) { learningAck(payload, length); return; }
  if (strcmp(topic, TOPIC_CMD) != 0) return;

  JsonDocument doc;
  DeserializationError err = deserializeJson(doc, payload, length);
  if (err) {
    Serial.printf("bad json: %s\n", err.c_str());
    return;
  }

  const char *id = doc["id"] | "";
  if (!id[0] || strlen(id) >= sizeof(pendingId) ||
      doc["id"].as<JsonString>().size() != strlen(id)) {
    Serial.println("invalid command id"); return;
  }
  // QoS1 may redeliver a command after its ACK was lost. Never repeat a
  // recently accepted power toggle merely because transport retried it.
  if (alreadyAccepted(id)) { publishAck(id, true, nullptr); return; }
  if (learningActive) { publishAck(id, false, "learning mode active"); return; }
  if (hasPending) { publishAck(id, false, "busy"); return; }
  strncpy(pendingId, id, sizeof(pendingId) - 1);
  pendingId[sizeof(pendingId) - 1] = '\0';

  JsonArray steps = doc["steps"].as<JsonArray>();
  if (steps.isNull()) { publishAck(pendingId, false, "no steps"); return; }

  const char *error = nullptr;
  if (!parseSteps(steps, &error)) {
    publishAck(pendingId, false, error);
    return;
  }

  /*
   * Ack now, execute afterwards.
   *
   * The ack means "received, understood, about to execute" -- not "the
   * television reacted". It cannot mean the latter: IR is open loop, so even
   * after firing we have no idea whether anything received it. Validating the
   * whole sequence first is what makes this honest rather than optimistic.
   *
   * It also keeps us inside the backend's 2.5s ack timeout. A sequence
   * containing a 2.5s post-power wait takes longer than that to run, and she
   * would otherwise be told it failed while it was still working.
   */
  hasPending = true;
  strcpy(recentIds[recentNext], pendingId);
  recentAt[recentNext] = millis();
  recentNext = (recentNext + 1) % 8;
  publishAck(pendingId, true, nullptr);
}

static void connectMqtt() {
  if (mqtt.connected()) return;

  Serial.printf("mqtt connecting to %s:%d ... ", MQTT_HOST, MQTT_PORT);

  char clientId[32];
  snprintf(clientId, sizeof(clientId), "revgen-emitter-%06lX",
           (unsigned long)(ESP.getEfuseMac() & 0xFFFFFF));

  // Last Will: if we drop off, the broker publishes "offline" on our behalf,
  // so the backend can tell her the box is unreachable instead of confirming a
  // command that went nowhere.
  bool ok = mqtt.connect(clientId, MQTT_USER, MQTT_PASS,
                         TOPIC_STATUS, 1, true, "offline");

  if (!ok) {
    Serial.printf("failed rc=%d\n", mqtt.state());
    return;
  }

  Serial.println("connected");
  if (!mqtt.subscribe(TOPIC_CMD, 1) || !mqtt.subscribe(TOPIC_LEARN_ACK, 1) ||
      !mqtt.publish(TOPIC_STATUS, "online", true)) {
    mqtt.disconnect();
    Serial.println("MQTT startup publish/subscribe failed");
    return;
  }
  lastConnectedAt = millis();

  for (int i = 0; i < 3; i++) { led(true); delay(80); led(false); delay(80); }
}

// ---------------------------------------------------------------- setup

void setup() {
  Serial.begin(115200);
  delay(200);
  Serial.println("\nRevGen emitter");
  Serial.printf("chip=%s flash=%u heap=%u IR GPIO=%d\n", ESP.getChipModel(),
                ESP.getFlashChipSize(), ESP.getFreeHeap(), IR_SEND_PIN);

  pinMode(STATUS_LED_PIN, OUTPUT);
  led(false);

  pinMode(IR_SEND_PIN, OUTPUT);
  digitalWrite(IR_SEND_PIN, LOW);
  IrSender.begin(IR_SEND_PIN);
  digitalWrite(IR_SEND_PIN, LOW);

  // Captive portal rather than hardcoded credentials. A hardcoded SSID means
  // one router change bricks the device and someone has to drive over.
  WiFiManager wm;
  wm.setConfigPortalTimeout(180);
  if (!wm.autoConnect("RevGen-Emitter")) {
    Serial.println("wifi portal timed out, restarting");
    ESP.restart();
  }
  Serial.printf("wifi ok, ip=%s\n", WiFi.localIP().toString().c_str());

  if (MQTT_TLS) {
    // Trust the broker's issuing root CA, not a short-lived leaf certificate.
    // Credentials must not be sent over an unauthenticated TLS connection.
    if (!MQTT_CA_CERT[0]) {
      Serial.println("Set MQTT_CA_CERT in secrets.h before using TLS");
      while (true) delay(1000);
    }
    configTime(0, 0, "pool.ntp.org", "time.google.com");
    secureClient.setCACert(MQTT_CA_CERT);
    mqtt.setClient(secureClient);
  } else {
    mqtt.setClient(plainClient);
  }

  mqtt.setServer(MQTT_HOST, MQTT_PORT);
  mqtt.setCallback(onMessage);
  // PubSubClient defaults to a 256-byte buffer and SILENTLY DROPS anything
  // larger. Channel digits and multi-step volume exceed that easily. This one
  // line is the most common way this integration appears to work and does not.
  if (!mqtt.setBufferSize(2048)) {
    Serial.println("MQTT buffer allocation failed");
    ESP.restart();
  }
  mqtt.setKeepAlive(30);
  mqtt.setSocketTimeout(2);
  learningSetup();

  lastConnectedAt = millis();
}

void loop() {
  learningLoop();
  if (mqtt.connected() && WiFi.status() == WL_CONNECTED) lastConnectedAt = millis();
  if (!learningActive && millis() - lastConnectedAt > REBOOT_AFTER_OFFLINE_MS) {
    Serial.println("network offline too long, restarting");
    ESP.restart();
  }
  if (WiFi.status() != WL_CONNECTED) {
    if (!learningActive) led(millis() % 500 < 250);      // fast blink: no wifi
    delay(50);
    return;
  }

  if (!mqtt.connected()) {
    static uint32_t lastAttempt = 0;
    if (millis() - lastAttempt > 3000) {
      lastAttempt = millis();
      connectMqtt();
    }
    if (!learningActive && millis() - lastConnectedAt > REBOOT_AFTER_OFFLINE_MS) {
      Serial.println("offline too long, restarting");
      ESP.restart();
    }
    if (!learningActive) led(millis() % 1000 < 100);     // slow pulse: wifi ok, no broker
    delay(20);
    return;
  }

  mqtt.loop();

  if (hasPending) {
    executePending();
    hasPending = false;
  }

  delay(10);
}

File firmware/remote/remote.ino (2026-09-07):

/*
 * RevGen handheld — the thing she actually holds
 * ----------------------------------------------
 * Press button, speak, hear a Malayalam confirmation. That is the entire user
 * interface. There is nothing else to press.
 *
 *   wake on button
 *     -> beep          "I'm listening"        (local, instant)
 *     -> record to PSRAM, stop on silence
 *     -> beep          "got it"               (local, instant)
 *     -> POST the WAV to the backend
 *     -> play the reply                       (Malayalam, from the backend)
 *     -> deep sleep
 *
 * WHY TWO LOCAL BEEPS
 *   Measured round trip is ~3s and upload dominates, so no amount of backend
 *   work gets the spoken reply under about a second. The question she actually
 *   has is "did it hear me?", and a beep answers that at zero latency. Without
 *   it she repeats herself, and a repeated "TV on" toggles the television back
 *   off. The beeps are not decoration -- they are the fix for the single worst
 *   failure mode in the system.
 *
 * WHY RECORD-THEN-UPLOAD RATHER THAN STREAM
 *   v1 streamed audio to a websocket because the classic ESP32 could not hold a
 *   recording in memory, and drowned in hand-rolled base64 and heap
 *   fragmentation. With 8MB of PSRAM the buffer is trivial and the whole design
 *   collapses to: fill an array, POST it.
 *
 * WIRING: docs/WIRING.md
 * LIBRARIES: WiFiManager (tzapu). Everything else ships with the ESP32 core.
 *
 * IDE (XIAO ESP32S3)
 *   Board             XIAO_ESP32S3
 *   PSRAM             OPI PSRAM
 *   USB CDC On Boot   Enabled
 *   Partition Scheme  8M with spiffs (3MB APP/1.5MB SPIFFS)   <- keeps OTA
 *
 * TARGETS the legacy driver/i2s.h API, which is present in ESP32 core 2.x and
 * still present (deprecated) in 3.x. If your core has removed it, the migration
 * is to <ESP_I2S.h> and the I2SClass wrapper; the logic below is unchanged.
 *
 * The RTC amplifier-shutdown change still needs verification on hardware.
 */

#include <WiFi.h>
#include <WiFiManager.h>
#include <HTTPClient.h>
#include <WiFiClientSecure.h>
#include <ArduinoOTA.h>
#include <driver/i2s.h>
#include <driver/rtc_io.h>
#include <esp_sleep.h>

#include "secrets.h"

// ---------------------------------------------------------------- pins

#define MIC_SCK      7
#define MIC_WS       8
#define MIC_SD       9

#define AMP_BCLK     1
#define AMP_LRC      2
#define AMP_DIN      3

#define BUTTON_PIN   4     // to GND, INPUT_PULLUP. RTC-capable, so it can wake us.
#define LED_PIN      21    // onboard, active low

/*
 * MAX98357A SD_MODE, and the single most important pin for battery life.
 *
 * With BCLK stopped, the amplifier enters ~340uA standby. Holding SD low
 * instead selects ~0.6uA shutdown (MAX98357A datasheet typical IC currents).
 * Total carrier sleep current and battery life still require measurement.
 * GPIO5 is RTC-capable: retain its low output through deep sleep and release
 * that hold on wake before enabling playback.
 *
 * Set to -1 if SD is hard-wired to 3V3 (breadboard). On the PCB, give it a
 * GPIO.
 */
#define AMP_SD_PIN   5     // -1 = not controllable

#define I2S_MIC      I2S_NUM_0
#define I2S_AMP      I2S_NUM_1

// ---------------------------------------------------------------- tuning

static const int      SAMPLE_RATE      = 16000;   // Saaras works best here
/*
 * 6s cap, matching what the architecture assumed all along (192KB).
 *
 * This is the upload size lever, and upload dominates the round trip. It also
 * bounds the Saaras bill, which is charged per second of audio. She is issuing
 * one short command, not dictating -- anything longer than this is a stuck
 * button or a conversation the device should not be sending anyway.
 */
static const uint32_t MAX_RECORD_MS    = 6000;
static const uint32_t MIN_RECORD_MS    = 700;     // ignore an accidental brush
static const uint32_t SILENCE_MS       = 1200;    // quiet for this long -> she has finished
static const int      SILENCE_LEVEL    = 900;     // mean |sample| below this counts as quiet

/*
 * INMP441 gives 24-bit data left-justified in a 32-bit frame, so the raw word
 * shifted right by 8 is the true sample and >>8 again would be plain 16-bit.
 * MIC_GAIN_BITS adds gain on top of that, with saturation.
 *
 * v1 used a bare `>> 8` and produced a 24-bit value crammed into an int16,
 * which wrapped around on anything above a whisper. That is why its audio was
 * unusable. Start at 2; raise if she records quiet, lower if loud speech
 * clips.
 */
static const int MIC_GAIN_BITS = 2;

/*
 * Playback loudness.
 *
 * BEEP_VOLUME is a fraction of full scale for the local tones.
 *
 * The spoken reply is normalised instead of scaled by a fixed amount: the
 * buffer is scanned for its loudest sample and the whole clip lifted so that
 * peak lands at PLAYBACK_PEAK. Bulbul does not guarantee a consistent level
 * between phrases, and a fixed multiplier would either clip the loud ones or
 * leave the quiet ones inaudible. This way every confirmation comes out at the
 * same volume, which is what she actually needs.
 *
 * MAX_NORMALISE_GAIN stops a near-silent clip being amplified into a wall of
 * hiss -- past about 8x you are boosting the noise floor, not the voice.
 */
static const float BEEP_VOLUME        = 0.85f;
/*
 * 27000 rather than something closer to 32767, deliberately.
 *
 * Normalising to the very top means any sample that rounds up clips, and a
 * handful of clipped peaks per second is heard as a blurred, harsh voice rather
 * than as obvious distortion. A little headroom sounds noticeably cleaner and
 * costs about 1.5dB of loudness, which the amplifier's GAIN pin gives back for
 * free.
 */
static const int   PLAYBACK_PEAK      = 27000;   // out of 32767
static const float MAX_NORMALISE_GAIN = 8.0f;

static const uint32_t OTA_HOLD_MS     = 3000;              // hold button at boot
static const uint32_t OTA_WINDOW_MS   = 5UL * 60UL * 1000UL;

static const size_t RECORD_CAPACITY =
    (size_t)SAMPLE_RATE * 2 * (MAX_RECORD_MS / 1000);      // 16-bit mono

// ---------------------------------------------------------------- state

static int16_t  *recording   = nullptr;   // PSRAM
static size_t    recordedLen = 0;         // bytes
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

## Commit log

2025-02-18 Remove sample_call.py as part of code cleanup
2025-02-18 Add Flask to requirements for web framework support
2025-02-18 Update audio processing service and requirements
    - Added Google Cloud Translate to requirements
    - Set environment variable for Google credentials in app.py
    - Improved translated text handling in process_audio function
    - Updated sample_call notebook to reflect correct URL
2025-02-18 Setup Google Cloud credentials from environment variable and update API endpoint in sample notebook
2025-05-07 Implement IR Remote Mapping Application with WebSocket and ESP32 Integration
    - Added frontend HTML and JavaScript for managing IR remotes, capturing IR signals, and deploying to ESP32.
    - Created backend server using Express to handle API requests for remotes and buttons, and to manage WebSocket connections for real-time communication.
    - Integrated Serial communication with ESP32 for capturing and sending IR codes.
    - Implemented functionality to save and load IR codes from a JSON file.
    - Established a structure for capturing IR signals and deploying remotes to the ESP32.
2025-07-19 Remove obsolete files and configurations related to the IR remote project
    - Deleted gunicorn_config.py, llm.py, record.py, recording.mp3, requirements.txt, sample_call.ipynb, speech.py, and mapping-server files (app.js, index.html, server.js).
    - Removed transmitter-related files including basic_receive.ino and transmitter.ino.
    - Cleared out the requirements.txt to remove unused dependencies.
    - Deleted the recording.mp3 file and the sample Jupyter notebook.
    - Removed the old transmitter.ino file and replaced it with a new structure for better organization.
    - Added a new signal.json file to store remote configurations.
2025-08-24 Implement ESP32 OpenAI Realtime API Client with I2S audio capture and WebSocket communication
2026-08-04 Add ESP32 OpenAI Realtime API Client with I2S audio capture and WebSocket communication; include IR remote button configurations and documentation assets
2026-08-04 fix: update README and configuration for clarity on device token usage and deployment settings
2026-08-04 fix: enhance logging and clarify device handling in intent processing
2026-08-04 Add tests for Emitter contract and document BOM for hardware setup
    - Introduced a new test suite for the Emitter contract to validate the JSON payloads sent to the firmware, ensuring compatibility with the expected command structure.
    - Added comprehensive tests for various device commands, including Panasonic and NEC protocols, step shapes, and payload size constraints.
    - Created a detailed Bill of Materials (BOM) document outlining the necessary components for building the emitter, including recommendations for initial and later purchases.
    - Included wiring instructions and first-run setup for the firmware, ensuring clarity for future developers and users.
2026-08-04 Refactor BOM documentation and add capture firmware
    - Updated BOM.md to clarify parts needed for different phases, including already owned components and ordered items.
    - Added a new README.md for the capture firmware, detailing its purpose and usage for recapturing remote codes.
    - Implemented capture.ino to read IR codes from existing remotes, including functionality for sweeping Panasonic command space for discrete codes.
    - Enhanced error handling in capture firmware to warn about duplicate captures.
    - Improved clarity in comments and documentation throughout the codebase.
    [capture.ino]
2026-08-05 feat: add wiring documentation for emitter and voice unit setup
2026-08-14 Add firmware for RevGen handheld device with audio recording and playback features
    - Implemented main functionality in remote.ino for audio recording, processing, and network communication.
    - Created README.md to document device setup, operation, and audio handling.
    - Added secrets.example.h for configuration management, including backend URL and OTA password.
    - Introduced self-test sketch to verify board functionality, PSRAM availability, and WiFi connectivity.
2026-08-14 Add audio test sketch and OTA upload scripts for firmware updates
    - Introduced `audiotest.ino` to validate speaker functionality with a three-stage audio test.
    - Added `ota_upload.ps1` script for OTA updates without mDNS, ensuring reliable firmware uploads via IP address.
    - Created a duplicate `ota_upload.ps1` in the `remote` directory for consistency across firmware components.
2026-08-14 handheld working on hardware
    - hold-to-talk with release detection and 300ms tail
    - second press cancels: polled during download/playback, reboot during upload
    - wifi channel/BSSID/IP cached in RTC memory, connects during recording
    - OTA + maintenance mode; USB stays awake 15s on cold boot for flashing
    - fixed DMA buffer looping the beep through every recording
    - normalised playback with headroom, 24kHz TTS for consonant clarity
    - record only on button wake, RTC pullup to stop phantom wakes
    [remote.ino]
2026-08-14 pcb: carrier board netlist and layout rules; amp shutdown for battery life
2026-08-14 pcb: machine-checkable netlist for schematic verification
2026-09-07 Enhance emitter firmware and backend integration
    - Updated README.md with detailed hardware setup instructions and development targets for ESP32-C3.
    - Improved emitter.ino to handle malformed numeric fields, reject duplicate commands, and implement TLS with CA certificate validation.
    - Added validation for command IDs and improved error handling in MQTT message processing.
    - Introduced deduplication logic for recent command IDs to prevent duplicate QoS1 delivery.
    - Created emitter_protocol.py for shared limits and validation logic between backend and emitter.
    - Implemented tests for emitter link and command validation in test_emitter_link.py.
    - Added check_emitter.py tool for broker access a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
    [emitter.ino, remote.ino]
2026-09-09 Add TTS regression tests, emitter circuit review, and learning mode implementation
    - Introduced a comprehensive test suite for TTS functionality, covering cache behavior, audio synthesis, and error handling.
    - Documented the emitter circuit recovery process, highlighting discrepancies with original schematics and providing revised specifications.
    - Added a Gerber recovery document detailing the original PCB layout and copper findings.
    - Implemented a learning mode for the emitter, allowing users to capture and save IR commands via a web interface.
    - Created a dedicated HTML page for the learning mode with input validation and user feedback.
    - Developed a Node.js test script using Playwright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
    [emitter.ino, learning.h]
2026-09-09 pcb: track KiCad sources, fab outputs and verification evidence
    pcb/ was excluded wholesale by a single bare `pcb/` ignore rule, so none of
    the hardware design had ever been under version control. Track it, with two
    hazards handled explicitly.
    Nested repo: pcb/remote/.history is a Trace / VS Code local-history autosave
    repo. Git does not recurse into a directory holding .git, so `git add pcb/`
    would have recorded it as a gitlink (mode 160000) -- a submodule pointer with
    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
    [adafruit-max98357.brd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]
2026-09-09 Remove obsolete routing scripts and related functionality
    - Deleted `route_a3.py`, which contained A3 routing helpers for KiCad.
    - Removed `route_remote.ps1`, a PowerShell script for executing routing tasks.
    - Eliminated `set_dsn_rules.py`, which was responsible for setting DSN rules for the placement file.
    These changes streamline the codebase by removing unused and outdated routing tools.
    [mask-diagnostic.kicad_pcb, mask-repair-test.kicad_pcb, placement.dsn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]
